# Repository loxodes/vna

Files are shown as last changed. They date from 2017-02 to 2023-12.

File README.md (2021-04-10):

# Open Hardware Vector Network Analyzer
I'm developing a proof of concept two port microwave vector network analyzer. The project is under developent.
[Ongoing documentation and logs are located on a hackaday.io project page.](https://hackaday.io/project/26213-vector-network-analyzer)

## Usage
This project is still under development, y'all probably don't want to try reproducing it yet.
Two port measurements to 14 GHz work, a redesign for operation out to 36 GHz is in progress.

## Hardware Design
See `breakouts` and `hardware` for various modules developed for the network analyzer.
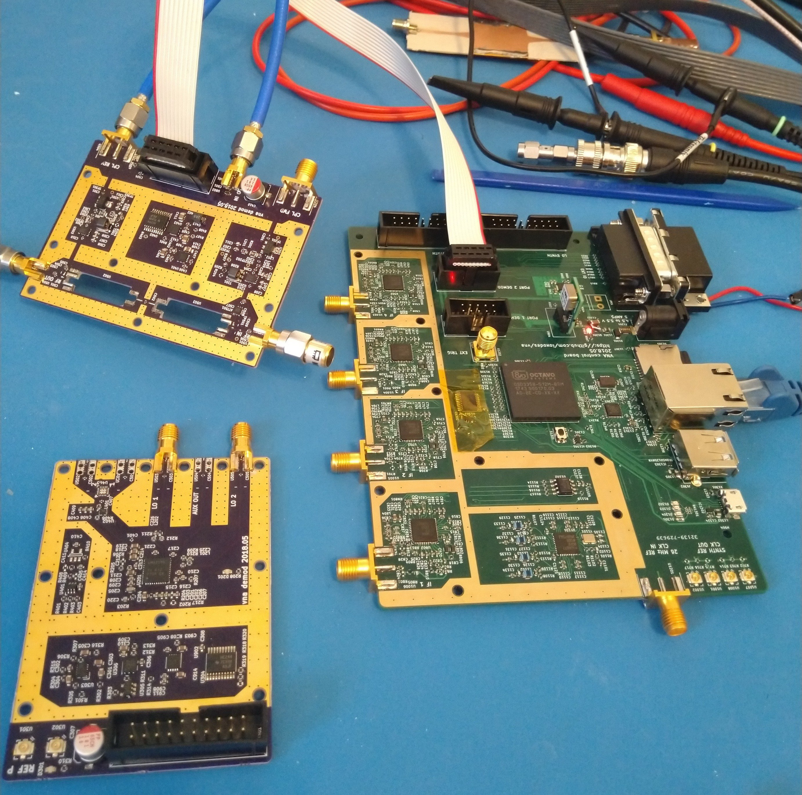
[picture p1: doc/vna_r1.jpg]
picture of VNA R1

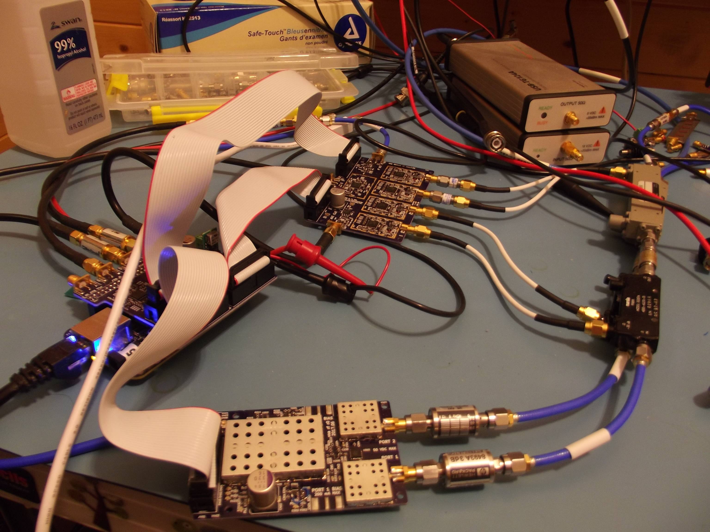
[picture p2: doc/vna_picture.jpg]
picture of VNA

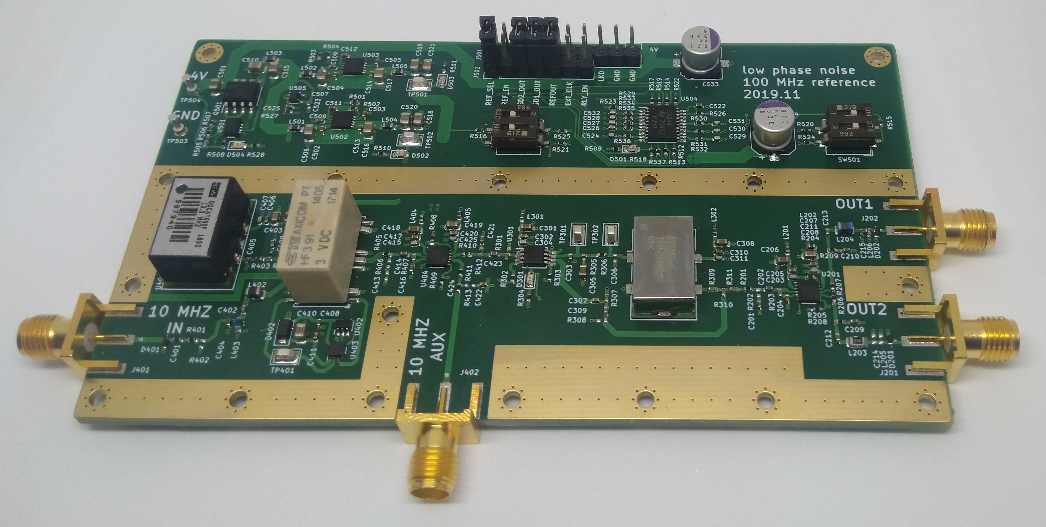
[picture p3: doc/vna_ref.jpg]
picture of VNA reference

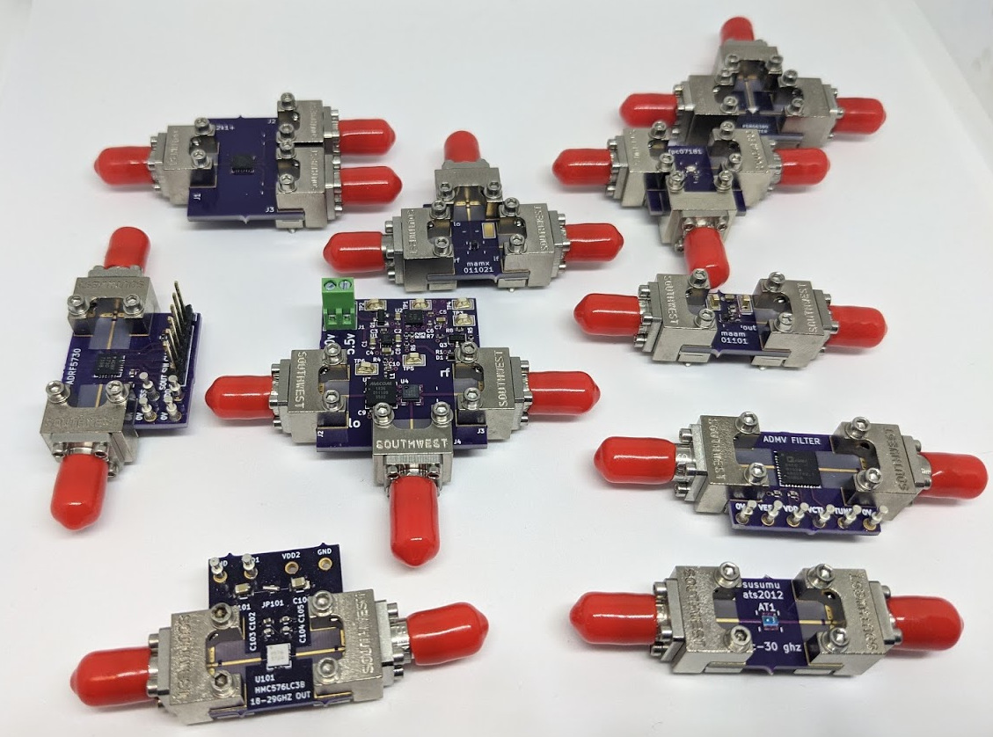
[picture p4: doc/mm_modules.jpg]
picture of mm modules


## Software Design
See the `software` directory for scraps of software written for testing VNA modules. 

## License
Unless otherwise noted, all work is under a MIT license.

## Contact
Feel free to contact me at arcticmicrowave@gmail.com or loxodes on irc.freenode.net

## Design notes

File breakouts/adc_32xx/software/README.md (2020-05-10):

LiteX SoC test platform for ADC32XX ADC and HyperRAM on ECP5\_EVN

On ECP5 EVN,
	Populate R34 and R35 then run https://github.com/trabucayre/fixFT2232\_ecp5evn for serial to work
	Swap R100 and R105 for 3.3V IO

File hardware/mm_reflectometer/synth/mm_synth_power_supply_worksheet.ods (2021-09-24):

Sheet: Current Draw, Toplevel
+5.5V | Current (mA) | Regulator Type |  | TODO:
5VA | 642.523 | Linear |  | -Add test points for CFG0..2 pins on FPGA
-5V35 | 173.02 | Linear |  | -See ECP5 checklist, recommendations for pullup/down on PROGRAMN
LM3880MF-1AF |  | RF regulator sequencing
SYZYGY | 500
Total: | 1315.543 | mA
 | 7235.4865 | mW
+4V | Current (mA) | Regulator Type
+3.3P | 697 | Linear
+3.3VA | 209.876 | Linear
+15V | 0 | Switching
LM3880MF-1AF |  | Control regulator sequencing
+1V1 | 211.75 | Switching
+3V3 | 501.703125 | Switching
Total | 1620.329125 | mA
 | 6481.3165 | mW
+9V
 | Current (mA) | Efficiency | 9V Current (mA)
+4V | 1315.543 | 0.9 | 649.650864197531
+5.5V | 1620.329125 | 0.9 | 1100.22347993827
Total | 1749.8743441358 | mA
Power | 15748.8690972222 | mW
So, total current 2A
Total power 18W

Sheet: Current Draw, Digital
+3V3 |  | TLV62569DRL, switching off +4V
 | current (mA) | notes
TLV0025 | 67 | +2.5V
TLV0018 | 60.5 | +1.8V
PMOD1 | 100
PMOD2 | 100
ECP5 VCCIO7 | 0.5 | Static power, TBD dynamic
ECP5 VCCIO1 | 0.5 | Static power, TBD dynamic
ECP5 VCCIO8 | 0.5 | Static power, TBD dynamic
ECP5 VCCIO2 | 0.5 | Static power, TBD dynamic
93LC56C | 2
W25Q32JVSS | 25
FTDI2232HQ VCCIO, VPHY, VPLL | 130
Total: | 486.5
+1V1 |  | TLV62569DRL, switching off +4V
 | current (mA) | notes
ECP5 Vcc, Static | 116 | Static power, -45F sized max
ECP5 Vcc, Dynamic | 500 | TBD
Total: | 616
+2V5 |  | TLV70025_SOT353, linear off +3.3V
 | current (mA) | notes
ECP5 VCCAUX | 17 | Static power, -45F sized max
 | 50 | TBD
Total: | 67
+1V8 |  | TLV70025_SOT353, linear off +1.8V
 | current (mA) | notes
IS66WVH16M8ALL | 60 | max active read/write current
VCCIO6 | 0.5 | TBD dynamic
Total: | 60.5
VCC_SZY
 | 750

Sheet: Current Draw, RF
+3.3P |  | ADP7158ACPZ-3.3-R7, linear off +4V
 | current (mA) | notes
ABLNO-100 | 35 | switched off by REF_EN
LMX2820 | 590 | varies with mode of operation, 590 mA max typical
LTC6957xMS-2 | 72
Total: | 697
+3.3VA |  | ADP7158ACPZ-3.3-R7, linear off +4V
 | current (mA) | notes
MAAM-11026 | 76 | lowband
MAAM-011101 | 45 | midband
MAAM-011101 | 45 | higband
ADRF5730 | 0.5
TLV9151IDCKR | 1 | pll buffer
LMT86DCK | 1
AD7298 | 6
ADRF5042 | 0.37
LTC5596 | 35
LMT86DCK | 0.006
Total: | 209.876
5VA |  | ADM7172ACPZ-5.0-R7, linear off +5V
 | current (mA) | notes
ADMV8416 | 1 | midband
ADMV8432 | 1 | highband
XX1000-QT | 265 | highband
MAAM-011109 | 170
MAAM-011109 | 170
TS5A23166 | 1
LTC2636IDE | 1 | dac
TLV9151IDCKR | 0 | stg1 and stg2 output gain adjust dac buffer
1-1462051-2 | 33 | bistable
TMUX6136 | 0.023
DRV8837C | 0.5
Total: | 642.523
-5VA |  | TPS72301DB
 | current (mA) | notes
ADMV8416 | 1 | midband
ADMV8432 | 1 | highband
XX1000-QT | 50 | highband
MAAM-011109 | 50 | output stg1 | TBD
MAAM-011109 | 50 | output stg2 | TBD
TLV9151IDCKR | 5 | output stg1
TLV9151IDCKR | 5 | output stg2
TLV9151IDCKR | 10 | stg1 and stg2 output gain adjust dac buffer
TMUX6136 | 0.02
Total: | 171.02
-3V3 |  | TPS72301DB
 | current (mA) | notes
ADRF5042 | 1
ADRF5730 | 1
Total: | 2
+15V | LT3494, switching off +4V
 | current (mA) | notes
TLV9151IDCKR | TBD | midband filter Vt
TLV9151IDCKR | TBD | highband filter Vt
Total: | 0
-5.35V |  | LM27761, max 250 mA, switching off +5.5V
-3.3V | 2
-5V | 171.02
Total: | 173.02

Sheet: Sequencing
Triggered off PGOOD_SWITCHING
RF Sequencing |  | (sequenced internally) |  | (sequenced internally)
 | ADRF | MAAM-011109 | ADMV | XX1000-QT
3.3VP | 3.3VA | -5V | 5V | -5V
 | -3.3V | 5V | -5V | 5V
 |  |  | 15V
Digital Sequencing, triggered off 15V
1.2V
3.3V, 2.5V, 1.8V
FPGA Reset |  | Sequence 5V before 3.3V
TODO:
Change U1303 VDRIVE from 3.3VA to 3.3V?
Verify digital outputs from RF components to FPGA input sequencing

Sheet: Dropout Calculator
TLV62569DRL Dropout
Vout | 3.3
Iout | 0.5
Rdson | 0.15
Ri | 0.2
Vin_min | 3.475

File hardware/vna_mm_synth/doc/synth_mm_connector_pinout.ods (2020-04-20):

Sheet: J1302
2019.12.25
J1302 Pinout | (SYZYGYish) | All digital IO lines are 3.3V CMOS high impedance unless otherwise noted.
Pin Number | Name | Direction (FPGA) | Description | Notes
1 | SDA | Open collector bidirectional | I2C Data
3 | SCL | Open collector bidirectional | I2C Clock
5 | PLL_SDI | Output | LMX2595 SDI | Data clocked on rising edge of SCK, MSB first
7 | PLL_SCK | Output | LMX2595 SCK
9 | PLL_CE | Output | LMX2595 Chip Enable | Active high
11 | PLL_CSB | Output | LMX2595 Chip Select | Active low
13 | PLL_SDO | Input | LMX2595 SDO | Readback on rising edge of SCK
15 | MAAM_VC_EN | Output | Output driver VVA EN | Active high, enables both MAAM-011109 VVAs
17 | FILT_~SYNC | Output | Filter VT DAC Chip Select | Active low frame sync (CSB)
19 | TBD | TBD | TBD | TBD
21 | FILT_BANDSEL | Output | Midband filter band select | Logic high selects low band (7-12 GHz)
23 | AMP_~SYNC | Output | Driver amp DAC Chip Select | Active low frame sync (CSB)
25 | AMP_~CLR | Output | Async DAC clear input | Low sets VVA and filter VT DACs to default values
27 | TBD | TBD | TBD | TBD
29 | AMP_SCK | Output | DAC SPI Clock
31 | AMP_SDI | Output | DAC SPI Data | Data clocked on falling edge of SCK, MSB first
33 | VPP | Power In | 9V power input | Max draw TBD
35 | VPP | Power In | 9V power input | Max draw TBD
37 | VPP | Power In | 9V power input | Max draw TBD
39 | 3.3VA | Power out | 3.3V power output | Max draw TBD
2 | +5V | Power in | Voltage for resistor ID | Unused
4 | R_GA | Voltage out | Board ID | Unused
6 | ATT_SDI | Output | Attenuator SERIN | Data clocked on rising edge of SCK, MSB first
8 | ATT_SCK | Output | Attenuator SCK
10 | ATT_LE | Output | Attenuator Latch | Pulse latch enable high following byte
12 | ATT_SDO | Input | Attenuator SEROUT | Remove and relegate to test point?
14 | SEQ_WP | Output | Write protect sequencing chip | Write protect disabled when WP is pulled to ground
16 | LOWBAND_EN | Output | Enable lowband amplifier | High enables amplifier.
18 | MIDBAND_EN | Output | Enable midband amplifier | High enables amplifier.
20 | HIGHBAND_EN | Output | Enable highband multiplier | High enables multiplier.
22 | SEQ_POW_ON | Output | LTC2937 ON | High enables amplifier.
24 | SW1_V1 | Output | Mid/high select switch V1 | V12 - 00: NC, 01: Midband, 10: Highband, 11: J701 rf test point
26 | SW1_V2 | Output | Mid/high select switch V2
28 | SW2_V1 | Output | Low/mid select switch V1 | V12 – 00: Midband, 01: Mid filt bypass, 10: lowband, 11: J702 rf test point
30 | SW2_V2 | Output | Low/mid select switch V2
32 | SW3_HIGH_SEL | Output | ADRF5020 CTRL input | High selects mid/lowband, low selects highband
34 | CONN_REF_P | RF Output | LVDS 100 MHz reference
36 | CONN_REF_N | RF Output | LVDS 100 MHz reference
38 | VPP | Power In | 9V power input | Max draw TBD
40 | 3V3 | Power in | No connect | No connect

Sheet: I2C Addresses
vna_mm_synth I2C addresses
 | (7 bit)
Chip | Address | Description | Notes
24LC512 | 0x80 | EEPROM | ADDR is LLL
LTC2937 | 0x44 | Power sequencing | ASEL is ZZZ
LM73 | 0x73 | Temperature sensor | ADDR is L
ADS1115IDGS | 0x72 | ADC (vdet, vtune) | ADDR is L

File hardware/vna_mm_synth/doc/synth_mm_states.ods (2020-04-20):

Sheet: Scratchpad
Program in a sequence, at each frequency:
Section | Field | Bits | Notes
PLL | VCO divider
PLL | A mux/PD | 3
PLL | B mux/PD | 3
PLL | N | 19
PLL | FRAC_NUM | 32
PLL | FRAC_DENOM | 32
PLL | A power | 6 | Output power setting for RfoutA
PLL | B power | 6 | Output power setting for RfoutB
PLL | MASH_ORDER | 3 | Sets MASH order
PLL | MASH_RESET_N | 1 | Set to 0 for integer mode, 1 for fractional
PLL | OUT_ISET | 2 | Output amplifier bias? 0 is maximum power.
PLL | DBLR_IBIAS | 1 | Set to 1572 for f < 15 GHz, and 3115 for f > 15 GHz
PLL | VCO2X_EN | 1 | 0 disables internal doubler, 1 enables doubler
PLL | SEG1_EN | 1 | Enable driver buffer for CHDIV > 2
PLL | CHDIV | 5 | VCO divider value
VVA | MAAM_VC_EN | 1
VVA | U1003 Vc | 10
VVA | U1004 Vc | 10
Filter | Filter band | 1
Filter | Filter vtune | 10
Digital attenuator | Atten value | 7
Switch | SW1 | 2
Switch | SW2 | 2
Switch | SW3 | 1
So, load up default mask for all registers
 |  | 159 | 19.875 | 32 bytes/state?
 |  |  |  | 16384
So, aiming for 1000 points/second.
1 ms/point
100 microseconds PLL lock
switch settling?
amplifier settling?
attenuator settling?
74AHC244 max speed?

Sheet: Initialization
vna_mm_synth program states
Power on
Enable power rails
Wait for sequencing
Initialize VVA
Initialize attenuator
Initialize PLL

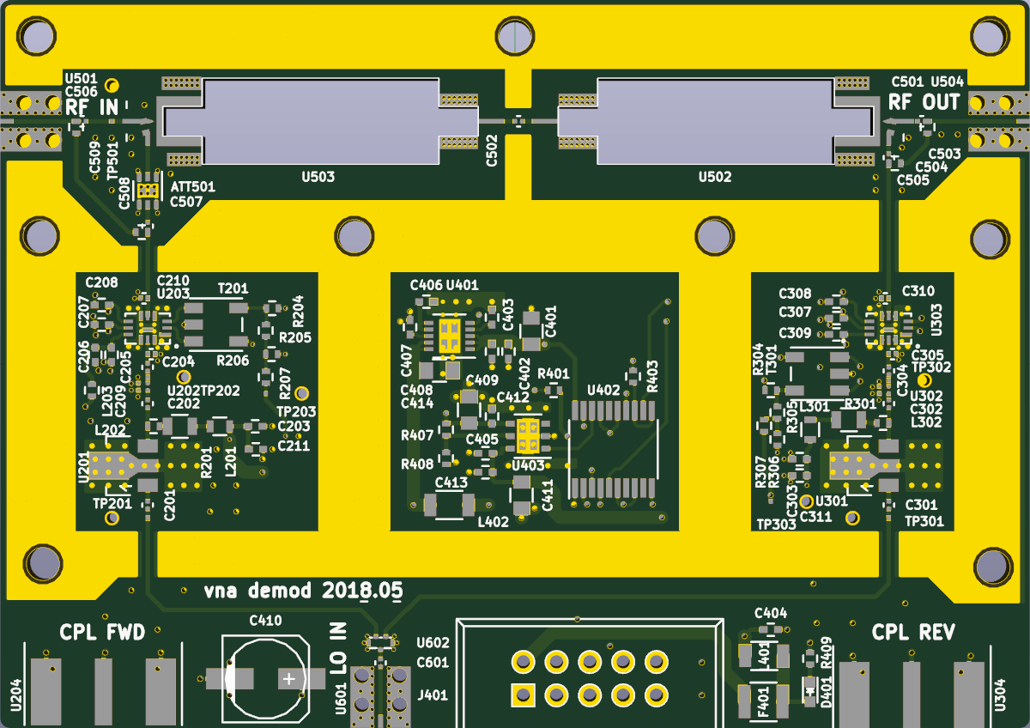
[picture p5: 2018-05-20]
hardware/vna_rev1/vna_r1_demod/vna_r1_demod.png

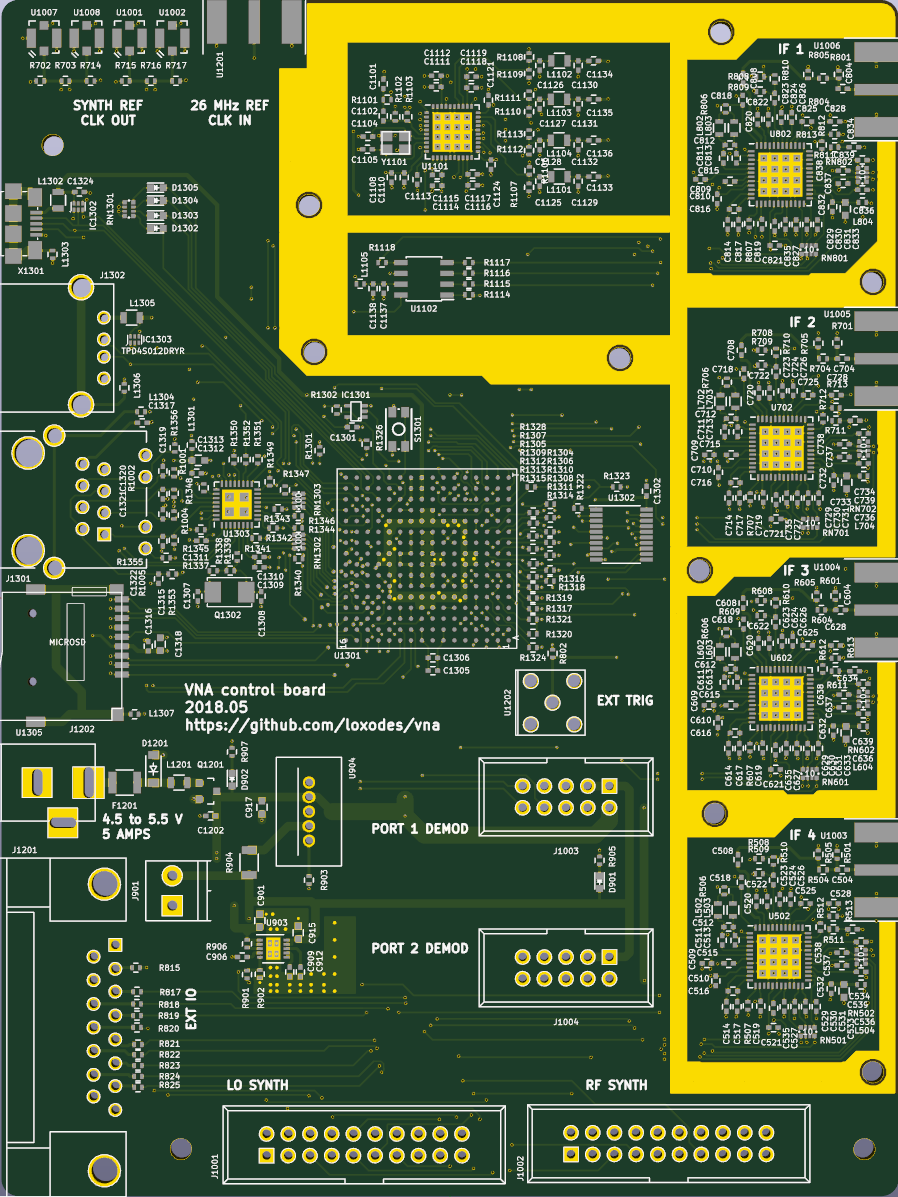
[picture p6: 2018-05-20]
hardware/vna_rev1/vna_r1_controller/vna_r1.png

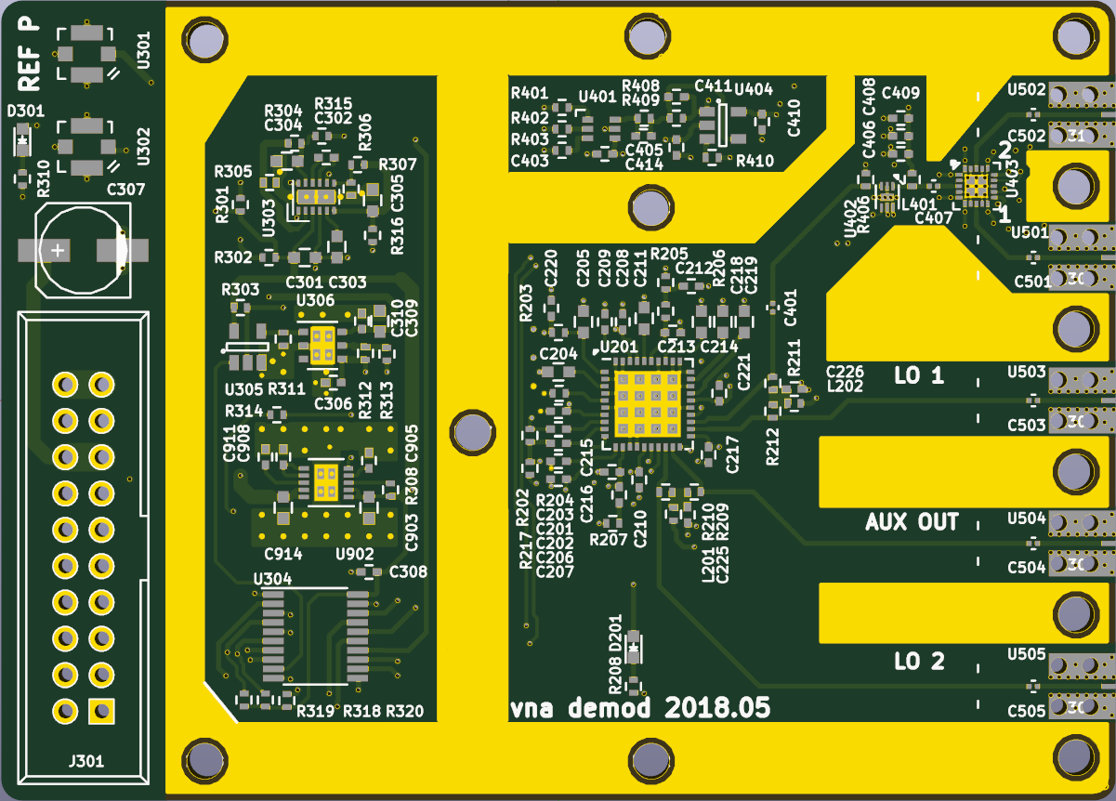
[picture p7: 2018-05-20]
hardware/vna_rev1/vna_r1_synth/vna_r1_synth.png

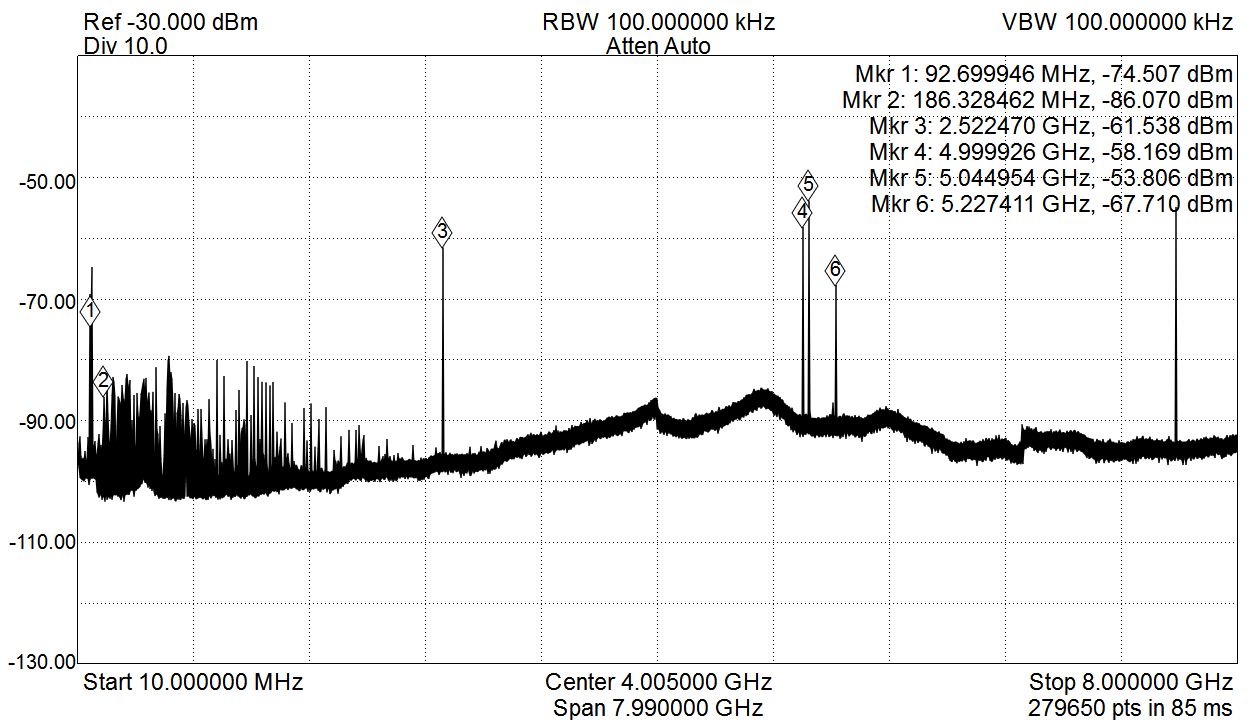
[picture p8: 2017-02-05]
doc/eevblog_forum_pictures/mixer_rf.png

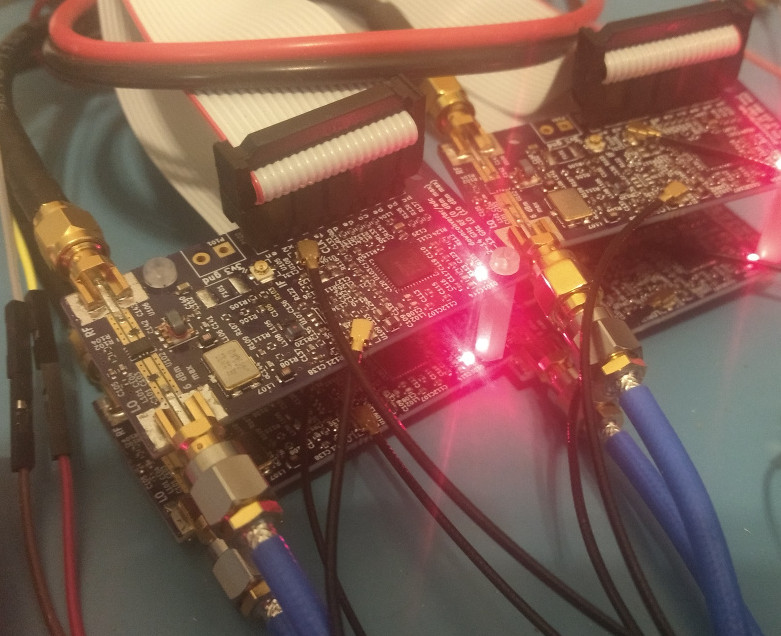
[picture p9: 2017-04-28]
doc/demod.jpg

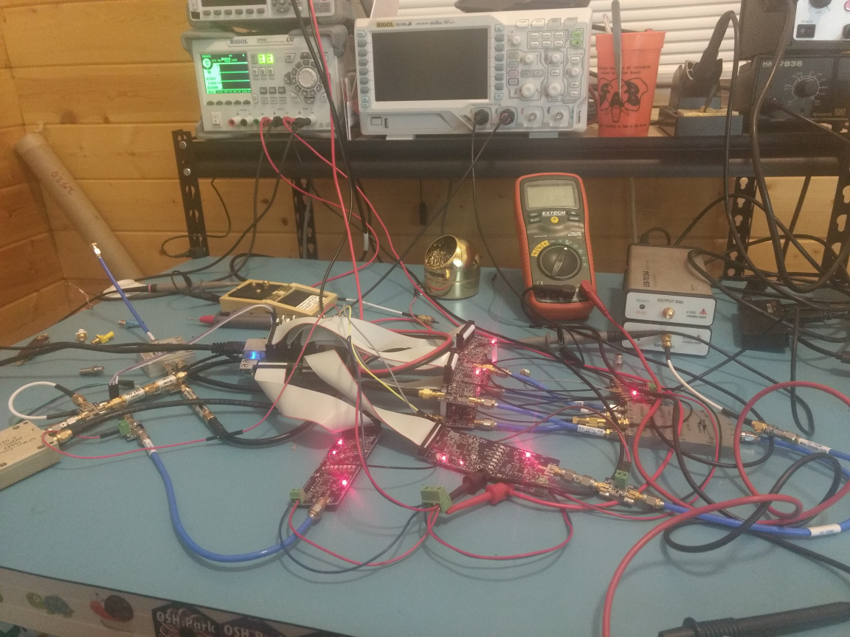
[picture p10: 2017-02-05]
doc/vna_pictures/entire_vna.jpg

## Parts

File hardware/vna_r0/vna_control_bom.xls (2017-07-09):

Item | Qty | Reference(s) | Value | Footprint | Digi-Key Part Number | Board
1 | 23 | C201, C203, C206, C207, C208, C209, C212, C214, C216, C219, C220, C221, C222, C223, C224, C225, C226, C227, C418, C421, C423, C425, C427 | 100 nF | Capacitors_SMD:C_0402 | 490-14603-1-ND | vna_control
2 | 3 | C202, C204, C205 | 22 pF | Capacitors_SMD:C_0402 | 490-8589-1-ND | vna_control
3 | 5 | C210, C211, C215, C217, C218 | 10 nF | Capacitors_SMD:C_0402 | 490-4516-1-ND | vna_control
4 | 1 | C213 | 220 nF | Capacitors_SMD:C_0402 | 490-5418-1-ND | vna_control
5 | 9 | C401, C402, C403, C413, C414, C415, C416, C420, C422 | 10 uF | Capacitors_SMD:C_0603 | 490-10474-1-ND | vna_control
6 | 10 | C404, C405, C406, C407, C408, C409, C410, C411, C412, C424 | 1 uF | Capacitors_SMD:C_0402 | 490-13339-1-ND | vna_control
7 | 1 | C426 | 100 pF | Capacitors_SMD:C_0402 | 490-5922-1-ND | vna_control
8 | 1 | C428 | 100 uF | Capacitors_SMD:c_elec_10x10 | P16463CT-ND | vna_control
9 | 2 | D301, D302 | LED | LEDs:LED_0603 | 475-2486-1-ND | vna_control
10 | 1 | F301 | PTC/MF-NSMF200-2 | Resistors_SMD:R_1206 | MF-NSMF200-2CT-ND | vna_control
11 | 3 | J301, J302, J303 | CONN_02X10 | Connect:IDC_Header_Straight_20pins | 1175-1612-ND | vna_control
11 | 3 | J301, J302, J303 | CONN_02X10 | Connect:IDC_Header_Straight_20pins | 1175-1422-ND | vna_control
11 | 1 | J301, J302, J303 | CONN_02X10 | Connect:IDC_Header_Straight_20pins | MD20R-5-ND | vna_control
12 | 2 | J304, J306 | CONN_02X23 | Pin_Headers:Pin_Header_Straight_2x23 | S2011EC-23-ND | vna_control
13 | 2 | J305, J401 | CONN_01X02 | Terminal_Blocks:TerminalBlock_Pheonix_PT-3.5mm_2pol | 277-1721-ND | vna_control
14 | 1 | J307 | BARREL_JACK | Connect:BARREL_JACK | CP-002A-ND | vna_control
14 | 1 | J307 | BARREL_JACK | Connect:BARREL_JACK | 62-1244-ND | vna_control
15 | 2 | L201, L401 | L_Small | Resistors_SMD:R_0805 | P0.0ACT-ND | vna_control
16 | 1 | Q301 | DMG2305UX | TO_SOT_Packages_SMD:SOT-23 | DMG2305UX-13 | vna_control
17 | 1 | R201 | 51 | Resistors_SMD:R_0402 | 311-2189-1-ND | vna_control
18 | 15 | R202, R203, R204, R205, R206, R207, R208, R209, R210, R211, R216, R217, R218, R405, R406 | 10k | Resistors_SMD:R_0402 | 311-10KJRCT-ND | vna_control
19 | 6 | R212, R213, R214, R215, R301, R302 | DNP | Resistors_SMD:R_0402 | DNP | vna_control
20 | 3 | R303, R401, R402 | R_Small | Resistors_SMD:R_0402 | 1276-3480-1-ND | vna_control
21 | 2 | R304, R305 | 1k | Resistors_SMD:R_0402 | 311-1.0KJRCT-ND | vna_control
22 | 1 | R403 | 390 | Resistors_SMD:R_0402 | 311-390JRCT-ND | vna_control
23 | 1 | R404 | R_Small | Resistors_SMD:R_1206 | MF-NSMF200-2CT-ND | vna_control
24 | 1 | U201 | AD9577 | Housings_DFN_QFN:QFN-40-1EP_6x6mm_Pitch0.5mm | AD9577BCPZ-R7 | vna_control
25 | 1 | U202 | CONN_SMA_2GND | vna_footprints:734120110_ufl_umc | WM5587CT-ND | vna_control
26 | 5 | U301, U302, U303, U304, U305 | CONN_SMA | vna_footprints:732511150_sma_thin | WM5534-ND | vna_control
27 | 3 | U401, U402, U403 | ADP7158 | Housings_DFN_QFN:DFN-10-1EP_3x3mm_Pitch0.5mm | ADP7158ACPZ-3.3-R7CT-ND | vna_control
28 | 1 | U404 | OKR-T/3-W12-C | vna_footprints:OKRT3_C72 | 811-2115-5-ND | vna_control
29 | 1 | U405 | TPS2041B | TO_SOT_Packages_SMD:SOT-23-5 | 296-21263-1-ND | vna_control
30 | 1 | U406 | LTC1983 | TO_SOT_Packages_SMD:SOT-23-6 | LTC1983ES6-5#TRMPBFCT-ND | vna_control
31 | 1 | Y201 | 26 MHz 7M-26.000MEEQ-T | vna_footprints:crystal_FA238-TSX3225 | 887-1327-1-ND | vna_control

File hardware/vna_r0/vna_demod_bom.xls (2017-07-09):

Item | Qty | Reference(s) | Value | Footprint | Digi-Key Part Number | Board
1 | 58 | C201, C215, C303, C307, C308, C316, C317, C318, C319, C320, C323, C325, C326, C327, C329, C503, C507, C508, C516, C517, C518, C519, C520, C523, C525, C526, C527, C529, C603, C607, C608, C616, C617, C618, C619, C620, C623, C625, C626, C627, C629, C703, C707, C708, C716, C717, C718, C719, C720, C723, C725, C726, C727, C729, C801, C803, C806, C807 | 100 nF | Capacitors_SMD:C_0402 | 490-14603-1-ND | vna_demod
2 | 7 | C202, C204, C205, C206, C207, C209, C218 | 1 uF | Capacitors_SMD:C_0402 | 490-13339-1-ND | vna_demod
3 | 9 | C203, C208, C212, C216, C217, C328, C528, C628, C728 | 10 uF | Capacitors_SMD:C_0603 | 490-10474-1-ND | vna_demod
4 | 1 | C210 | DNP | Capacitors_SMD:C_0402 | DNP | vna_demod
5 | 1 | C211 | 1800 pF | Capacitors_SMD:C_0402 | 490-12535-1-ND | vna_demod
6 | 1 | C213 | 390 pF | Capacitors_SMD:C_0402 | 490-5871-1-ND | vna_demod
7 | 1 | C214 | 68 nF | Capacitors_SMD:C_0402 | 490-12709-1-ND | vna_demod
8 | 25 | C219, C220, C304, C306, C314, C321, C322, C504, C506, C514, C521, C522, C604, C606, C614, C621, C622, C704, C706, C714, C721, C722, C802, C804, C805 | 10 nF | Capacitors_SMD:C_0402 | 490-4516-1-ND | vna_demod
9 | 12 | C301, C302, C305, C501, C502, C505, C601, C602, C605, C701, C702, C705 | 10 pF | Capacitors_SMD:C_0402 | 712-1253-1-ND | vna_demod
10 | 16 | C309, C311, C312, C315, C509, C511, C512, C515, C609, C611, C612, C615, C709, C711, C712, C715 | 100 pF | Capacitors_SMD:C_0402 | 490-5922-1-ND | vna_demod
11 | 4 | C310, C510, C610, C710 | 120 pF | Capacitors_SMD:C_0402 | 490-1292-1-ND | vna_demod
12 | 4 | C313, C513, C613, C713 | 2.2 nF | Capacitors_SMD:C_0402 | 490-1305-1-ND | vna_demod
13 | 4 | C324, C524, C624, C724 | 1 nF | Capacitors_SMD:C_0402 | 490-1303-1-ND | vna_demod
14 | 1 | C402 | 22 uF | Capacitors_SMD:c_elec_10x10 | P16463CT-ND | vna_demod
15 | 3 | D201, D401, D402 | RED | LEDs:LED_0603 | 475-2486-1-ND | vna_demod
16 | 4 | H401, H402, H403, H404 | MOUNTING_HOLE | Mounting_Holes:MountingHole_2-7mm | DNP | vna_demod
17 | 5 | J301, J501, J601, J701, J201 | BMI-S-209 | Shielding_Cabinets:Laird_Technologies_BMI-S-209-F_29.36x18.50mm | 903-1185-ND | vna_demod
18 | 5 | J301, J501, J601, J701, J201 | BMI-S-209 | Shielding_Cabinets:Laird_Technologies_BMI-S-209-F_29.36x18.50mm | 903-1212-1-ND | vna_demod
19 | 2 | J401, J402 | CONN_02X10 | Connect:IDC_Header_Straight_20pins | 1175-1612-ND | vna_demod
20 | 2 | J401, J402 | CONN_02X10 | Connect:IDC_Header_Straight_20pins | 1175-1422-ND | vna_demod
21 | 2 | J403, J404 | CONN_01X01 | Pin_Headers:Pin_Header_Straight_1x01 | DNP | vna_demod
22 | 2 | L201, L202 | 22 nH | Resistors_SMD:R_0402 | 490-6787-1-ND | vna_demod
23 | 8 | L301, L304, L501, L504, L601, L604, L701, L704 | BLM15GG471 | Resistors_SMD:R_0402 | 490-5198-1-ND | vna_demod
24 | 8 | L302, L303, L502, L503, L602, L603, L702, L703 | 6.8 uH BRL1608T6R8M | Resistors_SMD:R_0603 | 587-2902-1-ND | vna_demod
25 | 1 | L801 | 6.8 uH | Resistors_SMD:R_0603 | 587-2902-1-ND | vna_demod
26 | 50 | R201, R202, R205, R206, R207, R209, R210, R302, R303, R308, R309, R310, R311, R312, R313, R314, R315, R401, R402, R502, R503, R508, R509, R510, R511, R512, R513, R514, R515, R602, R603, R608, R609, R610, R611, R612, R613, R614, R615, R702, R703, R708, R709, R710, R711, R712, R713, R714, R715, R810 | 1k | Resistors_SMD:R_0402 | 311-1.0KJRCT-ND | vna_demod
27 | 5 | R203, R316, R516, R616, R716 | JMP | Resistors_SMD:R_0402 | 1276-3480-1-ND | vna_demod
28 | 1 | R204 | 18 | Resistors_SMD:R_0402 | 311-18JRCT-ND | vna_demod
29 | 1 | R208 | 68 | Resistors_SMD:R_0402 | 311-68JRCT-ND | vna_demod
30 | 9 | R211, R212, R213, R214, R306, R506, R606, R706, R813 | 51 | Resistors_SMD:R_0402 | 311-2189-1-ND | vna_demod
31 | 12 | R301, R317, R403, R501, R517, R601, R617, R701, R717, R807, R808, R809 | DNP | Resistors_SMD:R_0402 | DNP | vna_demod
32 | 4 | R304, R504, R604, R704 | 470 nH | Resistors_SMD:R_0402 | 445-15692-1-ND | vna_demod
33 | 4 | R305, R505, R605, R705 | 22 pF | Resistors_SMD:R_0402 | 490-8589-1-ND | vna_demod
34 | 4 | R307, R507, R607, R707 | 100k | Resistors_SMD:R_0402 | 311-2127-1-ND | vna_demod
35 | 2 | R801, R806 | 39 pF | Resistors_SMD:R_0402 | 490-9663-1-ND | vna_demod
36 | 3 | R802, R811, R812 | 10k | Resistors_SMD:R_0402 | 311-10KJRCT-ND | vna_demod
37 | 2 | R803, R805 | 270 nH | Resistors_SMD:R_0402 | 445-3076-1-ND | vna_demod
38 | 1 | R804 | 150 pF | Resistors_SMD:R_0402 | 490-8185-1-ND | vna_demod
39 | 5 | R814, R815, R816, R817, R818 | 450 | Resistors_SMD:R_0402 | YAG3165CT-ND | vna_demod
40 | 4 | R819, R820, R821, R822 | 30 | Resistors_SMD:R_0402 | 311-30JRCT-ND | vna_demod
41 | 4 | T301, T501, T601, T701 | Transformer_SP_1S | vna_footprints:5LEAD_BALUN_4p83mm_3p3mm | 1465-1317-1-ND | vna_demod
42 | 1 | U201 | LMX2594 | Housings_DFN_QFN:QFN-40-1EP_6x6mm_Pitch0.5mm | 296-46560-1-ND | vna_demod
43 | 4 | U301, U501, U601, U701 | LTC5549 | vna_footprints:QFN_12_3mm2mm | LTC5548IUDB#TRMPBFCT-ND | vna_demod
44 | 4 | U302, U502, U602, U702 | ad9864 | Housings_DFN_QFN:QFN-48-1EP_7x7mm_Pitch0.5mm | AD9864BCPZRLCT-ND | vna_demod
45 | 3 | U401, U402, U403 | CONN_SMA | vna_footprints:732511150_sma_thin | WM5534-ND | vna_demod
46 | 4 | U404, U405, U406, U407 | CONN_SMA_2GND | vna_footprints:SMA_901-10512_30MIL_OSHFR408_CPW_LAUNCH | ARF2503-ND | vna_demod
47 | 1 | U408 | mounting_box | vna_footprints:snail | DNP | vna_demod
48 | 1 | U801 | TXCO | vna_footprints:crystal_FA238-TSX3225 | 535-12047-1-ND | vna_demod
49 | 1 | U802 | TRF37B73 | Housings_DFN_QFN:DFN-8-1EP_2x2mm_Pitch0.5mm | 296-38825-1-ND | vna_demod
50 | 1 | U803 | NB3N551 | Housings_SOIC:SOIC-8_3.9x4.9mm_Pitch1.27mm | NB3N551DR2GOSCT-ND | vna_demod

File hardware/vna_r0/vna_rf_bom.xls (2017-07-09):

Item | Qty | Reference(s) | Value | Footprint | Digi-Key Part Number | Board
1 | 11 | C201, C215, C225, C226, C227, C228, C233, C237, C301, C302, C303 | 100 nF | Capacitors_SMD:C_0402 | 490-14603-1-ND | vna_rf_r0
2 | 7 | C202, C204, C205, C206, C207, C209, C218 | 1 uF | Capacitors_SMD:C_0402 | 490-13339-1-ND | vna_rf_r0
3 | 7 | C203, C208, C210, C216, C217, C401, C403 | 10 uF | Capacitors_SMD:C_0603 | 490-10474-1-ND | vna_rf_r0
4 | 1 | C211 | 390 pF | Capacitors_SMD:C_0402 | 490-5871-1-ND | vna_rf_r0
5 | 1 | C212 | 68 nF | Capacitors_SMD:C_0402 | 490-12709-1-ND | vna_rf_r0
6 | 3 | C213, C229, C231 | DNP | Capacitors_SMD:C_0402 | DNP | vna_rf_r0
7 | 1 | C214 | 1800 pF | Capacitors_SMD:C_0402 | 490-12535-1-ND | vna_rf_r0
8 | 2 | C219, C220 | 10 nF | Capacitors_SMD:C_0402 | 490-4516-1-ND | vna_rf_r0
9 | 13 | C221, C222, C223, C224, C230, C235, C236, C304, C305, C306, C307, C309, C311 | 10 pF | Capacitors_SMD:C_0402 | 712-1253-1-ND | vna_rf_r0
10 | 2 | C232, C234 | 220 nF | Capacitors_SMD:C_0402 | 490-5418-1-ND | vna_rf_r0
11 | 2 | C308, C310 | 1 uF | Capacitors_SMD:C_0805 | 490-14440-1-ND | vna_rf_r0
12 | 1 | C402 | 100 uF | Capacitors_SMD:c_elec_10x10 | P16463CT-ND | vna_rf_r0
13 | 3 | D201, D202, D203 | LED_Small | LEDs:LED_0603 | 475-2486-1-ND | vna_rf_r0
14 | 1 | D301 | 5.1V | Diodes_SMD:SOD-323 | BZT52C5V1S-FDICT-ND | vna_rf_r0
15 | 1 | D302 | LED | LEDs:LED_0603 | 475-2486-1-ND | vna_rf_r0
16 | 3 | D401, D402, D403 | RED | LEDs:LED_0603 | 475-2486-1-ND | vna_rf_r0
17 | 1 | FL201 | 5515LP15A730 | vna_footprints:5515LP15A730 | 712-1135-1-ND | vna_rf_r0
18 | 1 | FL202 | 1810LP07A200 | vna_footprints:1810LP07A200 | 712-1124-1-ND | vna_rf_r0
19 | 1 | FL203 | 3550LP14A300 | vna_footprints:3550LP14A300 | 712-1134-1-ND | vna_rf_r0
20 | 4 | H401, H402, H403, H404 | MOUNTING_HOLE | Mounting_Holes:MountingHole_2-7mm | DNP | vna_rf_r0
21 | 2 | J301, J302 | RF_Shield_Two_Pieces | Shielding_Cabinets:Laird_Technologies_BMI-S-202-F_16.50x16.50mm | 903-1051-1-ND | vna_rf_r0
22 | 2 | J301, J302 | RF_Shield_Two_Pieces | Shielding_Cabinets:Laird_Technologies_BMI-S-202-F_16.50x16.50mm | 903-1014-ND | vna_rf_r0
23 | 1 | J401 | CONN_02X10 | Connect:IDC_Header_Straight_20pins | 1175-1422-ND | vna_rf_r0
24 | 1 | J401 | CONN_02X10 | Connect:IDC_Header_Straight_20pins | 1175-1612-ND | vna_rf_r0
25 | 1 | J402 | RF_Shield_Two_Pieces | Shielding_Cabinets:Laird_Technologies_BMI-S-205-F_38.10x25.40mm | 903-1017-ND | vna_rf_r0
26 | 1 | J402 | RF_Shield_Two_Pieces | Shielding_Cabinets:Laird_Technologies_BMI-S-205-F_38.10x25.40mm | 903-1054-1-ND | vna_rf_r0
27 | 1 | L201, L202 | 22 nH | Resistors_SMD:R_0402 | 490-6787-1-ND | vna_rf_r0
28 | 1 | L203 | BLM15GG471 | Resistors_SMD:R_0402 | 490-5198-1-ND | vna_rf_r0
29 | 2 | L301, L302 | 506WLSN6R00KT236T | vna_footprints:ATC506WLS | 490-5198-1-ND | vna_rf_r0
30 | 22 | R201, R202, R205, R206, R207, R209, R214, R215, R216, R217, R218, R225, R226, R228, R229, R301, R302, R305, R306, R401, R402, R403 | 1k | Resistors_SMD:R_0402 | 311-1.0KJRCT-ND | vna_rf_r0
31 | 1 | R203 | JMP | Resistors_SMD:R_0402 | 1276-3480-1-ND | vna_rf_r0
32 | 1 | R204 | 18 | Resistors_SMD:R_0402 | 311-18JRCT-ND | vna_rf_r0
33 | 1 | R208 | 68 | Resistors_SMD:R_0402 | 311-68JRCT-ND | vna_rf_r0
34 | 6 | R210, R211, R212, R213, R307, R308 | 51 | Resistors_SMD:R_0402 | 311-2189-1-ND | vna_rf_r0
35 | 1 | R219 | 3k | Resistors_SMD:R_0402 | YAG1428CT-ND | vna_rf_r0
36 | 1 | R220 | 2.4k | Resistors_SMD:R_0402 | YAG4232CT-ND | vna_rf_r0
37 | 2 | R221, R230 | 68k | Resistors_SMD:R_0402 | 311-2309-1-ND | vna_rf_r0
38 | 2 | R222, R227 | 100k | Resistors_SMD:R_0402 | 311-2127-1-ND | vna_rf_r0
39 | 1 | R223 | 2k | Resistors_SMD:R_0402 | YAG2303CT-ND | vna_rf_r0
40 | 1 | R224 | 18k | Resistors_SMD:R_0402 | YAG4184CT-ND | vna_rf_r0
41 | 1 | R231 | 9.1k | Resistors_SMD:R_0402 | YAG1496CT-ND | vna_rf_r0
42 | 1 | R232 | 4.7k | Resistors_SMD:R_0402 | YAG1446CT-ND | vna_rf_r0
43 | 2 | R303, R304 | 100 | Resistors_SMD:R_0402 | 311-100LRCT-ND | vna_rf_r0
44 | 1 | R404 | DNP | Resistors_SMD:R_0402 | DNP | vna_rf_r0
45 | 1 | U201 | LMX2594 | Housings_DFN_QFN:QFN-40-1EP_6x6mm_Pitch0.5mm | 296-46560-1-ND | vna_rf_r0
46 | 1 | U202 | LTC2630 | TO_SOT_Packages_SMD:SC-70-6 | LTC2630ISC6-HZ10#TRMPBFCT-ND | vna_rf_r0
47 | 1 | U203 | ADRF5040 | Housings_DFN_QFN:QFN-24-1EP_4x4mm_Pitch0.5mm | ADRF5040BCPZ-ND | vna_rf_r0
48 | 1 | U204 | LTC2054CS5 | TO_SOT_Packages_SMD:SOT-23-5 | LTC2054CS5#TRMPBFCT-ND | vna_rf_r0
49 | 1 | U205 | MAAM-011100 | vna_footprints:TDFN6 | 1465-1282-1-ND | vna_rf_r0
50 | 1 | U301 | NC7WZU04 | TO_SOT_Packages_SMD:SC-70-6 | NC7WZU04P6CT-ND | vna_rf_r0
51 | 2 | U302, U304 | PE42521 | Housings_DFN_QFN:QFN-16-1EP_3x3mm_Pitch0.5mm | 1046-1088-1-ND | vna_rf_r0
52 | 1 | U303 | MASW-008322-TR1000 | Housings_DFN_QFN:QFN-24-1EP_4x4mm_Pitch0.5mm | 1465-1362-1-ND | vna_rf_r0
53 | 2 | U401, U402 | CONN_SMA_2GND | vna_footprints:SMA_901-10512_30MIL_OSHFR408_CPW_LAUNCH | ARF2503-ND | vna_rf_r0
54 | 3 | U403, U404, U405 | CONN_SMA | vna_footprints:732511150_sma_thin | WM5534-ND | vna_rf_r0
55 | 1 | U406 | CONN_SMA_2GND | vna_footprints:734120110_ufl_umc | WM5587CT-ND | vna_rf_r0

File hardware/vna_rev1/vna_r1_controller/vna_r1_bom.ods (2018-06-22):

/home/kleinjt/repos/vna/hardware/vna_r1/vna_r1.sch
Mon May 7 20:47:03 2018
Eeschema 4.0.7
/usr/local/share/doc/kicad/scripts/bom-in-python/bom_csv_grouped_by_value.py
439
Qty | Value | Footprint | Datasheet
 | 10 nF | Capacitors_SMD:C_0402
 | 10 nF | Capacitors_SMD:C_0402
 | 100 nF | Capacitors_SMD:C_0402
 | 100 nF | Capacitors_SMD:C_0402
 | 100 pF | Capacitors_SMD:C_0402
 | 120 pF | Capacitors_SMD:C_0402
 | 100 pF | Capacitors_SMD:C_0402
 | 100 pF | Capacitors_SMD:C_0402
 | 2.2 nF | Capacitors_SMD:C_0402
 | 10 nF | Capacitors_SMD:C_0402
 | 100 pF | Capacitors_SMD:C_0402
 | 100 nF | Capacitors_SMD:C_0402
 | 100 nF | Capacitors_SMD:C_0402
 | 100 nF | Capacitors_SMD:C_0402
 | 100 nF | Capacitors_SMD:C_0402
 | 100 nF | Capacitors_SMD:C_0402
 | 10 nF | Capacitors_SMD:C_0402
 | 10 nF | Capacitors_SMD:C_0402
 | 100 nF | Capacitors_SMD:C_0402
 | 1 nF | Capacitors_SMD:C_0402
 | 100 nF | Capacitors_SMD:C_0402
 | 100 nF | Capacitors_SMD:C_0402
 | 10 pF | Capacitors_SMD:C_0402
 | 10 pF | Capacitors_SMD:C_0402
 | 10 pF | Capacitors_SMD:C_0402
 | 100 nF | Capacitors_SMD:C_0402
 | 10 uF | Capacitors_SMD:C_0603
 | 10 pF | Capacitors_SMD:C_0402
 | 100 nF | Capacitors_SMD:C_0402
 | 10 pF | Capacitors_SMD:C_0402
 | 10 pF | Capacitors_SMD:C_0402
 | 10 pF | Capacitors_SMD:C_0402
 | 10 pF | Capacitors_SMD:C_0402
 | 10 nF | Capacitors_SMD:C_0402
 | 10 nF | Capacitors_SMD:C_0402
 | 100 nF | Capacitors_SMD:C_0402
 | 100 nF | Capacitors_SMD:C_0402
 | 100 pF | Capacitors_SMD:C_0402
 | 120 pF | Capacitors_SMD:C_0402
 | 100 pF | Capacitors_SMD:C_0402
 | 100 pF | Capacitors_SMD:C_0402
 | 2.2 nF | Capacitors_SMD:C_0402
 | 10 nF | Capacitors_SMD:C_0402
 | 100 pF | Capacitors_SMD:C_0402
 | 100 nF | Capacitors_SMD:C_0402
 | 100 nF | Capacitors_SMD:C_0402
 | 100 nF | Capacitors_SMD:C_0402
 | 100 nF | Capacitors_SMD:C_0402
 | 100 nF | Capacitors_SMD:C_0402
 | 10 nF | Capacitors_SMD:C_0402
 | 10 nF | Capacitors_SMD:C_0402
 | 100 nF | Capacitors_SMD:C_0402
 | 1 nF | Capacitors_SMD:C_0402
 | 100 nF | Capacitors_SMD:C_0402
 | 100 nF | Capacitors_SMD:C_0402
 | 10 pF | Capacitors_SMD:C_0402
 | 10 pF | Capacitors_SMD:C_0402
 | 10 pF | Capacitors_SMD:C_0402
 | 100 nF | Capacitors_SMD:C_0402
 | 10 uF | Capacitors_SMD:C_0603
 | 10 pF | Capacitors_SMD:C_0402
 | 100 nF | Capacitors_SMD:C_0402
 | 10 pF | Capacitors_SMD:C_0402
 | 10 pF | Capacitors_SMD:C_0402
 | 10 pF | Capacitors_SMD:C_0402
 | 10 pF | Capacitors_SMD:C_0402
 | 10 nF | Capacitors_SMD:C_0402
 | 10 nF | Capacitors_SMD:C_0402
 | 100 nF | Capacitors_SMD:C_0402
 | 100 nF | Capacitors_SMD:C_0402
 | 100 pF | Capacitors_SMD:C_0402
 | 120 pF | Capacitors_SMD:C_0402
 | 100 pF | Capacitors_SMD:C_0402
 | 100 pF | Capacitors_SMD:C_0402
 | 2.2 nF | Capacitors_SMD:C_0402
 | 10 nF | Capacitors_SMD:C_0402
 | 100 pF | Capacitors_SMD:C_0402
 | 100 nF | Capacitors_SMD:C_0402
 | 100 nF | Capacitors_SMD:C_0402
 | 100 nF | Capacitors_SMD:C_0402
 | 100 nF | Capacitors_SMD:C_0402
 | 100 nF | Capacitors_SMD:C_0402
 | 10 nF | Capacitors_SMD:C_0402
 | 10 nF | Capacitors_SMD:C_0402
 | 100 nF | Capacitors_SMD:C_0402
 | 1 nF | Capacitors_SMD:C_0402
 | 100 nF | Capacitors_SMD:C_0402
 | 100 nF | Capacitors_SMD:C_0402
 | 10 pF | Capacitors_SMD:C_0402
 | 10 pF | Capacitors_SMD:C_0402
 | 10 pF | Capacitors_SMD:C_0402
 | 100 nF | Capacitors_SMD:C_0402
 | 10 uF | Capacitors_SMD:C_0603
 | 10 pF | Capacitors_SMD:C_0402
 | 100 nF | Capacitors_SMD:C_0402
 | 10 pF | Capacitors_SMD:C_0402
 | 10 pF | Capacitors_SMD:C_0402
 | 10 pF | Capacitors_SMD:C_0402
 | 10 pF | Capacitors_SMD:C_0402
 | 10 nF | Capacitors_SMD:C_0402
 | 10 nF | Capacitors_SMD:C_0402
 | 100 nF | Capacitors_SMD:C_0402
 | 100 nF | Capacitors_SMD:C_0402
 | 100 pF | Capacitors_SMD:C_0402
 | 120 pF | Capacitors_SMD:C_0402
 | 100 pF | Capacitors_SMD:C_0402
 | 100 pF | Capacitors_SMD:C_0402
 | 2.2 nF | Capacitors_SMD:C_0402
 | 10 nF | Capacitors_SMD:C_0402
 | 100 pF | Capacitors_SMD:C_0402
 | 100 nF | Capacitors_SMD:C_0402
 | 100 nF | Capacitors_SMD:C_0402
 | 100 nF | Capacitors_SMD:C_0402
 | 100 nF | Capacitors_SMD:C_0402
 | 100 nF | Capacitors_SMD:C_0402
 | 10 nF | Capacitors_SMD:C_0402
 | 10 nF | Capacitors_SMD:C_0402
 | 100 nF | Capacitors_SMD:C_0402
 | 1 nF | Capacitors_SMD:C_0402
 | 100 nF | Capacitors_SMD:C_0402
 | 100 nF | Capacitors_SMD:C_0402
 | 10 pF | Capacitors_SMD:C_0402
 | 10 pF | Capacitors_SMD:C_0402
 | 10 pF | Capacitors_SMD:C_0402
 | 100 nF | Capacitors_SMD:C_0402
 | 10 uF | Capacitors_SMD:C_0603
 | 10 pF | Capacitors_SMD:C_0402
 | 100 nF | Capacitors_SMD:C_0402
 | 10 pF | Capacitors_SMD:C_0402
 | 10 pF | Capacitors_SMD:C_0402
 | 10 pF | Capacitors_SMD:C_0402
 | 10 pF | Capacitors_SMD:C_0402
 | 10 uF | Capacitors_SMD:C_0603
 | 1 uF | Capacitors_SMD:C_0402
 | 1 uF | Capacitors_SMD:C_0402
 | 1 uF | Capacitors_SMD:C_0402
 | 10 uF | Capacitors_SMD:C_0603
 | 10 uF | Capacitors_SMD:C_0603
 | 100 nF | Capacitors_SMD:C_0402
 | 22 pF | Capacitors_SMD:C_0402
 | 100 nF | Capacitors_SMD:C_0402
 | 22 pF | Capacitors_SMD:C_0402
 | 22 pF | Capacitors_SMD:C_0402
 | 100 nF | Capacitors_SMD:C_0402
 | 100 nF | Capacitors_SMD:C_0402
 | 100 nF | Capacitors_SMD:C_0402
 | 100 nF | Capacitors_SMD:C_0402
 | 10 nF | Capacitors_SMD:C_0402
 | 10 nF | Capacitors_SMD:C_0402
 | 100 nF | Capacitors_SMD:C_0402
 | 220 nF | Capacitors_SMD:C_0402
 | 100 nF | Capacitors_SMD:C_0402
 | 10 nF | Capacitors_SMD:C_0402
 | 100 nF | Capacitors_SMD:C_0402
 | 10 nF | Capacitors_SMD:C_0402
 | 10 nF | Capacitors_SMD:C_0402
 | 100 nF | Capacitors_SMD:C_0402
 | 100 nF | Capacitors_SMD:C_0402
 | 100 nF | Capacitors_SMD:C_0402
 | 100 nF | Capacitors_SMD:C_0402
 | 100 nF | Capacitors_SMD:C_0402
 | 100 nF | Capacitors_SMD:C_0402
 | 18 pF | Capacitors_SMD:C_0402
 | 18 pF | Capacitors_SMD:C_0402
 | 18 pF | Capacitors_SMD:C_0402
 | 18 pF | Capacitors_SMD:C_0402
 | 120 pF | Capacitors_SMD:C_0402
 | 120 pF | Capacitors_SMD:C_0402
 | 120 pF | Capacitors_SMD:C_0402
 | 120 pF | Capacitors_SMD:C_0402
 | 100 nF | Capacitors_SMD:C_0402
 | 100 nF | Capacitors_SMD:C_0402
 | 100 nF | Capacitors_SMD:C_0402
 | 100 nF | Capacitors_SMD:C_0402
 | 100 nF | Capacitors_SMD:C_0402
 | 1 uF | Capacitors_SMD:C_0402
 | 100 nF | Capacitors_SMD:C_0402
 | 100 nF | Capacitors_SMD:C_0402
 | 100 nF | Capacitors_SMD:C_0402
 | 18 pF | Capacitors_SMD:C_0402
 | 18 pF | Capacitors_SMD:C_0402
 | 100 nF | Capacitors_SMD:C_0402
 | 1 nF | Capacitors_SMD:C_0402
 | 30 pF | Capacitors_SMD:C_0402
 | 30 pF | Capacitors_SMD:C_0402
 | 1 uF | Capacitors_SMD:C_0402
 | 470 pF | Capacitors_SMD:C_0402
 | 100 nF | Capacitors_SMD:C_0402
 | 100 nF | Capacitors_SMD:C_0402
 | 10 uF | Capacitors_SMD:C_0603
 | 100 nF | Capacitors_SMD:C_0402
 | 22 nF | Capacitors_SMD:C_0402
 | 100 nF | Capacitors_SMD:C_0402
 | 22 nF | Capacitors_SMD:C_0402
 | 10 uF | Capacitors_SMD:C_0603
 | 15 pF | Capacitors_SMD:C_0402
 | 15 pF | Capacitors_SMD:C_0402
 | 15 pF | Capacitors_SMD:C_0402
 | 15 pF | Capacitors_SMD:C_0402
 | 100 nF | Capacitors_SMD:C_0402
 | 100 nF | Capacitors_SMD:C_0402
 | LED_Small | LEDs:LED_0603
 | LED_Small | LEDs:LED_0603
 | 5.6V | Diodes_SMD:SOD-123
 | USR0 | LEDs:LED_0603
 | USR1 | LEDs:LED_0603
 | USR2 | LEDs:LED_0603
 | USR3 | LEDs:LED_0603
 | Polyfuse_Small | Resistors_SMD:R_1210
 | MOUNTING_HOLE | Mounting_Holes:MountingHole_2-5mm
 | MOUNTING_HOLE | Mounting_Holes:MountingHole_2-5mm
 | MOUNTING_HOLE | Mounting_Holes:MountingHole_2-5mm
 | MOUNTING_HOLE | Mounting_Holes:MountingHole_2-5mm
 | MOUNTING_HOLE | Mounting_Holes:MountingHole_2-5mm
 | MOUNTING_HOLE | Mounting_Holes:MountingHole_2-5mm
 | MOUNTING_HOLE | Mounting_Holes:MountingHole_2-5mm
 | MOUNTING_HOLE | Mounting_Holes:MountingHole_2-5mm
 | MOUNTING_HOLE | Mounting_Holes:MountingHole_2-5mm
 | MOUNTING_HOLE | Mounting_Holes:MountingHole_2-5mm
 | MOUNTING_HOLE | Mounting_Holes:MountingHole_2-5mm
 | SN74LVC1G07DCK | TO_SOT_Packages_SMD:SC-70-5
 | TPD4S012DRYR | pocketbeagle:SON-6(TI)-DRY
 | TPD4S012DRYR | pocketbeagle:SON-6(TI)-DRY
 | CONN_01X02 | Terminal_Blocks:TerminalBlock_Pheonix_PT-3.5mm_2pol
 | Conn_02x10_Odd_Even | Connect:IDC_Header_Straight_20pins
 | Conn_02x10_Odd_Even | Connect:IDC_Header_Straight_20pins
 | Conn_02x05_Odd_Even | Connect:IDC_Header_Straight_10pins
 | Conn_02x05_Odd_Even | Connect:IDC_Header_Straight_10pins
 | DB15_FEMALE_MountingHoles | vna_footprints:DB15MC
 | BARREL_JACK | vna_footprints:BARREL_JACK
 | 480254000 | Connect:RJ45_TRANSFO
 | USB_A | Connect:USB_A
 | 6.8 uH BRL1608T6R8M | Resistors_SMD:R_0603
 | 6.8 uH BRL1608T6R8M | Resistors_SMD:R_0603
 | BLM15GG471 | Resistors_SMD:R_0402
 | 6.8 uH BRL1608T6R8M | Resistors_SMD:R_0603
 | 6.8 uH BRL1608T6R8M | Resistors_SMD:R_0603
 | BLM15GG471 | Resistors_SMD:R_0402
 | 6.8 uH BRL1608T6R8M | Resistors_SMD:R_0603
 | 6.8 uH BRL1608T6R8M | Resistors_SMD:R_0603
 | BLM15GG471 | Resistors_SMD:R_0402
 | 6.8 uH BRL1608T6R8M | Resistors_SMD:R_0603
 | 6.8 uH BRL1608T6R8M | Resistors_SMD:R_0603
 | BLM15GG471 | Resistors_SMD:R_0402
 | 130 nH | Resistors_SMD:R_0805
 | 130 nH | Resistors_SMD:R_0805
 | 130 nH | Resistors_SMD:R_0805
 | 130 nH | Resistors_SMD:R_0805
 | L_Small | Resistors_SMD:R_0402
 | L_Small | Resistors_SMD:R_0805
 | L_Small | Resistors_SMD:R_0402
 | L_Small | Resistors_SMD:R_0805
 | L_Small | Resistors_SMD:R_0402
 | L_Small | Resistors_SMD:R_0402
 | L_Small | Resistors_SMD:R_0805
 | L_Small | Resistors_SMD:R_0402
 | L_Small | Resistors_SMD:R_0402
 | Q_PMOS_DGS | TO_SOT_Packages_SMD:SOT-23
 | 24 MHz | pocketbeagle:CRYSTAL_5X3.2MM
 | 25 MHz | pocketbeagle:CRYSTAL_5X3.2MM
 | DNP | Resistors_SMD:R_0402
 | 470 nH | Resistors_SMD:R_0402
 | 22 pF | Resistors_SMD:R_0402
 | 51 | Resistors_SMD:R_0402
 | 100k | Resistors_SMD:R_0402
 | R_Small | Resistors_SMD:R_0402
 | R_Small | Resistors_SMD:R_0402
 | R_Small | Resistors_SMD:R_0402
 | 1k | Resistors_SMD:R_0402
 | JMP | Resistors_SMD:R_0402
 | DNP | Resistors_SMD:R_0402
 | DNP | Resistors_SMD:R_0402
 | 470 nH | Resistors_SMD:R_0402
 | 22 pF | Resistors_SMD:R_0402
 | 51 | Resistors_SMD:R_0402
 | 100k | Resistors_SMD:R_0402
 | R_Small | Resistors_SMD:R_0402
 | R_Small | Resistors_SMD:R_0402
 | R_Small | Resistors_SMD:R_0402
 | 1k | Resistors_SMD:R_0402
 | JMP | Resistors_SMD:R_0402
 | DNP | Resistors_SMD:R_0402
 | DNP | Resistors_SMD:R_0402
 | DNP | Resistors_SMD:R_0402
 | 10k | Resistors_SMD:R_0402
 | 470 nH | Resistors_SMD:R_0402
 | 22 pF | Resistors_SMD:R_0402
 | 51 | Resistors_SMD:R_0402
 | 100k | Resistors_SMD:R_0402
 | R_Small | Resistors_SMD:R_0402
 | R_Small | Resistors_SMD:R_0402
 | R_Small | Resistors_SMD:R_0402
 | 1k | Resistors_SMD:R_0402
 | JMP | Resistors_SMD:R_0402
 | DNP | Resistors_SMD:R_0402
 | DNP | Resistors_SMD:R_0402
 | DNP | Resistors_SMD:R_0402
 | DNP | Resistors_SMD:R_0402
 | DNP | Resistors_SMD:R_0402
 | DNP | Resistors_SMD:R_0402
 | 50 | Resistors_SMD:R_0402
 | 22 | Resistors_SMD:R_0402
 | 470 nH | Resistors_SMD:R_0402
 | 22 pF | Resistors_SMD:R_0402
 | 51 | Resistors_SMD:R_0402
 | 100k | Resistors_SMD:R_0402
 | R_Small | Resistors_SMD:R_0402
 | R_Small | Resistors_SMD:R_0402
 | R_Small | Resistors_SMD:R_0402
 | 1k | Resistors_SMD:R_0402
 | JMP | Resistors_SMD:R_0402
 | DNP | Resistors_SMD:R_0402
 | 22 | Resistors_SMD:R_0402
 | 22 | Resistors_SMD:R_0402
 | 22 | Resistors_SMD:R_0402
 | 22 | Resistors_SMD:R_0402
 | 22 | Resistors_SMD:R_0402
 | 22 | Resistors_SMD:R_0402
 | 22 | Resistors_SMD:R_0402
 | 22 | Resistors_SMD:R_0402
 | 22 | Resistors_SMD:R_0402
 | 22 | Resistors_SMD:R_0402
 | 22 | Resistors_SMD:R_0402
 | 22 | Resistors_SMD:R_0402
 | DNP | Resistors_SMD:R_0402
 | 10k | Resistors_SMD:R_0402
 | 390 | Resistors_SMD:R_0402
 | JMP | Resistors_SMD:R_1206
 | 10k | Resistors_SMD:R_0402
 | JMP | Resistors_SMD:R_0402
 | 10k | Resistors_SMD:R_0402
 | 51 | Resistors_SMD:R_0402
 | 51 | Resistors_SMD:R_0402
 | 51 | Resistors_SMD:R_0402
 | 51 | Resistors_SMD:R_0402
 | 51 | Resistors_SMD:R_0402
 | 10k | Resistors_SMD:R_0402
 | 10k | Resistors_SMD:R_0402
 | 10k | Resistors_SMD:R_0402
 | 10k | Resistors_SMD:R_0402
 | 10k | Resistors_SMD:R_0402
 | 10k | Resistors_SMD:R_0402
 | 10k | Resistors_SMD:R_0402
 | 10k | Resistors_SMD:R_0402
 | 10k | Resistors_SMD:R_0402
 | 10k | Resistors_SMD:R_0402
 | 10k | Resistors_SMD:R_0402
 | 10k | Resistors_SMD:R_0402
 | JMP | Resistors_SMD:R_0402
 | 30 | Resistors_SMD:R_0402
 | 30 | Resistors_SMD:R_0402
 | 30 | Resistors_SMD:R_0402
 | 30 | Resistors_SMD:R_0402
 | 10k | Resistors_SMD:R_0402
 | JMP | Resistors_SMD:R_0402
 | 100k | Resistors_SMD:R_0402
 | 100k | Resistors_SMD:R_0402
 | 100k | Resistors_SMD:R_0402
 | 100k | Resistors_SMD:R_0402
 | 100k | Resistors_SMD:R_0402
 | 100k | Resistors_SMD:R_0402
 | 100k | Resistors_SMD:R_0402
 | 100k | Resistors_SMD:R_0402
 | 100k | Resistors_SMD:R_0402
 | 100k | Resistors_SMD:R_0402
 | 100k | Resistors_SMD:R_0402
 | 100k | Resistors_SMD:R_0402
 | 100k | Resistors_SMD:R_0402
 | 100k | Resistors_SMD:R_0402
 | 100k | Resistors_SMD:R_0402
 | 100k | Resistors_SMD:R_0402
 | DNP | Resistors_SMD:R_0402
 | DNP | Resistors_SMD:R_0402
 | JMP | Resistors_SMD:R_0402
 | JMP | Resistors_SMD:R_0402
 | 10k | Resistors_SMD:R_0402
 | 1k | Resistors_SMD:R_0402
 | JMP | Resistors_SMD:R_0402
 | JMP | Resistors_SMD:R_0402
 | DNP | Resistors_SMD:R_0402
 | 10 | Resistors_SMD:R_0402
 | 1M | Resistors_SMD:R_0402
 | JMP | Resistors_SMD:R_0402
 | 10k | Resistors_SMD:R_0402
 | 10k | Resistors_SMD:R_0402
 | 10k | Resistors_SMD:R_0402
 | 10k | Resistors_SMD:R_0402
 | 1.5k | Resistors_SMD:R_0402
 | 12.1k | Resistors_SMD:R_0402
 | 1.5k | Resistors_SMD:R_0402
 | 1.5k | Resistors_SMD:R_0402
 | 100 | Resistors_SMD:R_0402
 | 1.5k | Resistors_SMD:R_0402
 | 100 | Resistors_SMD:R_0402
 | 10k | Resistors_SMD:R_0402
 | JMP | Resistors_SMD:R_0402
 | JMP | Resistors_SMD:R_0402
 | 10k | Resistors_SMD:R_0402
 | 1k | Resistors_SMD:R_0402
 | 1k | Resistors_SMD:R_0402
 | 10 | pocketbeagle:RN0804
 | 10 | pocketbeagle:RN0804
 | 10 | pocketbeagle:RN0804
 | 10 | pocketbeagle:RN0804
 | 10 | pocketbeagle:RN0804
 | 10 | pocketbeagle:RN0804
 | 10 | pocketbeagle:RN0804
 | 10 | pocketbeagle:RN0804
 | RESISTOR.NETWORK-_4_ | pocketbeagle:RN0804
 | 100 | pocketbeagle:RN0804
 | 100 | pocketbeagle:RN0804
 | 10k | pocketbeagle:RN0804
 | 10k | pocketbeagle:RN0804
 | MINI_PUSHBUTTON | pocketbeagle:MINI_PUSHBUTTON
 | ad9864 | Housings_DFN_QFN:QFN-48-1EP_7x7mm_Pitch0.5mm
 | ad9864 | Housings_DFN_QFN:QFN-48-1EP_7x7mm_Pitch0.5mm
 | ad9864 | Housings_DFN_QFN:QFN-48-1EP_7x7mm_Pitch0.5mm
 | ad9864 | Housings_DFN_QFN:QFN-48-1EP_7x7mm_Pitch0.5mm
 | ADP7158 | Housings_DFN_QFN:DFN-10-1EP_3x3mm_Pitch0.5mm
 | OKR-T/3-W12-C | vna_footprints:OKRT3_C72
 | CONN_SMA_2GND | vna_footprints:734120110_ufl_umc
 | CONN_SMA_2GND | vna_footprints:734120110_ufl_umc
 | CONN_SMA | vna_footprints:732511150_sma_thin
 | CONN_SMA | vna_footprints:732511150_sma_thin
 | CONN_SMA | vna_footprints:732511150_sma_thin
 | CONN_SMA | vna_footprints:732511150_sma_thin
 | CONN_SMA_2GND | vna_footprints:734120110_ufl_umc
 | CONN_SMA_2GND | vna_footprints:734120110_ufl_umc
 | AD9577 | Housings_DFN_QFN:QFN-40-1EP_6x6mm_Pitch0.5mm
 | NB3N551 | Housings_SOIC:SOIC-8_3.9x4.9mm_Pitch1.27mm
 | CONN_SMA | vna_footprints:732511150_sma_thin
 | CONN_SMA | vna_footprints:732512200_SMA
 | OSD3358-512M-BSM | pocketbeagle:OSD335X-BGA-256
 | 74HC244 | Housings_SSOP:TSSOP-20_4.4x6.5mm_Pitch0.65mm
 | LAN8710A | Housings_DFN_QFN:QFN-32-1EP_5x5mm_Pitch0.5mm
 | TPS2051 | Housings_SOIC:SOIC-8_3.9x4.9mm_Pitch1.27mm
 | MICROSD | pocketbeagle:MICROSD
 | 10118192-0001LF | pocketbeagle:10118192-0001LF(MICRO-USB-B-AMPHENOL-FCI)
 | 26 MHz 7M-26.000MEEQ-T | vna_footprints:crystal_FA238-TSX3225
Qty | Value | Footprint | DigiKey PN
25 | 10 nF | Capacitors_SMD:C_0402 | 399-7760-1-ND
78 | 100 nF | Capacitors_SMD:C_0402 | 587-1456-1-ND
16 | 100 pF | Capacitors_SMD:C_0402 | 1276-1633-1-ND
8 | 120 pF | Capacitors_SMD:C_0402 | 399-8945-1-ND
4 | 2.2 nF | Capacitors_SMD:C_0402 | 490-5419-1-ND
5 | 1 nF | Capacitors_SMD:C_0402 | 399-1031-1-ND
32 | 10 pF | Capacitors_SMD:C_0402 | 445-4896-1-ND
9 | 10 uF | Capacitors_SMD:C_0603 | 490-12318-1-ND
5 | 1 uF | Capacitors_SMD:C_0402 | 445-12012-1-ND
3 | 22 pF | Capacitors_SMD:C_0402 | LAB
1 | 220 nF | Capacitors_SMD:C_0402 | LAB
6 | 18 pF | Capacitors_SMD:C_0402 | LAB
2 | 30 pF | Capacitors_SMD:C_0402 | LAB
1 | 470 pF | Capacitors_SMD:C_0402 | LAB
2 | 22 nF | Capacitors_SMD:C_0402 | LAB
4 | 15 pF | Capacitors_SMD:C_0402 | LAB
6 | LED_Small | LEDs:LED_0603 | 160-1447-1-ND
1 | 5.6V | Diodes_SMD:SOD-123 | DFLZ6V2-TPMSCT-ND
1 | Polyfuse_Small | Resistors_SMD:R_1210 | MF-USML300-2CT-ND
1 | SN74LVC1G07DCK | TO_SOT_Packages_SMD:SC-70-5 | 296-8486-1-ND
2 | TPD4S012DRYR | pocketbeagle:SON-6(TI)-DRY | 296-24244-1-ND
1 | CONN_01X02 | Terminal_Blocks:TerminalBlock_Pheonix_PT-3.5mm_2pol | LAB
2 | Conn_02x10_Odd_Even | Connect:IDC_Header_Straight_20pins | 1175-1623-ND
2 | Conn_02x05_Odd_Even | Connect:IDC_Header_Straight_10pins | 1175-1621-ND
1 | DB15_FEMALE_MountingHoles | vna_footprints:DB15MC | AE10974-ND
1 | BARREL_JACK | vna_footprints:BARREL_JACK | CP-002A-ND
1 | 480254000 | Connect:RJ45_TRANSFO | WM5485-ND
1 | USB_A | Connect:USB_A | ED2989-ND
8 | 6.8 uH BRL1608T6R8M | Resistors_SMD:R_0603 | 587-2902-1-ND
4 | BLM15GG471 | Resistors_SMD:R_0402 | 490-5198-1-ND
4 | 130 nH | Resistors_SMD:R_0805 | 490-10555-1-ND
6 | L_Small | Resistors_SMD:R_0402 | 490-5440-1-ND
3 | L_Small | Resistors_SMD:R_0805 | 490-1039-1-ND
1 | Q_PMOS_DGS | TO_SOT_Packages_SMD:SOT-23
1 | 24 MHz | pocketbeagle:CRYSTAL_5X3.2MM | 887-1090-1-ND
1 | 25 MHz | pocketbeagle:CRYSTAL_5X3.2MM | 535-9108-1-ND
4 | 470 nH | Resistors_SMD:R_0402 | 490-14297-1-ND
4 | 22 pF | Resistors_SMD:R_0402 | 399-7775-1-ND
9 | 51 | Resistors_SMD:R_0402 | STOCK IN LAB
20 | 100k | Resistors_SMD:R_0402 | 311-100KJRCT-ND
12 | R_Small | Resistors_SMD:R_0402
7 | 1k | Resistors_SMD:R_0402 | A106129CT-ND
14 | JMP | Resistors_SMD:R_0402 | P0.0JCT-ND
24 | 10k | Resistors_SMD:R_0402 | STOCK IN LAB
1 | 50 | Resistors_SMD:R_0402 | STOCK IN LAB
13 | 22 | Resistors_SMD:R_0402 | STOCK IN LAB
1 | 390 | Resistors_SMD:R_0402 | STOCK IN LAB
1 | JMP | Resistors_SMD:R_1206 | STOCK IN LAB
4 | 30 | Resistors_SMD:R_0402 | STOCK IN LAB
1 | 10 | Resistors_SMD:R_0402 | STOCK IN LAB
1 | 1M | Resistors_SMD:R_0402 | STOCK IN LAB
4 | 1.5k | Resistors_SMD:R_0402 | STOCK IN LAB
1 | 12.1k | Resistors_SMD:R_0402 | STOCK IN LAB
2 | 100 | Resistors_SMD:R_0402 | STOCK IN LAB
8 | 10 | pocketbeagle:RN0804 | YC124J-10CT-ND
1 | RESISTOR.NETWORK-_4_ | pocketbeagle:RN0804 | YC124J-10KCT-ND
2 | 100 | pocketbeagle:RN0804 | YC124J-100CT-ND
2 | 10k | pocketbeagle:RN0804 | YC124J-10KCT-ND
1 | MINI_PUSHBUTTON | pocketbeagle:MINI_PUSHBUTTON | 401-1429-1-ND
4 | ad9864 | Housings_DFN_QFN:QFN-48-1EP_7x7mm_Pitch0.5mm | AD9864BCPZ-ND
1 | ADP7158 | Housings_DFN_QFN:DFN-10-1EP_3x3mm_Pitch0.5mm | ADP7158ACPZ-3.3-R7CT-ND
1 | OKR-T/3-W12-C | vna_footprints:OKRT3_C72 | 811-2115-5-ND
4 | CONN_SMA_2GND | vna_footprints:734120110_ufl_umc | STOCK IN LAB
5 | CONN_SMA | vna_footprints:732511150_sma_thin | WM5534-ND
1 | AD9577 | Housings_DFN_QFN:QFN-40-1EP_6x6mm_Pitch0.5mm | AD9577BCPZ-ND
1 | NB3N551 | Housings_SOIC:SOIC-8_3.9x4.9mm_Pitch1.27mm | NB3N551DR2GOSCT-ND
1 | CONN_SMA | vna_footprints:732512200_SMA | A97594-ND
1 | OSD3358-512M-BSM | pocketbeagle:OSD335X-BGA-256 | 1676-1002-ND
1 | 74HC244 | Housings_SSOP:TSSOP-20_4.4x6.5mm_Pitch0.65mm | 296-8276-1-ND
1 | LAN8710A | Housings_DFN_QFN:QFN-32-1EP_5x5mm_Pitch0.5mm | LAN8710A-EZC-CT-ND
1 | TPS2051 | Housings_SOIC:SOIC-8_3.9x4.9mm_Pitch1.27mm | 296-16987-1-ND
1 | MICROSD | pocketbeagle:MICROSD | ALIEXPRESS
1 | 10118192-0001LF | pocketbeagle:10118192-0001LF(MICRO-USB-B-AMPHENOL-FCI) | 609-4613-1-ND
1 | 26 MHz 7M-26.000MEEQ-T | vna_footprints:crystal_FA238-TSX3225 | 887-1327-1-ND
C7 | 3

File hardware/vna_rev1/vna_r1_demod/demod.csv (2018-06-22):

Source: | /home/kleinjt/repos/vna/hardware/vna_r1_demod/vna_r1_demod.sch
Date: | Sat May 19 16:49:21 2018
Tool: | Eeschema 4.0.7
Generator: | /usr/local/share/doc/kicad/scripts/bom-in-python/bom_csv_grouped_by_value.py
Component Count: | 113
Individual Components:
Item | Qty | Reference(s) | Value | LibPart | Footprint | Datasheet
 |  | ATT501 | HMC657LP2E | hmc65xlp2e:HMC65XLP2E | Housings_DFN_QFN:DFN-6-1EP_2x2mm_Pitch0.65mm
 |  | C201 | C_Small | device:C_Small | Capacitors_SMD:C_0201
 |  | C202 | C_Small | device:C_Small | Capacitors_SMD:C_0201
 |  | C203 | C_Small | device:C_Small | Capacitors_SMD:C_0402
 |  | C204 | C_Small | device:C_Small | Capacitors_SMD:C_0201
 |  | C205 | C_Small | device:C_Small | Capacitors_SMD:C_0201
 |  | C206 | C_Small | device:C_Small | Capacitors_SMD:C_0402
 |  | C207 | C_Small | device:C_Small | Capacitors_SMD:C_0402
 |  | C208 | C_Small | device:C_Small | Capacitors_SMD:C_0402
 |  | C209 | C_Small | device:C_Small | Capacitors_SMD:C_0402
 |  | C210 | DNP | device:C_Small | Capacitors_SMD:C_0201
 |  | C211 | C_Small | device:C_Small | Capacitors_SMD:C_0402
 |  | C301 | C_Small | device:C_Small | Capacitors_SMD:C_0201
 |  | C302 | C_Small | device:C_Small | Capacitors_SMD:C_0201
 |  | C303 | C_Small | device:C_Small | Capacitors_SMD:C_0402
 |  | C304 | C_Small | device:C_Small | Capacitors_SMD:C_0201
 |  | C305 | C_Small | device:C_Small | Capacitors_SMD:C_0201
 |  | C306 | C_Small | device:C_Small | Capacitors_SMD:C_0402
 |  | C307 | C_Small | device:C_Small | Capacitors_SMD:C_0402
 |  | C308 | C_Small | device:C_Small | Capacitors_SMD:C_0402
 |  | C309 | C_Small | device:C_Small | Capacitors_SMD:C_0402
 |  | C310 | DNP | device:C_Small | Capacitors_SMD:C_0201
 |  | C311 | C_Small | device:C_Small | Capacitors_SMD:C_0402
 |  | C401 | 10 uF | device:C_Small | Capacitors_SMD:C_0805
 |  | C402 | 1 uF | device:C_Small | Capacitors_SMD:C_0402
 |  | C403 | 1 uF | device:C_Small | Capacitors_SMD:C_0402
 |  | C404 | 1 uF | device:C_Small | Capacitors_SMD:C_0402
 |  | C405 | 100 nF | device:C_Small | Capacitors_SMD:C_0402
 |  | C406 | 1 uF | device:C_Small | Capacitors_SMD:C_0402
 |  | C407 | 1 uF | device:C_Small | Capacitors_SMD:C_0402
 |  | C408 | 10 uF | device:C_Small | Capacitors_SMD:C_0805
 |  | C409 | C_Small | device:C_Small | Capacitors_SMD:C_0402
 |  | C410 | 4.7 uF | device:CP_Small | Capacitors_SMD:c_elec_6.3x5.8
 |  | C411 | 4.7 uF | device:CP_Small | Capacitors_SMD:C_0805
 |  | C412 | 100 nF | device:C_Small | Capacitors_SMD:C_0402
 |  | C413 | 1 uF | device:C_Small | Capacitors_SMD:C_0402
 |  | C414 | 4.7 uF | device:CP_Small | Capacitors_SMD:C_0805
 |  | C501 | 10 pF | device:C_Small | Capacitors_SMD:C_0201
 |  | C502 | 10 pF | device:C_Small | Capacitors_SMD:C_0201
 |  | C503 | DNP | device:C_Small | Resistors_SMD:R_0402
 |  | C504 | DNP | device:C_Small | Resistors_SMD:R_0402
 |  | C505 | C_Small | device:C_Small | Capacitors_SMD:C_0201
 |  | C506 | 10 pF | device:C_Small | Capacitors_SMD:C_0201
 |  | C507 | C_Small | device:C_Small | Capacitors_SMD:C_0201
 |  | C508 | DNP | device:C_Small | Resistors_SMD:R_0402
 |  | C509 | DNP | device:C_Small | Resistors_SMD:R_0402
 |  | C601 | C_Small | device:C_Small | Capacitors_SMD:C_0201
 |  | D401 | LED | device:LED | LEDs:LED_0603
 |  | F401 | Polyfuse_Small | device:Polyfuse_Small | Resistors_SMD:R_1210
 |  | H401 | MOUNTING_HOLE | mounting_hole:MOUNTING_HOLE | Mounting_Holes:MountingHole_2-5mm
 |  | H402 | MOUNTING_HOLE | mounting_hole:MOUNTING_HOLE | Mounting_Holes:MountingHole_2-5mm
 |  | H403 | MOUNTING_HOLE | mounting_hole:MOUNTING_HOLE | Mounting_Holes:MountingHole_2-5mm
 |  | H404 | MOUNTING_HOLE | mounting_hole:MOUNTING_HOLE | Mounting_Holes:MountingHole_2-5mm
 |  | H405 | MOUNTING_HOLE | mounting_hole:MOUNTING_HOLE | Mounting_Holes:MountingHole_2-5mm
 |  | H406 | MOUNTING_HOLE | mounting_hole:MOUNTING_HOLE | Mounting_Holes:MountingHole_2-5mm
 |  | H407 | MOUNTING_HOLE | mounting_hole:MOUNTING_HOLE | Mounting_Holes:MountingHole_2-5mm
 |  | H408 | MOUNTING_HOLE | mounting_hole:MOUNTING_HOLE | Mounting_Holes:MountingHole_2-5mm
 |  | H409 | MOUNTING_HOLE | mounting_hole:MOUNTING_HOLE | Mounting_Holes:MountingHole_2-5mm
 |  | J401 | Conn_02x05_Odd_Even | conn:Conn_02x05_Odd_Even | Connect:IDC_Header_Straight_10pins
 |  | L201 | L_Small | device:L_Small | Resistors_SMD:R_0603
 |  | L202 | L_Small | device:L_Small | Resistors_SMD:R_0402
 |  | L203 | L_Small | device:L_Small | Resistors_SMD:R_0402
 |  | L204 | L_Small | device:L_Small | Resistors_SMD:R_0402
 |  | L205 | L_Small | device:L_Small | Resistors_SMD:R_0402
 |  | L301 | L_Small | device:L_Small | Resistors_SMD:R_0603
 |  | L302 | L_Small | device:L_Small | Resistors_SMD:R_0402
 |  | L303 | L_Small | device:L_Small | Resistors_SMD:R_0402
 |  | L304 | L_Small | device:L_Small | Resistors_SMD:R_0402
 |  | L305 | L_Small | device:L_Small | Resistors_SMD:R_0402
 |  | L401 | L_Small | device:L_Small | Resistors_SMD:R_1206
 |  | L402 | L_Small | device:L_Small | Resistors_SMD:R_1206
 |  | R201 | 13 | device:R_Small | Resistors_SMD:R_0805
 |  | R202 | R_Small | device:R_Small | Resistors_SMD:R_0402
 |  | R203 | R_Small | device:R_Small | Resistors_SMD:R_0402
 |  | R204 | R_Small | device:R_Small | Resistors_SMD:R_0402
 |  | R205 | R_Small | device:R_Small | Resistors_SMD:R_0402
 |  | R206 | R_Small | device:R_Small | Resistors_SMD:R_0402
 |  | R207 | R_Small | device:R_Small | Resistors_SMD:R_0402
 |  | R301 | 13 | device:R_Small | Resistors_SMD:R_0805
 |  | R302 | R_Small | device:R_Small | Resistors_SMD:R_0402
 |  | R303 | R_Small | device:R_Small | Resistors_SMD:R_0402
 |  | R304 | R_Small | device:R_Small | Resistors_SMD:R_0402
 |  | R305 | R_Small | device:R_Small | Resistors_SMD:R_0402
 |  | R306 | R_Small | device:R_Small | Resistors_SMD:R_0402
 |  | R307 | R_Small | device:R_Small | Resistors_SMD:R_0402
 |  | R401 | 100 | device:R_Small | Resistors_SMD:R_0402
 |  | R402 | 10k | device:R_Small | Resistors_SMD:R_0402
 |  | R403 | 10k | device:R_Small | Resistors_SMD:R_0402
 |  | R404 | 10k | device:R_Small | Resistors_SMD:R_0402
 |  | R405 | 10k | device:R_Small | Resistors_SMD:R_0402
 |  | R406 | 10k | device:R_Small | Resistors_SMD:R_0402
 |  | R407 | 47k | device:R_Small | Resistors_SMD:R_0402
 |  | R408 | 12k | device:R_Small | Resistors_SMD:R_0402
 |  | R409 | 10k | device:R_Small | Resistors_SMD:R_0402
 |  | T201 | Transformer_SP_1S | device:Transformer_SP_1S | vna_footprints:5LEAD_BALUN_4p83mm_3p3mm
 |  | T301 | Transformer_SP_1S | device:Transformer_SP_1S | vna_footprints:5LEAD_BALUN_4p83mm_3p3mm
 |  | U201 | SKY65013-70LF | sky65013-70lf:SKY65013-70LF | TO_SOT_Packages_SMD:SOT89-3_Housing
 |  | U202 | PAT0510S-C-XDB-T10 | pat0510s-c-xdb-t10:PAT0510S-C-XDB-T10 | vna_footprints:PAT0510S
 |  | U203 | LTC5548 | ltc5549:LTC5549 | vna_footprints:QFN_12_3mm2mm
 |  | U204 | CONN_SMA | conn_sma:CONN_SMA | vna_footprints:732511150_sma_thin
 |  | U301 | SKY65013-70LF | sky65013-70lf:SKY65013-70LF | TO_SOT_Packages_SMD:SOT89-3_Housing
 |  | U302 | PAT0510S-C-XDB-T10 | pat0510s-c-xdb-t10:PAT0510S-C-XDB-T10 | vna_footprints:PAT0510S
 |  | U303 | LTC5548 | ltc5549:LTC5549 | vna_footprints:QFN_12_3mm2mm
 |  | U304 | CONN_SMA | conn_sma:CONN_SMA | vna_footprints:732511150_sma_thin
 |  | U401 | ADP7158 | adp7158:ADP7158 | Housings_DFN_QFN:DFN-10-1EP_3x3mm_Pitch0.5mm
 |  | U402 | 74HC244 | 74xx:74HC244 | Housings_SSOP:TSSOP-20_4.4x6.5mm_Pitch0.65mm
 |  | U403 | LD39100 | ld39100:LD39100 | Housings_DFN_QFN:DFN-6-1EP_3x3mm_Pitch0.95mm
 |  | U501 | CONN_SMA_2GND | conn_sma_2gnd:CONN_SMA_2GND | vna_footprints:SMA_901-10512_6p7MIL_FR408_CPW_LAUNCH
 |  | U502 | resistive_bridge | resistive_bridge:resistive_bridge | vna_footprints:resistive_bridge_osh_fr408_ustrip_mirrored
 |  | U503 | resistive_bridge | resistive_bridge:resistive_bridge | vna_footprints:resistive_bridge_osh_fr408_ustrip
 |  | U504 | CONN_SMA_2GND | conn_sma_2gnd:CONN_SMA_2GND | vna_footprints:SMA_901-10512_6p7MIL_FR408_CPW_LAUNCH
 |  | U601 | CONN_SMA_2GND | conn_sma_2gnd:CONN_SMA_2GND | vna_footprints:SMA_901-10512_6p7MIL_FR408_CPW_LAUNCH
 |  | U602 | PWR_SPLITTER | pwr_splitter:PWR_SPLITTER | vna_footprints:PS1608
Collated Components:
Item | Qty | Reference(s) | Value | LibPart | Footprint | Datasheet
1 | 1 | ATT501 | HMC657LP2E | hmc65xlp2e:HMC65XLP2E | Housings_DFN_QFN:DFN-6-1EP_2x2mm_Pitch0.65mm
2 | 11 | C201, C202, C204, C205, C301, C302, C304, C305, C505, C507, C601 | C_Small | device:C_Small | Capacitors_SMD:C_0201
3 | 13 | C203, C206, C207, C208, C209, C211, C303, C306, C307, C308, C309, C311, C409 | C_Small | device:C_Small | Capacitors_SMD:C_0402
4 | 2 | C210, C310 | DNP | device:C_Small | Capacitors_SMD:C_0201
5 | 2 | C401, C408 | 10 uF | device:C_Small | Capacitors_SMD:C_0805
6 | 6 | C402, C403, C404, C406, C407, C413 | 1 uF | device:C_Small | Capacitors_SMD:C_0402
7 | 2 | C405, C412 | 100 nF | device:C_Small | Capacitors_SMD:C_0402
8 | 1 | C410 | 4.7 uF | device:CP_Small | Capacitors_SMD:c_elec_6.3x5.8
9 | 2 | C411, C414 | 4.7 uF | device:CP_Small | Capacitors_SMD:C_0805
10 | 3 | C501, C502, C506 | 10 pF | device:C_Small | Capacitors_SMD:C_0201
11 | 4 | C503, C504, C508, C509 | DNP | device:C_Small | Resistors_SMD:R_0402
12 | 1 | D401 | LED | device:LED | LEDs:LED_0603
13 | 1 | F401 | Polyfuse_Small | device:Polyfuse_Small | Resistors_SMD:R_1210
14 | 9 | H401, H402, H403, H404, H405, H406, H407, H408, H409 | MOUNTING_HOLE | mounting_hole:MOUNTING_HOLE | Mounting_Holes:MountingHole_2-5mm
15 | 1 | J401 | Conn_02x05_Odd_Even | conn:Conn_02x05_Odd_Even | Connect:IDC_Header_Straight_10pins
16 | 2 | L201, L301 | L_Small | device:L_Small | Resistors_SMD:R_0603
17 | 8 | L202, L203, L204, L205, L302, L303, L304, L305 | L_Small | device:L_Small | Resistors_SMD:R_0402
18 | 2 | L401, L402 | L_Small | device:L_Small | Resistors_SMD:R_1206
19 | 2 | R201, R301 | 13 | device:R_Small | Resistors_SMD:R_0805
20 | 12 | R202, R203, R204, R205, R206, R207, R302, R303, R304, R305, R306, R307 | R_Small | device:R_Small | Resistors_SMD:R_0402
21 | 1 | R401 | 100 | device:R_Small | Resistors_SMD:R_0402
22 | 6 | R402, R403, R404, R405, R406, R409 | 10k | device:R_Small | Resistors_SMD:R_0402
23 | 1 | R407 | 47k | device:R_Small | Resistors_SMD:R_0402
24 | 1 | R408 | 12k | device:R_Small | Resistors_SMD:R_0402
25 | 2 | T201, T301 | Transformer_SP_1S | device:Transformer_SP_1S | vna_footprints:5LEAD_BALUN_4p83mm_3p3mm
26 | 2 | U201, U301 | SKY65013-70LF | sky65013-70lf:SKY65013-70LF | TO_SOT_Packages_SMD:SOT89-3_Housing
27 | 2 | U202, U302 | PAT0510S-C-XDB-T10 | pat0510s-c-xdb-t10:PAT0510S-C-XDB-T10 | vna_footprints:PAT0510S
28 | 2 | U203, U303 | LTC5548 | ltc5549:LTC5549 | vna_footprints:QFN_12_3mm2mm
29 | 2 | U204, U304 | CONN_SMA | conn_sma:CONN_SMA | vna_footprints:732511150_sma_thin
30 | 1 | U401 | ADP7158 | adp7158:ADP7158 | Housings_DFN_QFN:DFN-10-1EP_3x3mm_Pitch0.5mm
31 | 1 | U402 | 74HC244 | 74xx:74HC244 | Housings_SSOP:TSSOP-20_4.4x6.5mm_Pitch0.65mm
32 | 1 | U403 | LD39100 | ld39100:LD39100 | Housings_DFN_QFN:DFN-6-1EP_3x3mm_Pitch0.95mm
33 | 3 | U501, U504, U601 | CONN_SMA_2GND | conn_sma_2gnd:CONN_SMA_2GND | vna_footprints:SMA_901-10512_6p7MIL_FR408_CPW_LAUNCH
34 | 1 | U502 | resistive_bridge | resistive_bridge:resistive_bridge | vna_footprints:resistive_bridge_osh_fr408_ustrip_mirrored
35 | 1 | U503 | resistive_bridge | resistive_bridge:resistive_bridge | vna_footprints:resistive_bridge_osh_fr408_ustrip
36 | 1 | U602 | PWR_SPLITTER | pwr_splitter:PWR_SPLITTER | vna_footprints:PS1608

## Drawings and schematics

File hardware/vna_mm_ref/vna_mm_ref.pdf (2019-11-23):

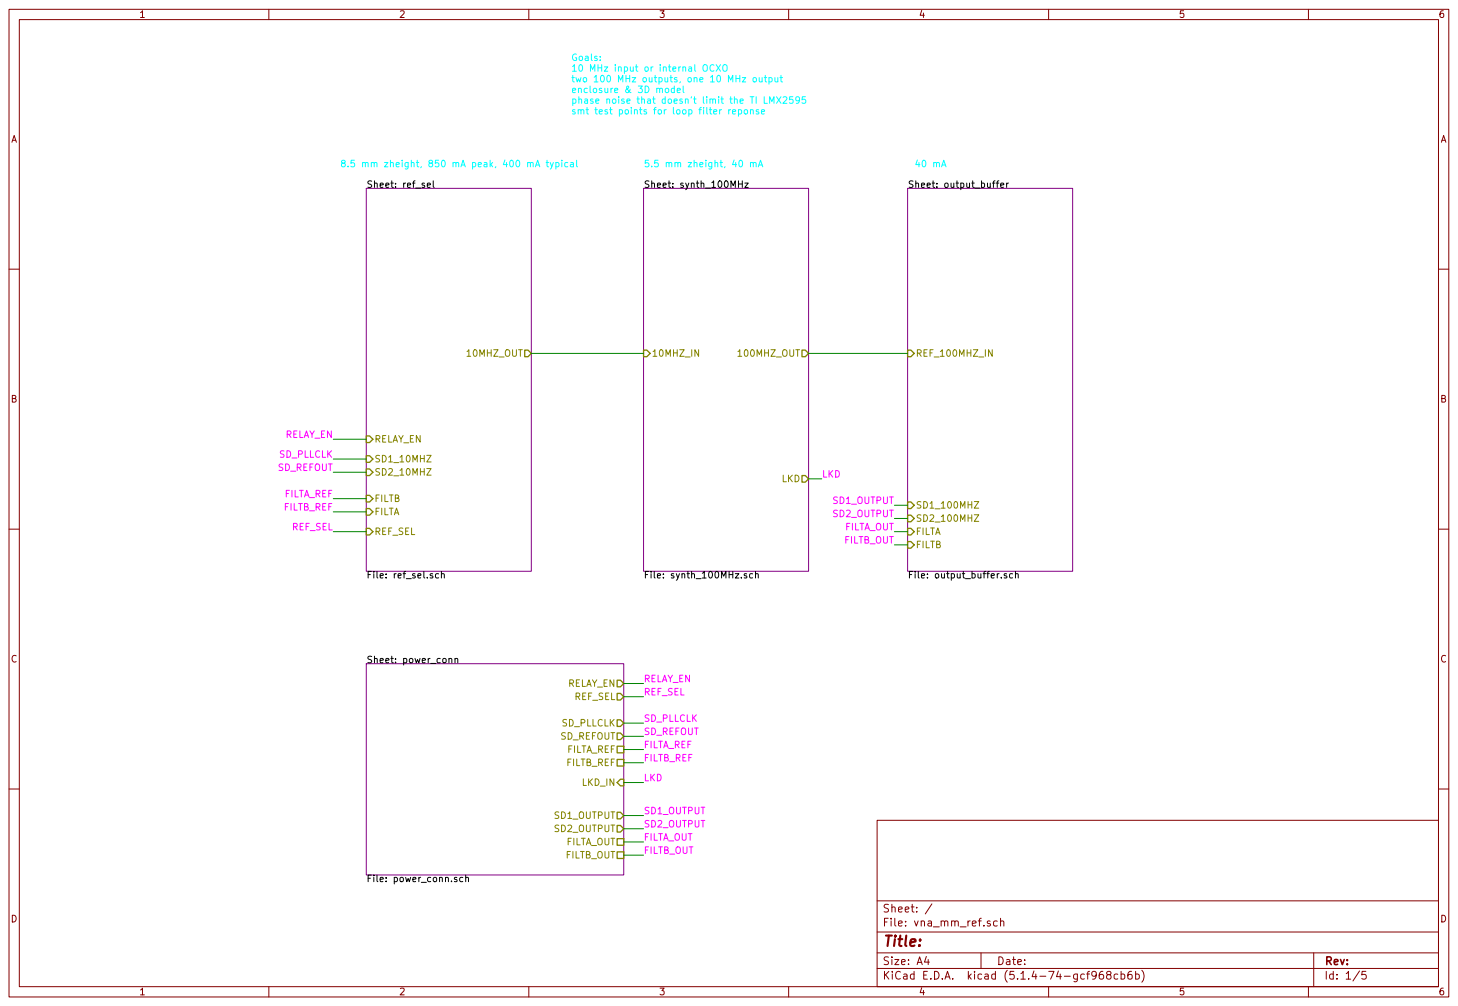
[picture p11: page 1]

two 100 MHz outputs, one 10 MHz output enclosure & 3D model phase noise that doesn't limit the TI LMX2595

smt test points for loop filter reponse

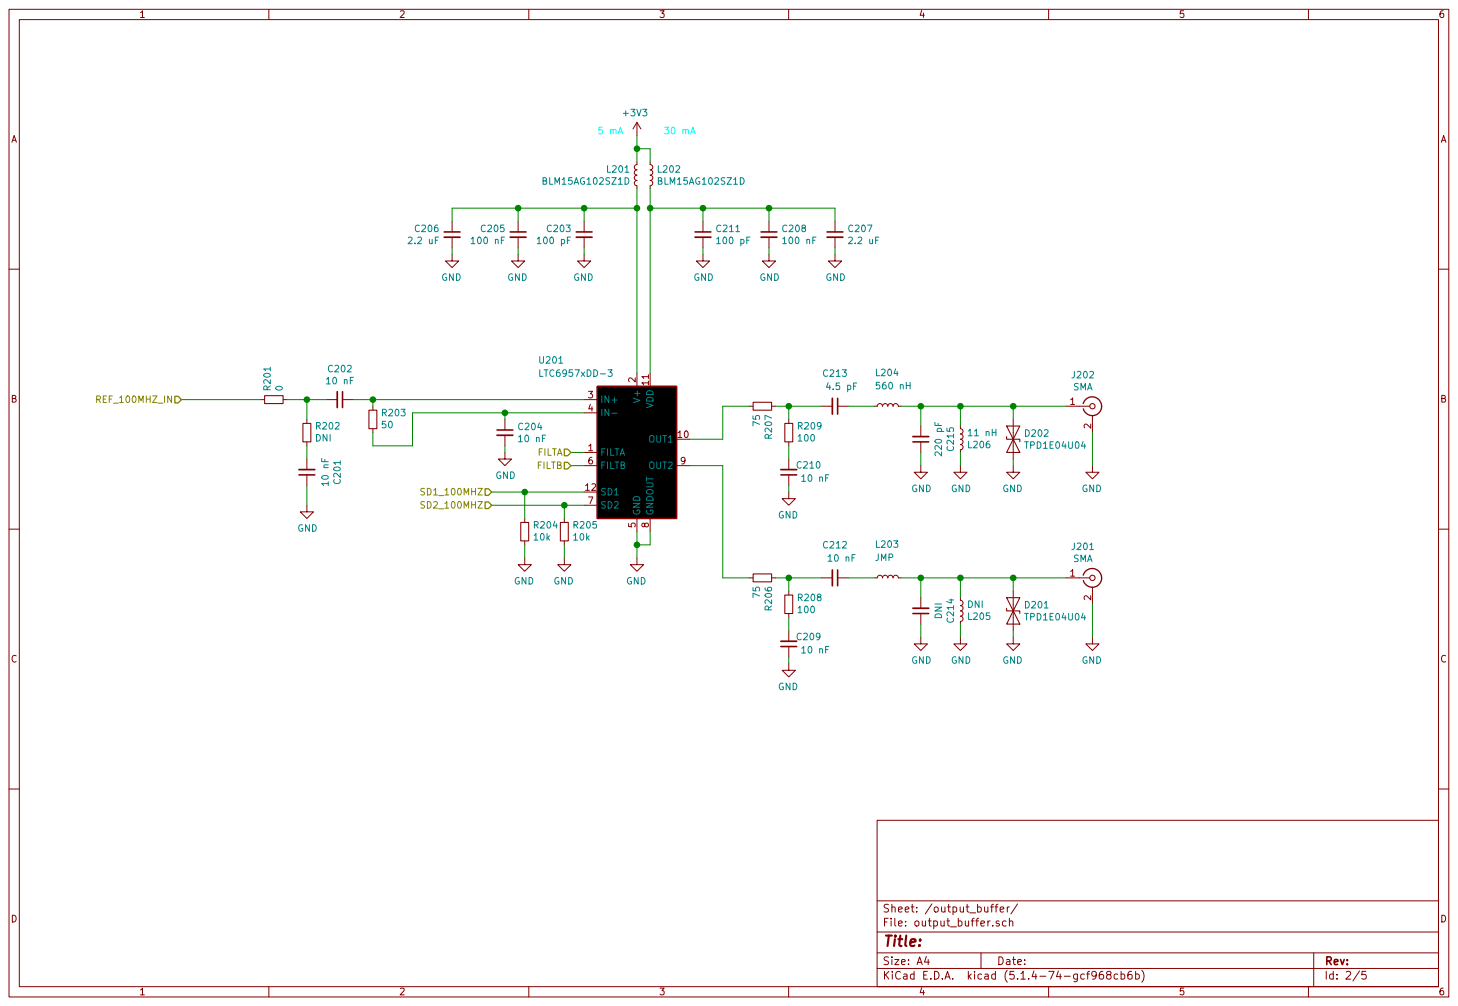
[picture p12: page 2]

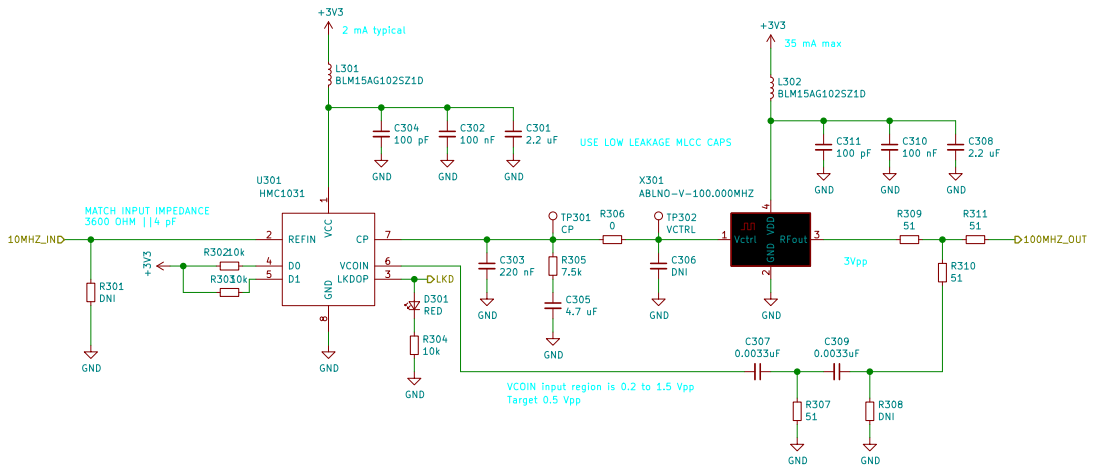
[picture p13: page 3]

2 mA typical MATCH INPUT IMPEDANCE

35 mA max VCOIN input region is 0.2 to 1.5 Vpp USE LOW LEAKAGE MLCC CAPS

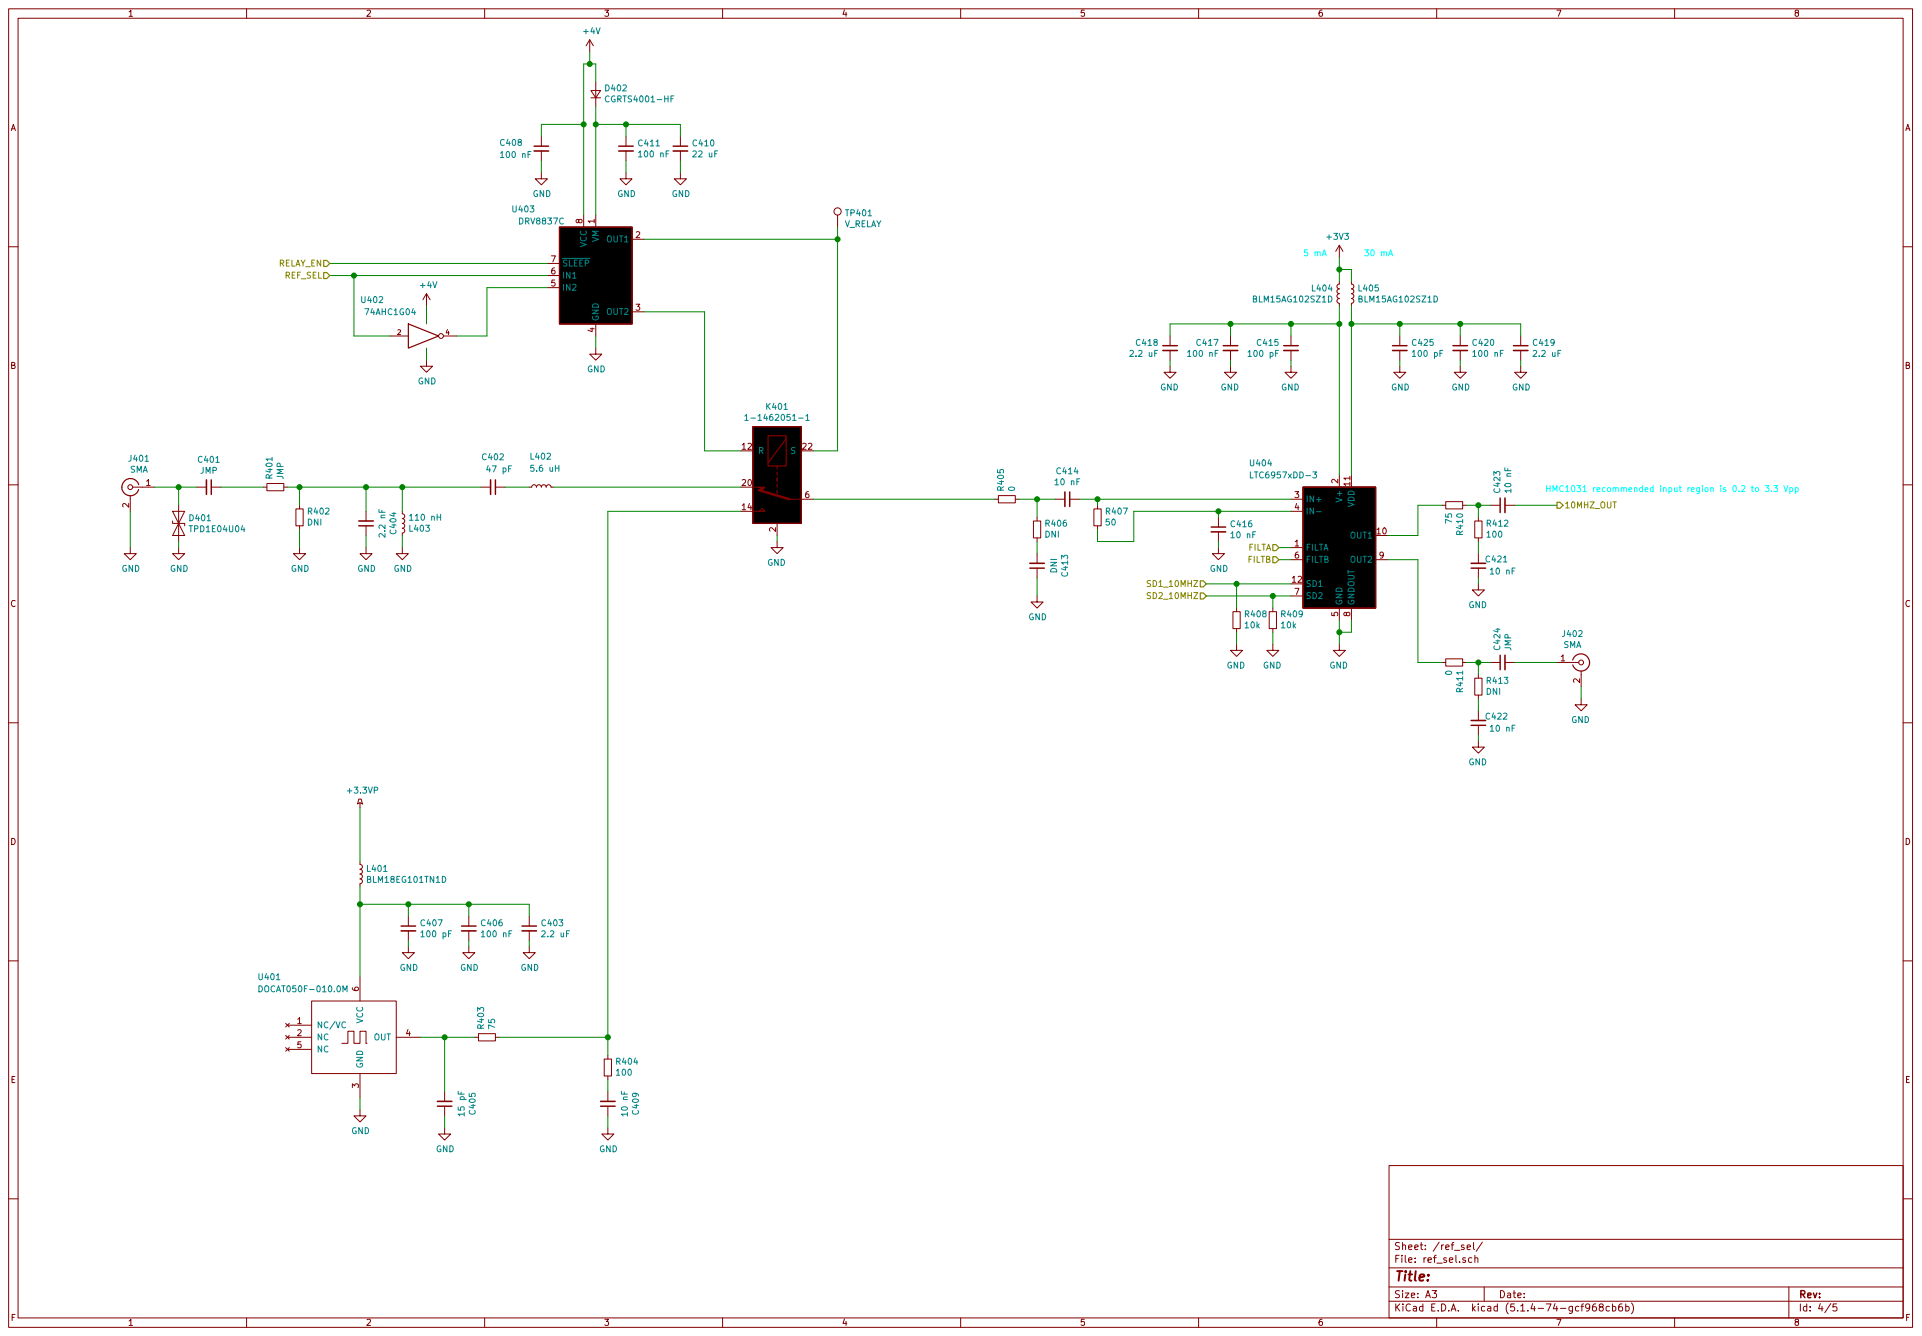
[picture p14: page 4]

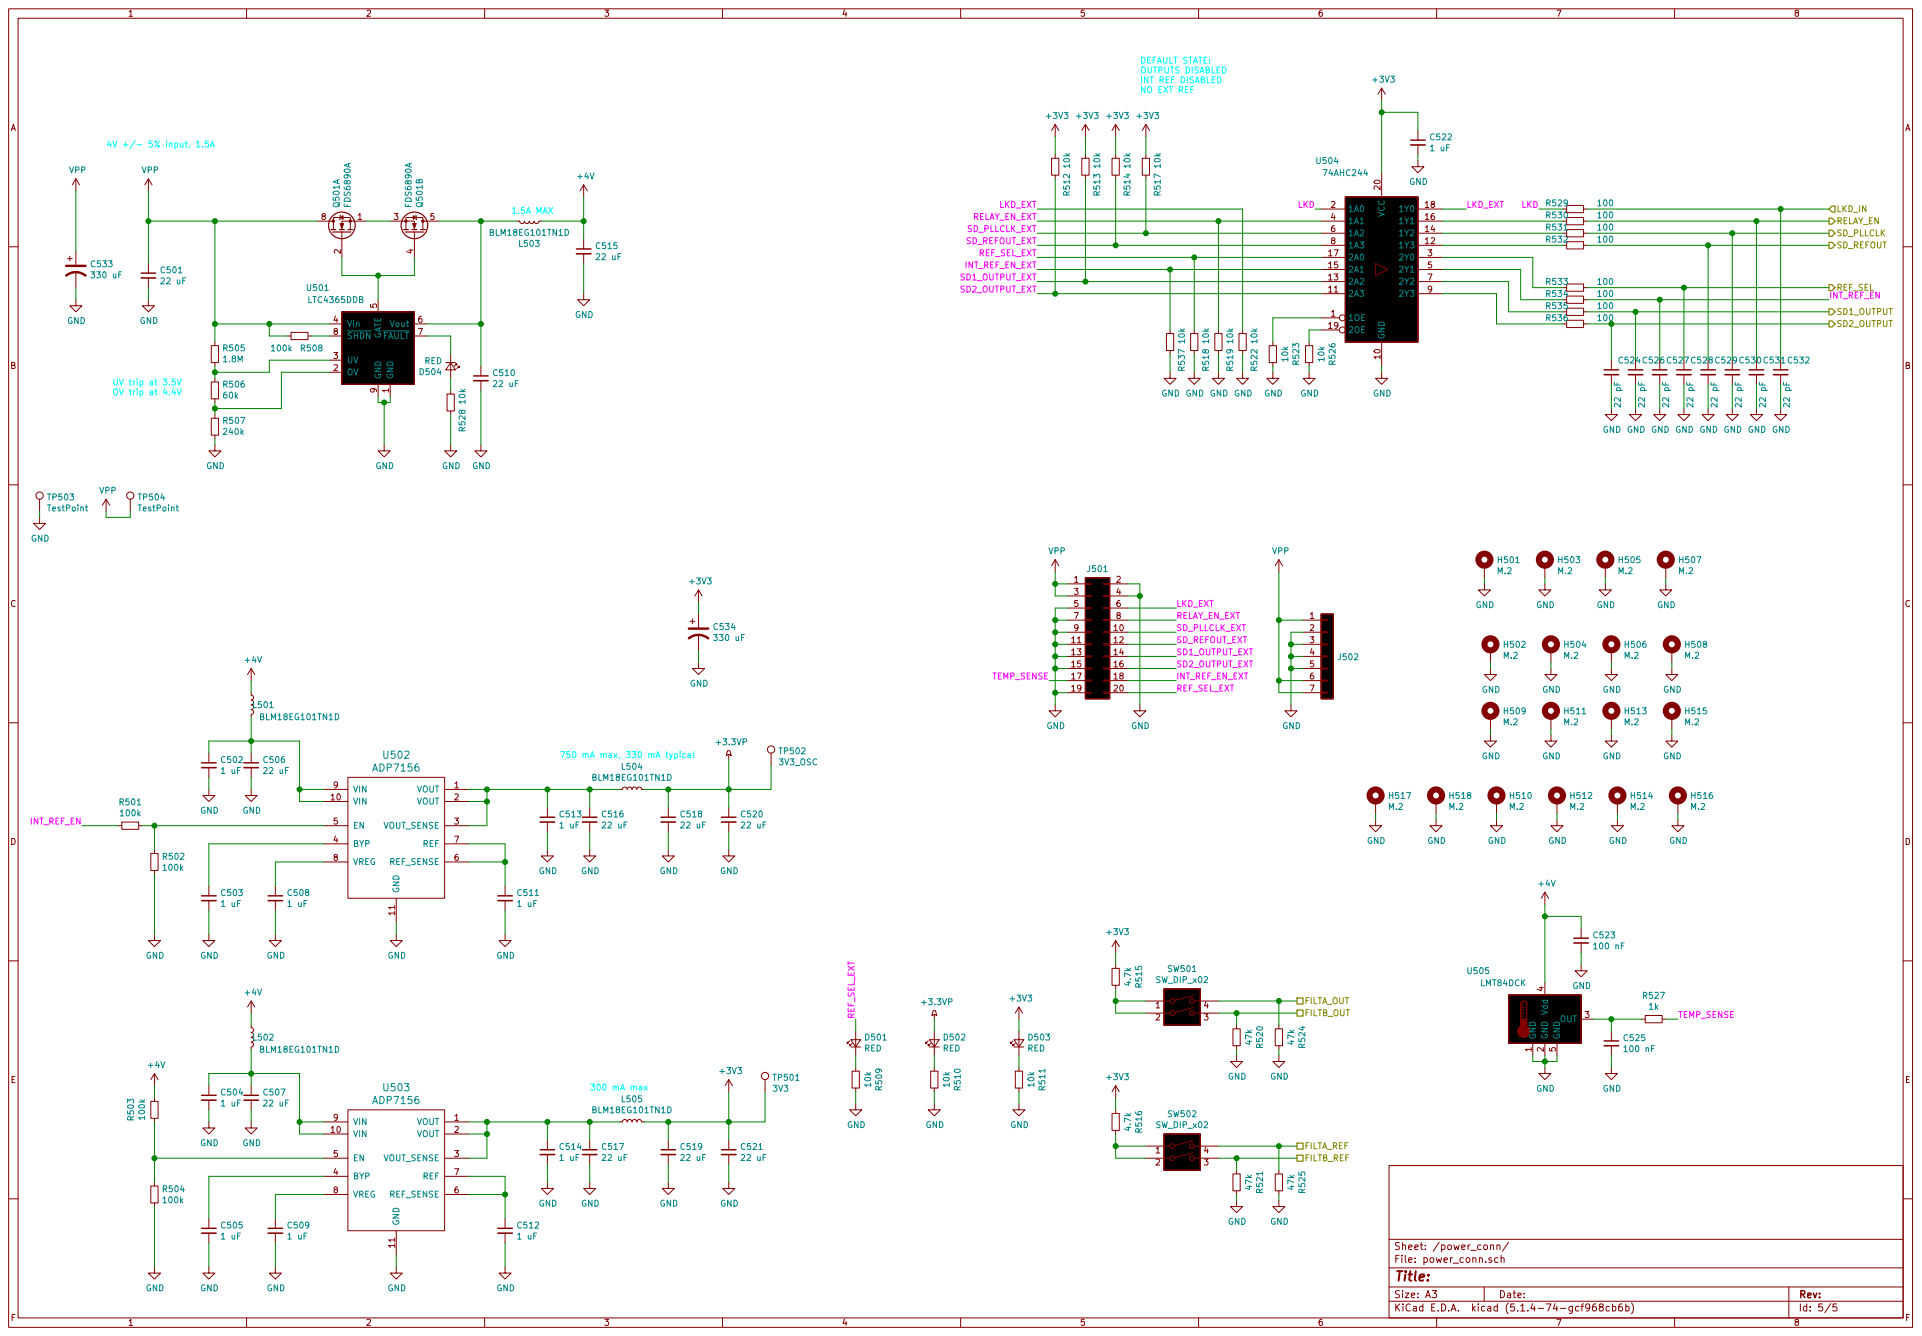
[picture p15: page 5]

DEFAULT STATE: OUTPUTS DISABLED

1.5A MAX UV trip at 3.5V

5 Vout 6 FAULT 7 SHDN 8 GND

1 OV 2 UV 3 Vin 4 GATE

C532 22 pF C531 22 pF C530 22 pF C529 22 pF C528 22 pF GND

750 mA max, 330 mA typical

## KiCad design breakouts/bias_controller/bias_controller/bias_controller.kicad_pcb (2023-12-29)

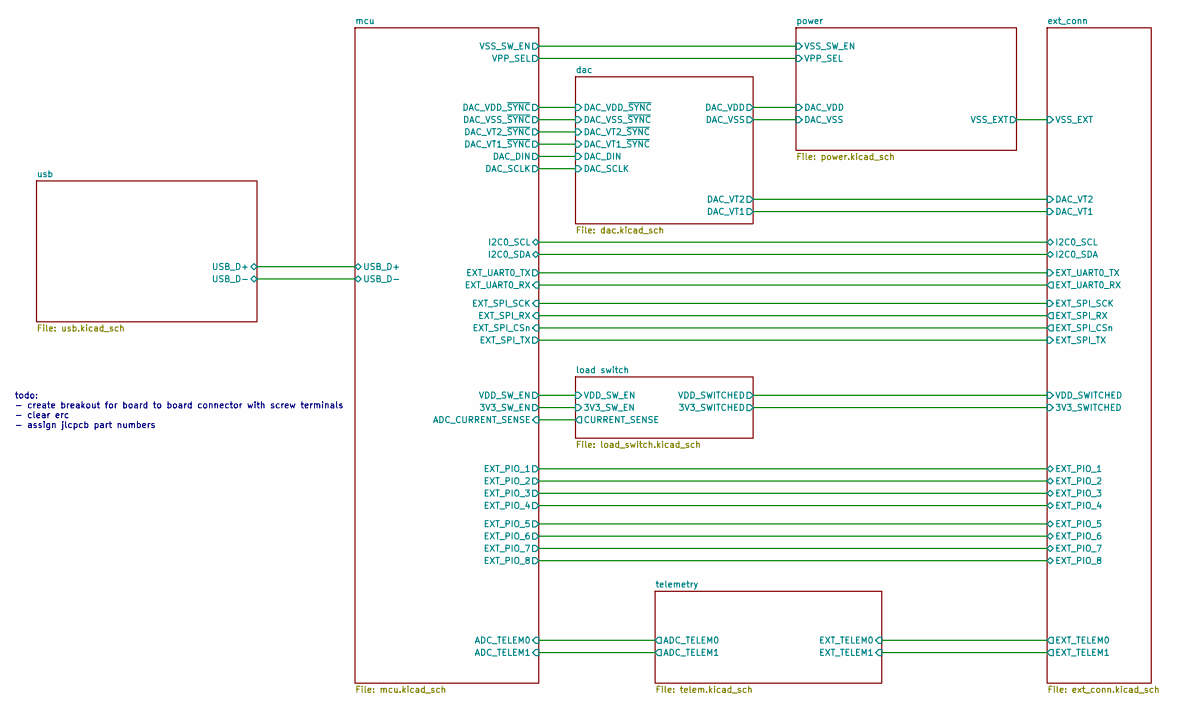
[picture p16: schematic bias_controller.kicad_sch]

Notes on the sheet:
todo: - create breakout for board to board connector with screw terminals - clear erc - assign jlcpcb part numbers

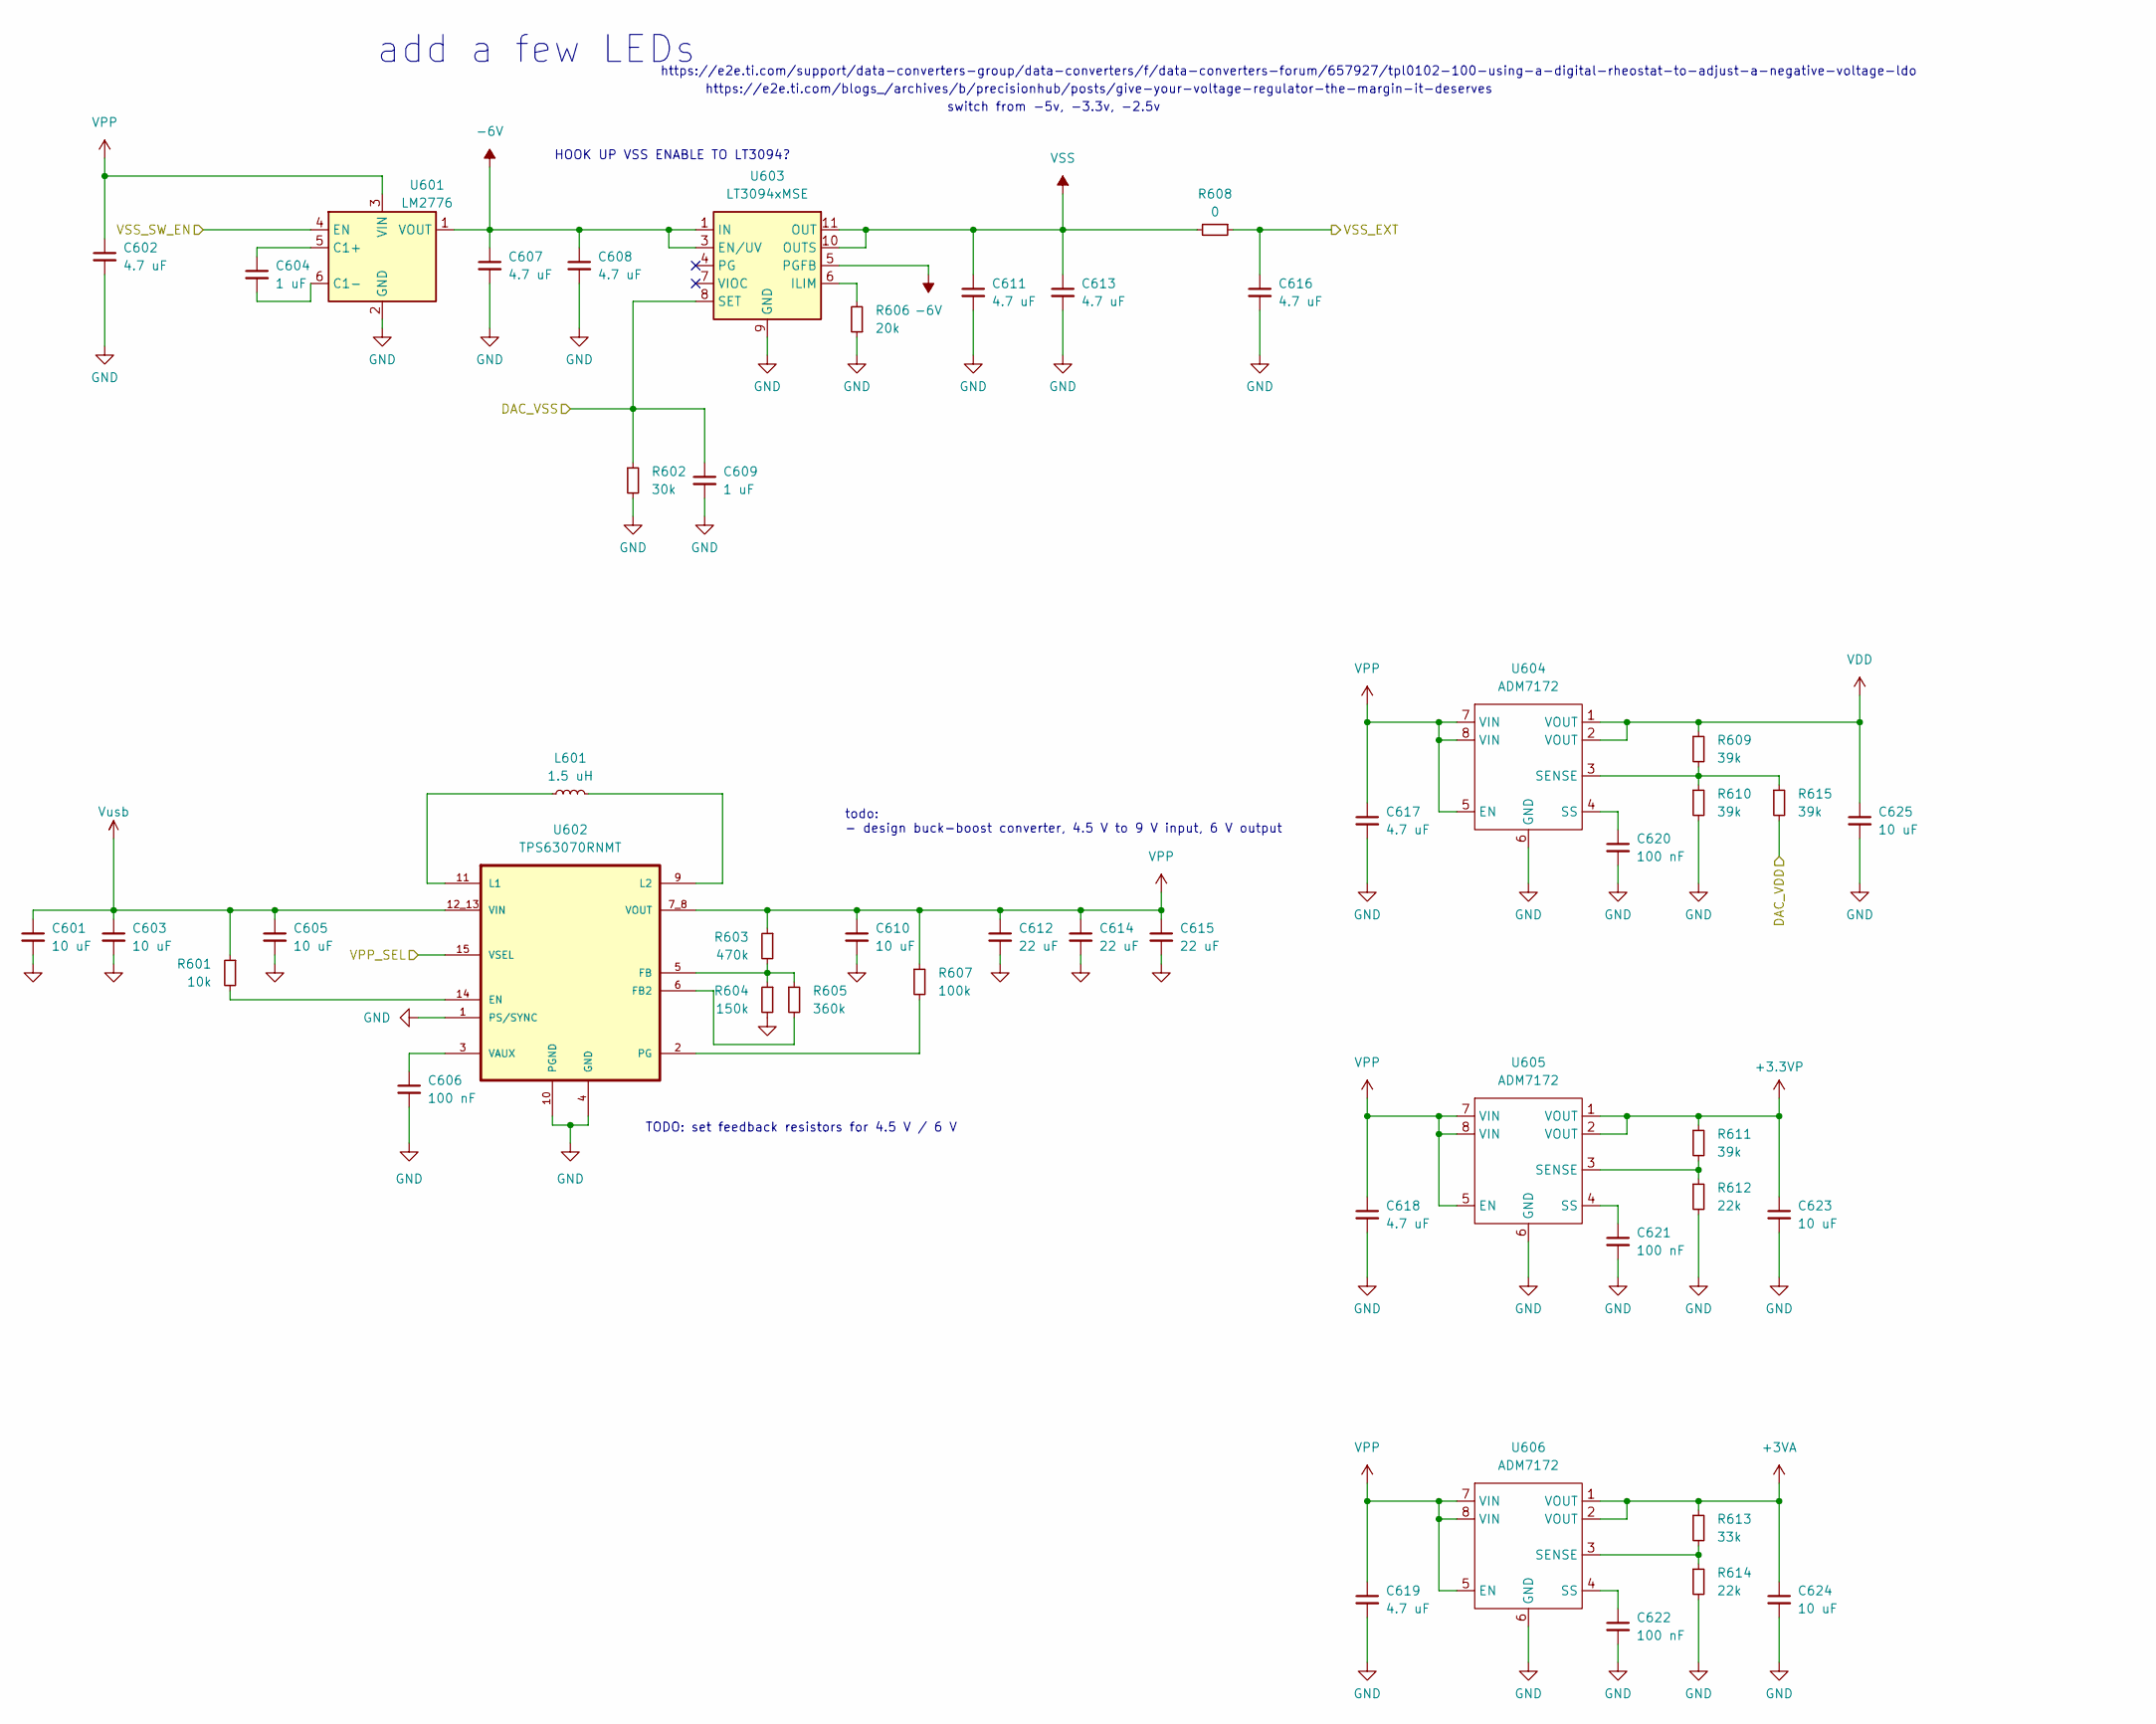
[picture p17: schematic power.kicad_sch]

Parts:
C601, C603, C605, C610, C623, C624, C625: 10 uF; C_0603_1608Metric
C602, C607, C608, C611, C613, C616, C617, C618, C619: 4.7 uF; C_0603_1608Metric
C604, C609: 1 uF; C_0402_1005Metric
C606, C620, C621, C622: 100 nF; C_0402_1005Metric
C612, C614, C615: 22 uF; C_0805_2012Metric
L601: 1.5 uH; L_Coilcraft_XxL4020
R601: 10k; R_0402_1005Metric
R602: 30k; R_0402_1005Metric
R603: 470k; R_0402_1005Metric
R604: 150k; R_0402_1005Metric
R605: 360k; R_0402_1005Metric
R606: 20k; R_0402_1005Metric
R607: 100k; R_0402_1005Metric
R608: 0; R_0402_1005Metric
R609, R610, R611, R615: 39k; R_0402_1005Metric
R612, R614: 22k; R_0402_1005Metric
R613: 33k; R_0402_1005Metric
U601: LM2776; SOT-23-6
U602: TPS63070RNMT; VREG_TPS63070RNMR
U603: LT3094xMSE; MSOP-12-1EP_3x4mm_P0.65mm_EP1.65x2.85mm
U604, U605, U606: ADM7172; LFCSP-8-1EP_3x3mm_P0.5mm_EP1.6x2.34mm

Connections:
+3.3VP: C623.1, R611.1, U605.1 (VOUT), U605.2 (VOUT); also elsewhere on the board
+3VA: C624.1, R613.1, U606.1 (VOUT), U606.2 (VOUT); also elsewhere on the board
-6V: C607.1, C608.1, U601.1 (VOUT), U603.1 (IN), U603.2 (IN), U603.3 (EN/UV), U603.5 (PGFB), U603.13 (IN); also elsewhere on the board
/dac/DAC_VDD: R615.2; also elsewhere on the board
/dac/DAC_VSS: C609.1, R602.1, U603.8 (SET); also elsewhere on the board
/ext_conn/VSS_EXT: C616.1, R608.1; also elsewhere on the board
/mcu/VPP_SEL: U602.15 (VSEL); also elsewhere on the board
/mcu/VSS_SW_EN: U601.4 (EN); also elsewhere on the board
GND: C601.2, C602.2, C603.2, C605.2, C606.2, C607.2, C608.2, C609.2, C610.2, C611.2, C612.2, C613.2, C614.2, C615.2, C616.2, C617.2, C618.2, C619.2, C620.2, C621.2, C622.2, C623.2, C624.2, C625.2, R602.2, R604.2, R606.1, R610.2, R612.2, R614.2, U601.2 (GND), U602.1 (PS/SYNC), U602.4 (GND), U602.10 (PGND), U603.9 (GND), U604.6 (GND), U604.9 (GND), U605.6 (GND), U605.9 (GND), U606.6 (GND), U606.9 (GND); also elsewhere on the board
unnamed: C604.1, U601.5 (C1+)
unnamed: C604.2, U601.6 (C1-)
unnamed: R601.2, U602.14 (EN)
unnamed: R605.2, U602.6 (FB2)
unnamed: R603.2, R604.1, R605.1, U602.5 (FB)
unnamed: L601.1, U602.11 (L1)
unnamed: L601.2, U602.9 (L2)
unnamed: R607.2, U602.2 (PG)
unnamed: C606.1, U602.3 (VAUX)
unnamed: R606.2, U603.6 (ILIM)
unnamed: R609.2, R610.1, R615.1, U604.3 (SENSE)
unnamed: C620.1, U604.4 (SS)
unnamed: R611.2, R612.1, U605.3 (SENSE)
unnamed: C621.1, U605.4 (SS)
unnamed: R613.2, R614.1, U606.3 (SENSE)
unnamed: C622.1, U606.4 (SS)
VDD: C625.1, R609.1, U604.1 (VOUT), U604.2 (VOUT); also elsewhere on the board
VPP: C602.1, C610.1, C612.1, C614.1, C615.1, C617.1, C618.1, C619.1, R603.1, R607.1, U601.3 (VIN), U602.7_8 (VOUT), U604.5 (EN), U604.7 (VIN), U604.8 (VIN), U605.5 (EN), U605.7 (VIN), U605.8 (VIN), U606.5 (EN), U606.7 (VIN), U606.8 (VIN); also elsewhere on the board
VSS: C611.1, C613.1, R608.2, U603.10 (OUTS), U603.11 (OUT), U603.12 (OUT)
Vusb: C601.1, C603.1, C605.1, R601.1, U602.12_13 (VIN); also elsewhere on the board

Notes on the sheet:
TODO: set feedback resistors for 4.5 V / 6 V
https://e2e.ti.com/support/data-converters-group/data-converters/f/data-converters-forum/657927/tpl0102-100-using-a-digital-rheostat-to-adjust-a-negative-voltage-ldo
switch from -5v, -3.3v, -2.5v
HOOK UP VSS ENABLE TO LT3094?
add a few LEDs
https://e2e.ti.com/blogs_/archives/b/precisionhub/posts/give-your-voltage-regulator-the-margin-it-deserves
todo: - design buck-boost converter, 4.5 V to 9 V input, 6 V output

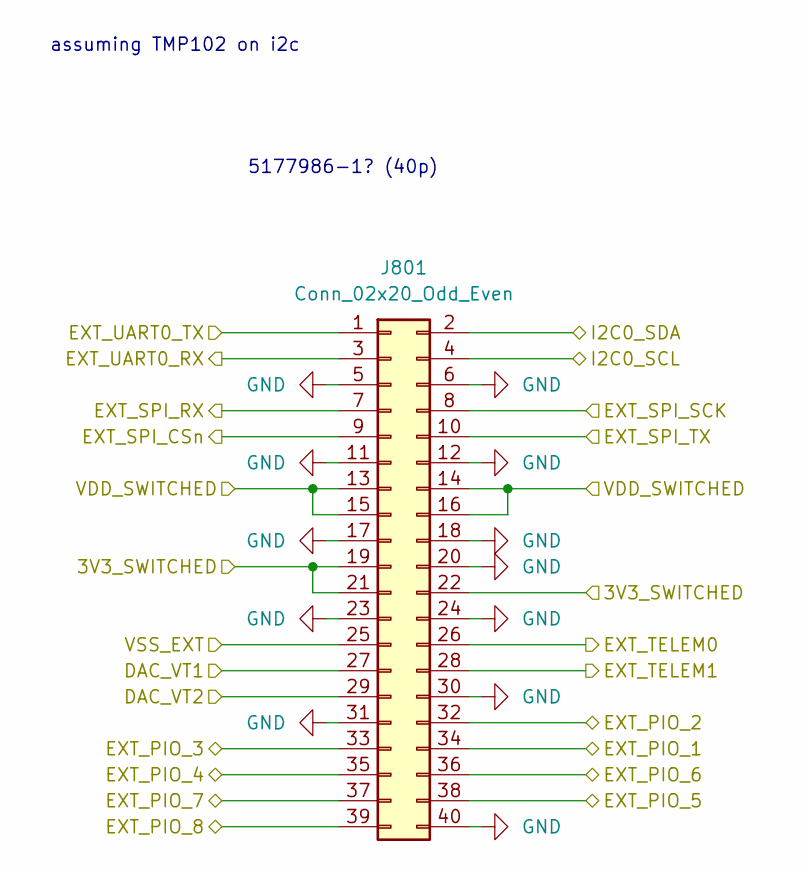
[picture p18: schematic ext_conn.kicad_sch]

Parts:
J801: Conn_02x20_Odd_Even; TE_5177986-1

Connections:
/dac/DAC_VT1: J801.27; also elsewhere on the board
/dac/DAC_VT2: J801.29; also elsewhere on the board
/ext_conn/3V3_SWITCHED: J801.19, J801.21, J801.22; also elsewhere on the board
/ext_conn/EXT_PIO_1: J801.34; also elsewhere on the board
/ext_conn/EXT_PIO_2: J801.32; also elsewhere on the board
/ext_conn/EXT_PIO_3: J801.33; also elsewhere on the board
/ext_conn/EXT_PIO_4: J801.35; also elsewhere on the board
/ext_conn/EXT_PIO_5: J801.38; also elsewhere on the board
/ext_conn/EXT_PIO_6: J801.36; also elsewhere on the board
/ext_conn/EXT_PIO_7: J801.37; also elsewhere on the board
/ext_conn/EXT_PIO_8: J801.39; also elsewhere on the board
/ext_conn/EXT_SPI_CSn: J801.9; also elsewhere on the board
/ext_conn/EXT_SPI_RX: J801.7; also elsewhere on the board
/ext_conn/EXT_SPI_SCK: J801.8; also elsewhere on the board
/ext_conn/EXT_SPI_TX: J801.10; also elsewhere on the board
/ext_conn/EXT_TELEM0: J801.26; also elsewhere on the board
/ext_conn/EXT_TELEM1: J801.28; also elsewhere on the board
/ext_conn/EXT_UART0_RX: J801.3; also elsewhere on the board
/ext_conn/EXT_UART0_TX: J801.1; also elsewhere on the board
/ext_conn/VDD_SWITCHED: J801.13, J801.14, J801.15, J801.16; also elsewhere on the board
/ext_conn/VSS_EXT: J801.25; also elsewhere on the board
/mcu/SCL: J801.4; also elsewhere on the board
/mcu/SDA: J801.2; also elsewhere on the board
GND: J801.5, J801.6, J801.11, J801.12, J801.17, J801.18, J801.20, J801.23, J801.24, J801.30, J801.31, J801.40; also elsewhere on the board

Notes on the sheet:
assuming TMP102 on i2c
5177986-1? (40p)

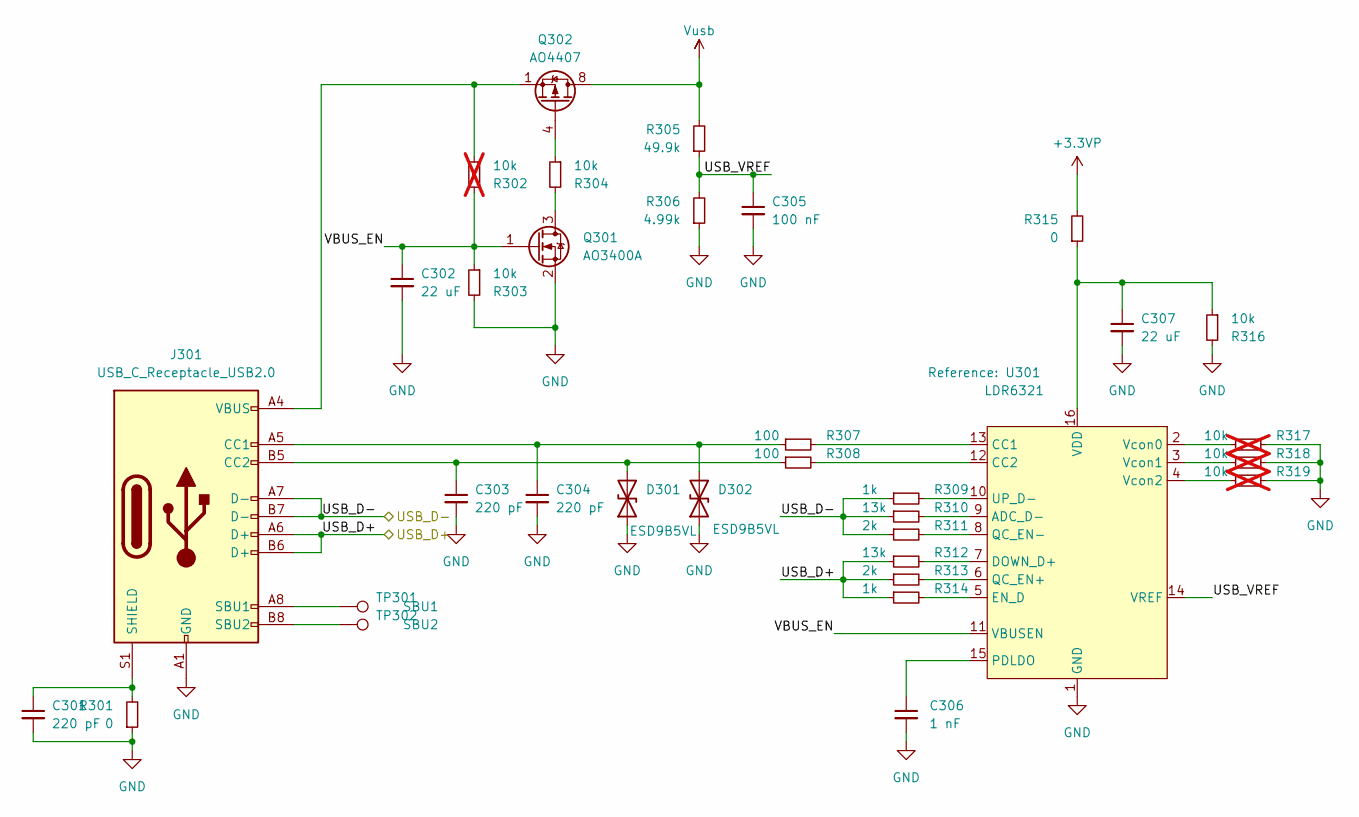
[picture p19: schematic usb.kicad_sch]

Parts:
C301, C303, C304: 220 pF; C_0402_1005Metric
C302: 22 uF; C_0805_2012Metric
C305: 100 nF; C_0402_1005Metric
C306: 1 nF; C_0402_1005Metric
C307: 22 uF; C_0603_1608Metric
D301, D302: ESD9B5VL; DFN1006-2
J301: USB_C_Receptacle_USB2.0; USB_C_Receptacle_G-Switch_GT-USB-7010ASV
Q301: AO3400A; SOT-23
Q302: AO4407; SOIC-8_3.9x4.9mm_P1.27mm
R301, R315: 0; R_0402_1005Metric
R302, R317, R318, R319: 10k; R_0402_1005Metric; not fitted
R303, R304, R316: 10k; R_0402_1005Metric
R305: 49.9k; R_0402_1005Metric
R306: 4.99k; R_0402_1005Metric
R307, R308: 100; R_0402_1005Metric
R309, R314: 1k; R_0402_1005Metric
R310, R312: 13k; R_0402_1005Metric
R311, R313: 2k; R_0402_1005Metric
TP301: SBU1; TestPoint_Pad_D1.0mm
TP302: SBU2; TestPoint_Pad_D1.0mm
U301: LDR6321; SSOP-16_4.4x5.2mm_P0.65mm

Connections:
+3.3VP: R315.2; also elsewhere on the board
/usb/USB_D+: J301.A6 (D+), J301.B6 (D+), R312.1, R313.1, R314.1; also elsewhere on the board
/usb/USB_D-: J301.A7 (D-), J301.B7 (D-), R309.1, R310.1, R311.1; also elsewhere on the board
/usb/USB_VREF: C305.1, R305.1, R306.2, U301.14 (VREF)
/usb/VBUS_EN: C302.1, Q301.1 (G), R302.2, R303.1, U301.11 (VBUSEN)
GND: C301.2, C302.2, C303.2, C304.2, C305.2, C306.2, C307.2, D301.1 (A1), D302.1 (A1), J301.A1 (GND), J301.A12 (GND), J301.B1 (GND), J301.B12 (GND), Q301.2 (S), R301.1, R303.2, R306.1, R316.2, R317.2, R318.2, R319.2, U301.1 (GND); also elsewhere on the board
unnamed: C303.1, D301.2 (A2), J301.B5 (CC2), R308.1
unnamed: C304.1, D302.2 (A2), J301.A5 (CC1), R307.1
unnamed: J301.A8 (SBU1), TP301.1
unnamed: J301.B8 (SBU2), TP302.1
unnamed: C301.1, J301.S1 (SHIELD), R301.2
unnamed: J301.A4 (VBUS), J301.A9 (VBUS), J301.B4 (VBUS), J301.B9 (VBUS), Q302.1 (S), Q302.2 (S), Q302.3 (S), R302.1
unnamed: Q301.3 (D), R304.2
unnamed: Q302.4 (G), R304.1
unnamed: R310.2, U301.9 (ADC_D-)
unnamed: R307.2, U301.13 (CC1)
unnamed: R308.2, U301.12 (CC2)
unnamed: R312.2, U301.7 (DOWN_D+)
unnamed: R314.2, U301.5 (EN_D)
unnamed: C306.1, U301.15 (PDLDO)
unnamed: R313.2, U301.6 (QC_EN+)
unnamed: R311.2, U301.8 (QC_EN-)
unnamed: R309.2, U301.10 (UP_D-)
unnamed: C307.1, R315.1, R316.1, U301.16 (VDD)
unnamed: R317.1, U301.2 (Vcon0)
unnamed: R318.1, U301.3 (Vcon1)
unnamed: R319.1, U301.4 (Vcon2)
Vusb: Q302.5 (D), Q302.6 (D), Q302.7 (D), Q302.8 (D), R305.2; also elsewhere on the board

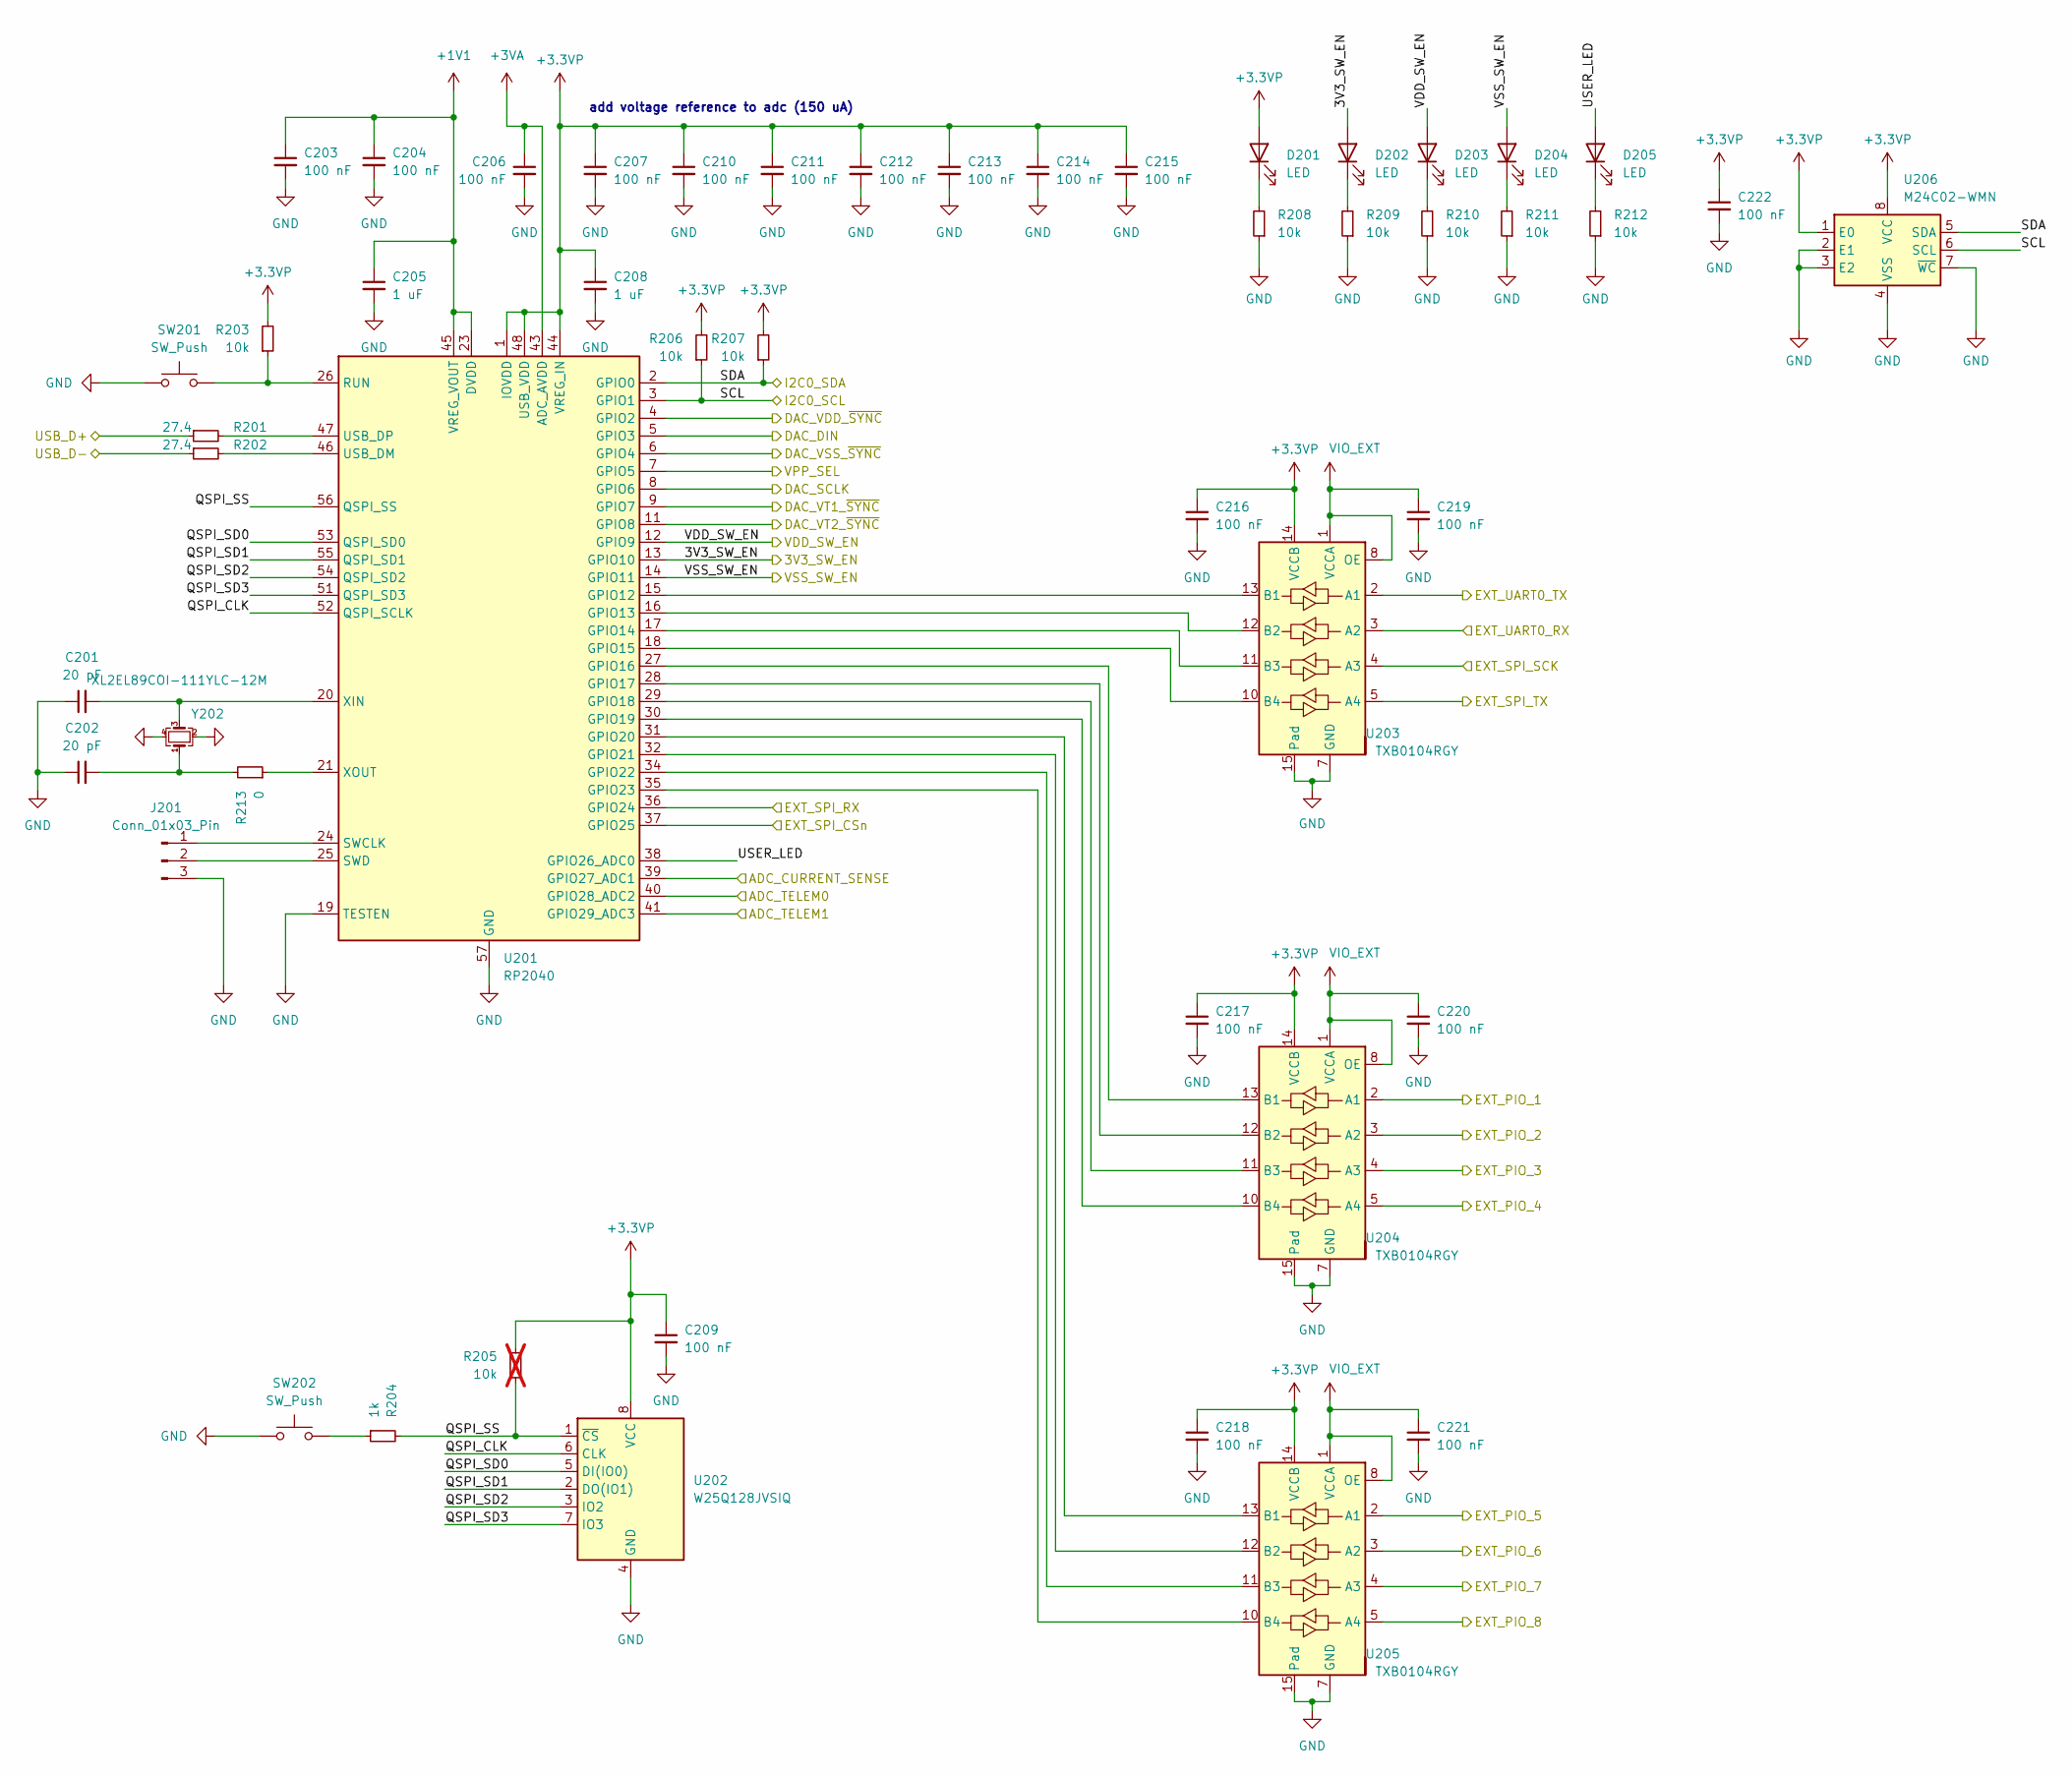
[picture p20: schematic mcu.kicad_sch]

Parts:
C201, C202: 20 pF; C_0402_1005Metric
C203, C204, C206, C207, C209, C210, C211, C212, C213, C214, C215, C216, C217, C218, C219, C220, C221, C222: 100 nF; C_0402_1005Metric
C205, C208: 1 uF; C_0402_1005Metric
D201, D202, D203, D204, D205: LED; LED_0603_1608Metric
J201: Conn_01x03_Pin; PinHeader_1x03_P2.54mm_Vertical
R201, R202: 27.4; R_0402_1005Metric
R203, R206, R207, R208, R209, R210, R211, R212: 10k; R_0402_1005Metric
R204: 1k; R_0402_1005Metric
R205: 10k; R_0402_1005Metric; not fitted
R213: 0; R_0402_1005Metric
SW201, SW202: SW_Push; SW_Push_1P1T_XKB_TS-1187A
U201: RP2040; QFN-56-1EP_7x7mm_P0.4mm_EP3.2x3.2mm
U202: W25Q128JVSIQ; SOIC-8_5.23x5.23mm_P1.27mm
U203, U204, U205: TXB0104RGY; Texas_S-PVQFN-N14
U206: M24C02-WMN; SOIC-8_3.9x4.9mm_P1.27mm
Y202: XL2EL89COI-111YLC-12M; Crystal_SMD_3225-4Pin_3.2x2.5mm

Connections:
+1V1: C203.1, C204.1, C205.1, U201.23 (DVDD), U201.45 (VREG_VOUT), U201.50 (DVDD)
+3.3VP: C207.1, C208.1, C209.1, C210.1, C211.1, C212.1, C213.1, C214.1, C215.1, C216.1, C217.1, C218.1, C222.1, D201.2 (A), R203.2, R205.2, R206.2, R207.2, U201.1 (IOVDD), U201.10 (IOVDD), U201.22 (IOVDD), U201.33 (IOVDD), U201.42 (IOVDD), U201.44 (VREG_IN), U201.48 (USB_VDD), U201.49 (IOVDD), U202.8 (VCC), U203.14 (VCCB), U204.14 (VCCB), U205.14 (VCCB), U206.1 (E0), U206.8 (VCC); also elsewhere on the board
+3VA: C206.1, U201.43 (ADC_AVDD); also elsewhere on the board
/dac/DAC_DIN: U201.5 (GPIO3); also elsewhere on the board
/dac/DAC_SCLK: U201.8 (GPIO6); also elsewhere on the board
/dac/DAC_VDD_~SYNC: U201.4 (GPIO2); also elsewhere on the board
/dac/DAC_VSS_~SYNC: U201.6 (GPIO4); also elsewhere on the board
/dac/DAC_VT1_~SYNC: U201.9 (GPIO7); also elsewhere on the board
/dac/DAC_VT2_~SYNC: U201.11 (GPIO8); also elsewhere on the board
/ext_conn/EXT_PIO_1: U204.2 (A1); also elsewhere on the board
/ext_conn/EXT_PIO_2: U204.3 (A2); also elsewhere on the board
/ext_conn/EXT_PIO_3: U204.4 (A3); also elsewhere on the board
/ext_conn/EXT_PIO_4: U204.5 (A4); also elsewhere on the board
/ext_conn/EXT_PIO_5: U205.2 (A1); also elsewhere on the board
/ext_conn/EXT_PIO_6: U205.3 (A2); also elsewhere on the board
/ext_conn/EXT_PIO_7: U205.4 (A3); also elsewhere on the board
/ext_conn/EXT_PIO_8: U205.5 (A4); also elsewhere on the board
/ext_conn/EXT_SPI_CSn: U201.37 (GPIO25); also elsewhere on the board
/ext_conn/EXT_SPI_RX: U201.36 (GPIO24); also elsewhere on the board
/ext_conn/EXT_SPI_SCK: U203.4 (A3); also elsewhere on the board
/ext_conn/EXT_SPI_TX: U203.5 (A4); also elsewhere on the board
/ext_conn/EXT_UART0_RX: U203.3 (A2); also elsewhere on the board
/ext_conn/EXT_UART0_TX: U203.2 (A1); also elsewhere on the board
/load switch/CURRENT_SENSE: U201.39 (GPIO27_ADC1); also elsewhere on the board
/mcu/3V3_SW_EN: D202.2 (A), U201.13 (GPIO10); also elsewhere on the board
/mcu/ADC_TELEM0: U201.40 (GPIO28_ADC2); also elsewhere on the board
/mcu/ADC_TELEM1: U201.41 (GPIO29_ADC3); also elsewhere on the board
/mcu/QSPI_CLK: U201.52 (QSPI_SCLK), U202.6 (CLK)
/mcu/QSPI_SD0: U201.53 (QSPI_SD0), U202.5 (DI(IO0))
/mcu/QSPI_SD1: U201.55 (QSPI_SD1), U202.2 (DO(IO1))
/mcu/QSPI_SD2: U201.54 (QSPI_SD2), U202.3 (IO2)
/mcu/QSPI_SD3: U201.51 (QSPI_SD3), U202.7 (IO3)
/mcu/QSPI_SS: R204.2, R205.1, U201.56 (QSPI_SS), U202.1 (~CS)
/mcu/SCL: R206.1, U201.3 (GPIO1), U206.6 (SCL); also elsewhere on the board
/mcu/SDA: R207.1, U201.2 (GPIO0), U206.5 (SDA); also elsewhere on the board
/mcu/USER_LED: D205.2 (A), U201.38 (GPIO26_ADC0)
/mcu/VDD_SW_EN: D203.2 (A), U201.12 (GPIO9); also elsewhere on the board
/mcu/VPP_SEL: U201.7 (GPIO5); also elsewhere on the board
/mcu/VSS_SW_EN: D204.2 (A), U201.14 (GPIO11); also elsewhere on the board
/usb/USB_D+: R201.1; also elsewhere on the board
/usb/USB_D-: R202.1; also elsewhere on the board
GND: C201.1, C202.1, C203.2, C204.2, C205.2, C206.2, C207.2, C208.2, C209.2, C210.2, C211.2, C212.2, C213.2, C214.2, C215.2, C216.2, C217.2, C218.2, C219.2, C220.2, C221.2, C222.2, J201.3, R208.1, R209.1, R210.1, R211.1, R212.1, SW201.1, SW202.1, U201.19 (TESTEN), U201.57 (GND), U202.4 (GND), U203.7 (GND), U203.15 (Pad), U204.7 (GND), U204.15 (Pad), U205.7 (GND), U205.15 (Pad), U206.2 (E1), U206.3 (E2), U206.4 (VSS), U206.7 (~WC), Y202.2, Y202.4; also elsewhere on the board
unnamed: C202.2, R213.2, Y202.1
unnamed: D201.1 (K), R208.2
unnamed: D202.1 (K), R209.2
unnamed: D203.1 (K), R210.2
unnamed: D204.1 (K), R211.2
unnamed: D205.1 (K), R212.2
unnamed: J201.1, U201.24 (SWCLK)
unnamed: J201.2, U201.25 (SWD)
unnamed: R204.1, SW202.2
unnamed: U201.15 (GPIO12), U203.13 (B1)
unnamed: U201.16 (GPIO13), U203.12 (B2)
unnamed: U201.17 (GPIO14), U203.11 (B3)
unnamed: U201.18 (GPIO15), U203.10 (B4)
unnamed: U201.27 (GPIO16), U204.13 (B1)
unnamed: U201.28 (GPIO17), U204.12 (B2)
unnamed: U201.29 (GPIO18), U204.11 (B3)
unnamed: U201.30 (GPIO19), U204.10 (B4)
unnamed: U201.31 (GPIO20), U205.13 (B1)
unnamed: U201.32 (GPIO21), U205.12 (B2)
unnamed: U201.34 (GPIO22), U205.11 (B3)
unnamed: U201.35 (GPIO23), U205.10 (B4)
unnamed: R203.1, SW201.2, U201.26 (RUN)
unnamed: R202.2, U201.46 (USB_DM)
unnamed: R201.2, U201.47 (USB_DP)
unnamed: C201.2, U201.20 (XIN), Y202.3
unnamed: R213.1, U201.21 (XOUT)
VIO_EXT: C219.1, C220.1, C221.1, U203.1 (VCCA), U203.8 (OE), U204.1 (VCCA), U204.8 (OE), U205.1 (VCCA), U205.8 (OE)

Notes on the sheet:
add voltage reference to adc (150 uA)

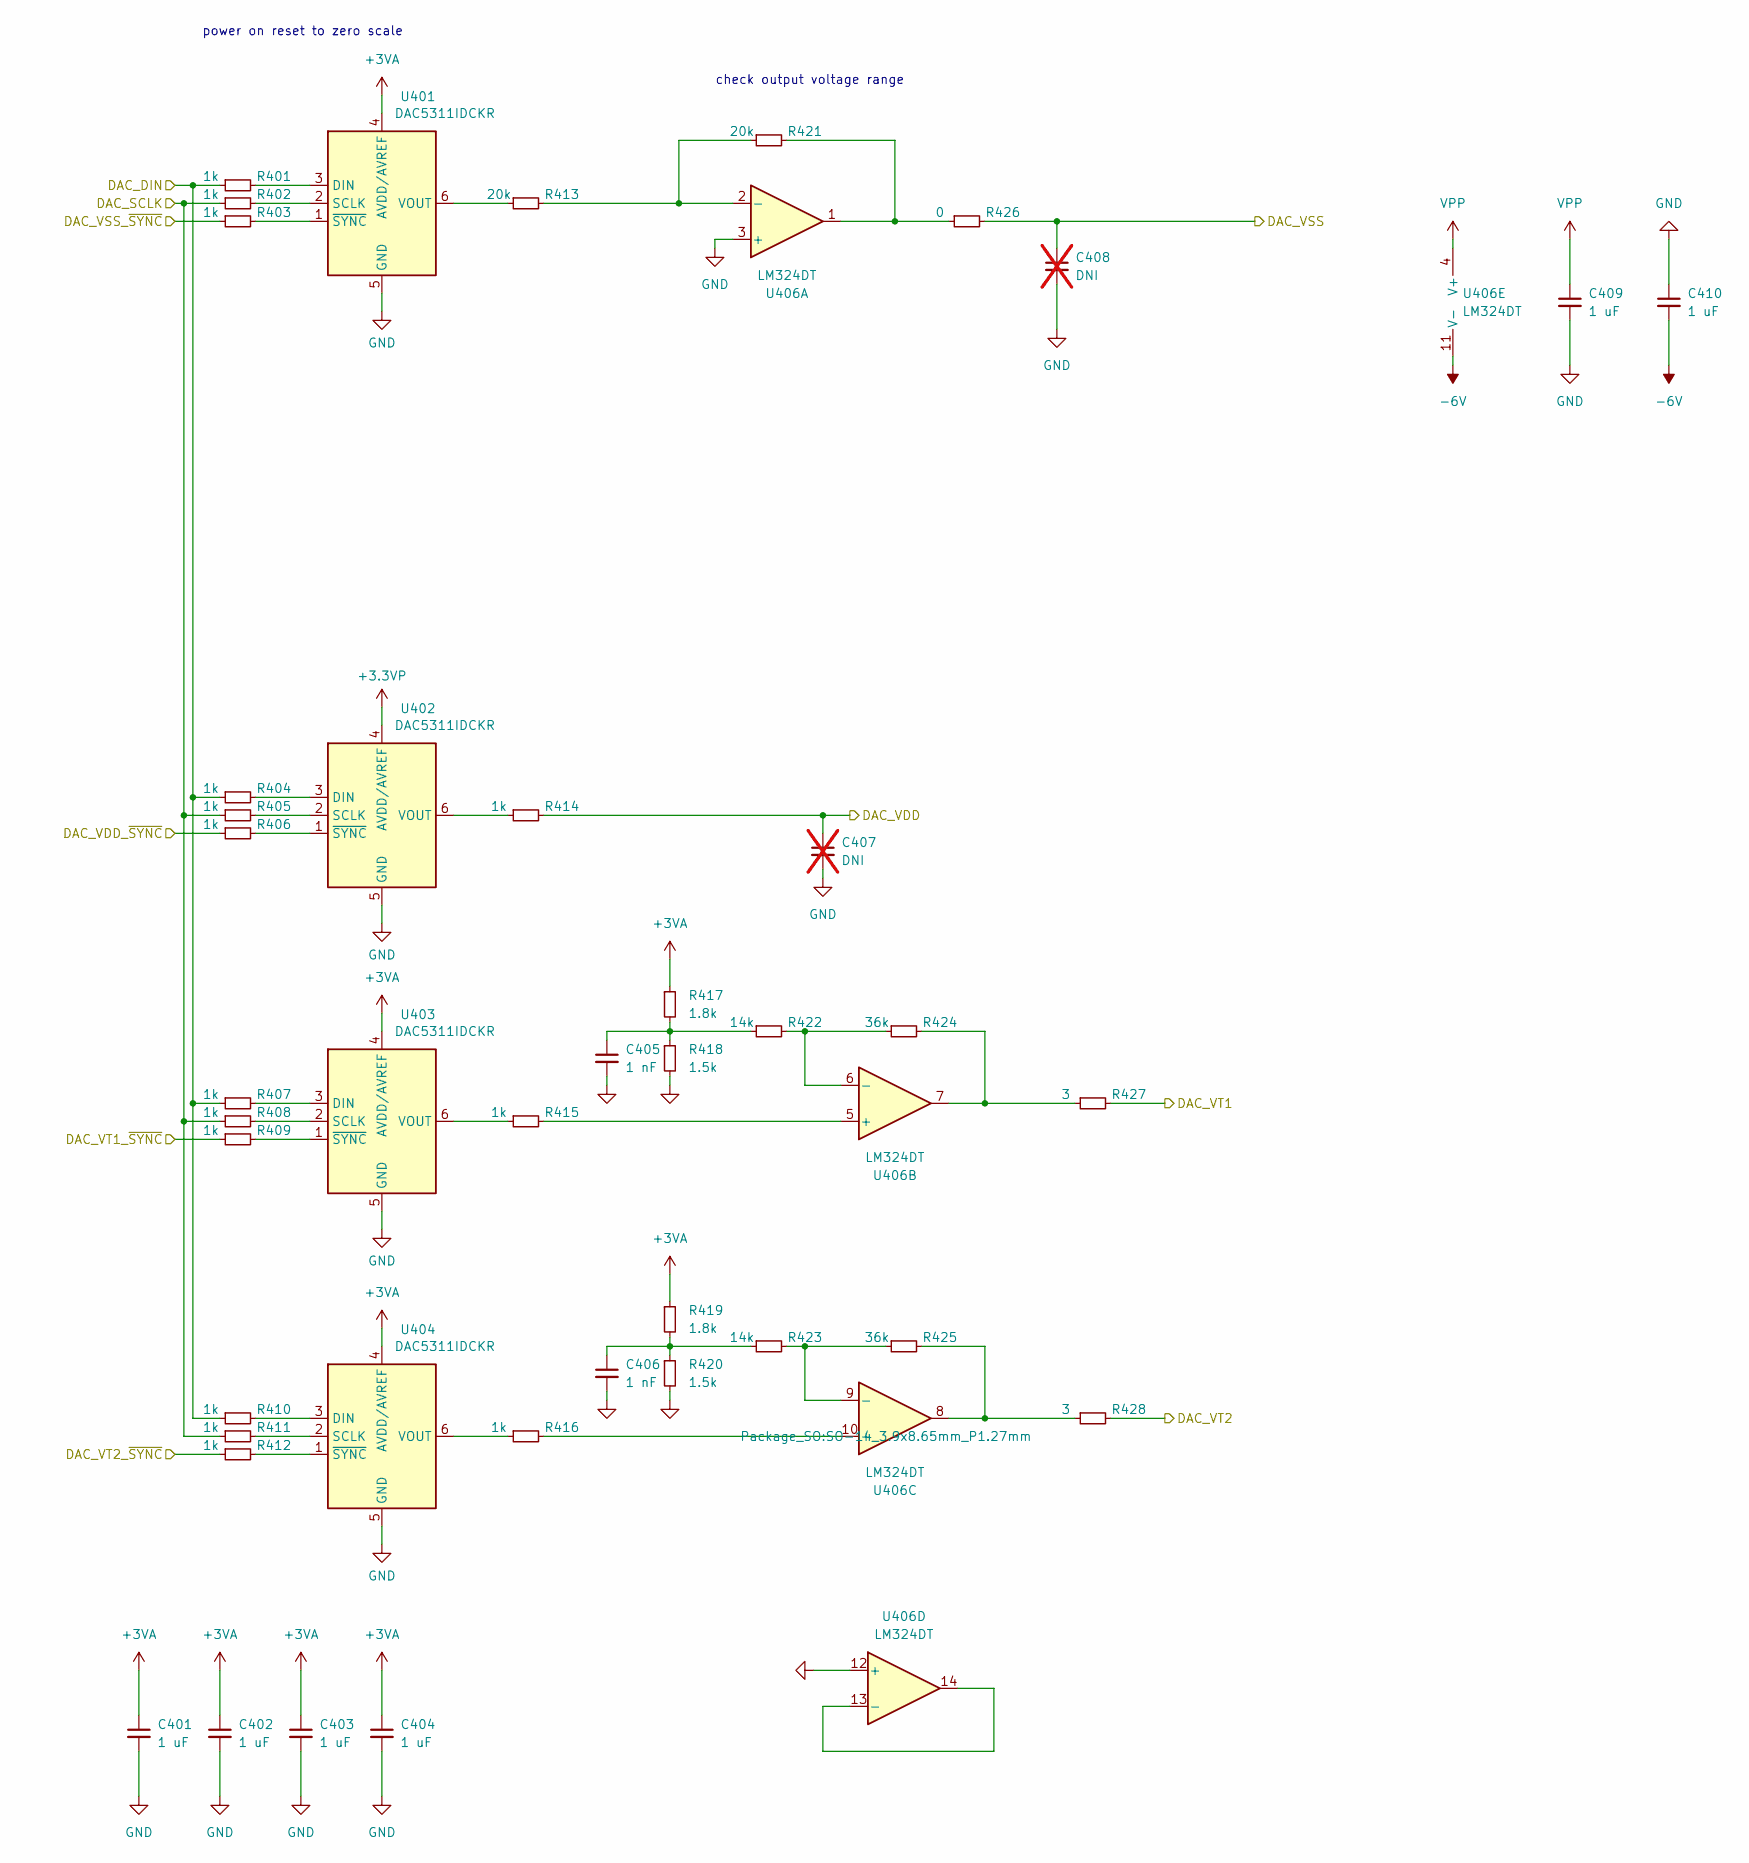
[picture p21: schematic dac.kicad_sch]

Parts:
C401, C402, C403, C404, C409, C410: 1 uF; C_0402_1005Metric
C405, C406: 1 nF; C_0402_1005Metric
C407, C408: DNI; C_0402_1005Metric; not fitted
R401, R402, R403, R404, R405, R406, R407, R408, R409, R410, R411, R412, R414, R415, R416: 1k; R_0402_1005Metric
R413, R421: 20k; R_0402_1005Metric
R417, R419: 1.8k; R_0402_1005Metric
R418, R420: 1.5k; R_0402_1005Metric
R422, R423: 14k; R_0402_1005Metric
R424, R425: 36k; R_0402_1005Metric
R426: 0; R_0402_1005Metric
R427, R428: 3; R_0402_1005Metric
U401, U402, U403, U404: DAC5311IDCKR; SOT-363_SC-70-6
U406: LM324DT; SO-14_3.9x8.65mm_P1.27mm

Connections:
+3.3VP: U402.4 (AVDD/AVREF); also elsewhere on the board
+3VA: C401.1, C402.1, C403.1, C404.1, R417.1, R419.1, U401.4 (AVDD/AVREF), U403.4 (AVDD/AVREF), U404.4 (AVDD/AVREF); also elsewhere on the board
-6V: C410.2, U406.11 (V-); also elsewhere on the board
/dac/DAC_DIN: R401.1, R404.1, R407.1, R410.1; also elsewhere on the board
/dac/DAC_SCLK: R402.1, R405.1, R408.1, R411.1; also elsewhere on the board
/dac/DAC_VDD: C407.1, R414.2; also elsewhere on the board
/dac/DAC_VDD_~SYNC: R406.1; also elsewhere on the board
/dac/DAC_VSS: C408.1, R426.2; also elsewhere on the board
/dac/DAC_VSS_~SYNC: R403.1; also elsewhere on the board
/dac/DAC_VT1: R427.2; also elsewhere on the board
/dac/DAC_VT1_~SYNC: R409.1; also elsewhere on the board
/dac/DAC_VT2: R428.2; also elsewhere on the board
/dac/DAC_VT2_~SYNC: R412.1; also elsewhere on the board
GND: C401.2, C402.2, C403.2, C404.2, C405.2, C406.2, C407.2, C408.2, C409.2, C410.1, R418.2, R420.2, U401.5 (GND), U402.5 (GND), U403.5 (GND), U404.5 (GND), U406.3 (+), U406.12 (+); also elsewhere on the board
unnamed: C405.1, R417.2, R418.1, R422.1
unnamed: C406.1, R419.2, R420.1, R423.1
unnamed: R421.2, R426.1, U406.1
unnamed: R424.2, R427.1, U406.7
unnamed: R425.2, R428.1, U406.8
unnamed: R401.2, U401.3 (DIN)
unnamed: R402.2, U401.2 (SCLK)
unnamed: R413.1, U401.6 (VOUT)
unnamed: R403.2, U401.1 (~SYNC)
unnamed: R404.2, U402.3 (DIN)
unnamed: R405.2, U402.2 (SCLK)
unnamed: R414.1, U402.6 (VOUT)
unnamed: R406.2, U402.1 (~SYNC)
unnamed: R407.2, U403.3 (DIN)
unnamed: R408.2, U403.2 (SCLK)
unnamed: R415.1, U403.6 (VOUT)
unnamed: R409.2, U403.1 (~SYNC)
unnamed: R410.2, U404.3 (DIN)
unnamed: R411.2, U404.2 (SCLK)
unnamed: R416.1, U404.6 (VOUT)
unnamed: R412.2, U404.1 (~SYNC)
unnamed: R413.2, R421.1, U406.2 (-)
unnamed: R415.2, U406.5 (+)
unnamed: R422.2, R424.1, U406.6 (-)
unnamed: R416.2, U406.10 (+)
unnamed: R423.2, R425.1, U406.9 (-)
unnamed: U406.13 (-), U406.14
VPP: C409.1, U406.4 (V+); also elsewhere on the board

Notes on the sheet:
check output voltage range
power on reset to zero scale

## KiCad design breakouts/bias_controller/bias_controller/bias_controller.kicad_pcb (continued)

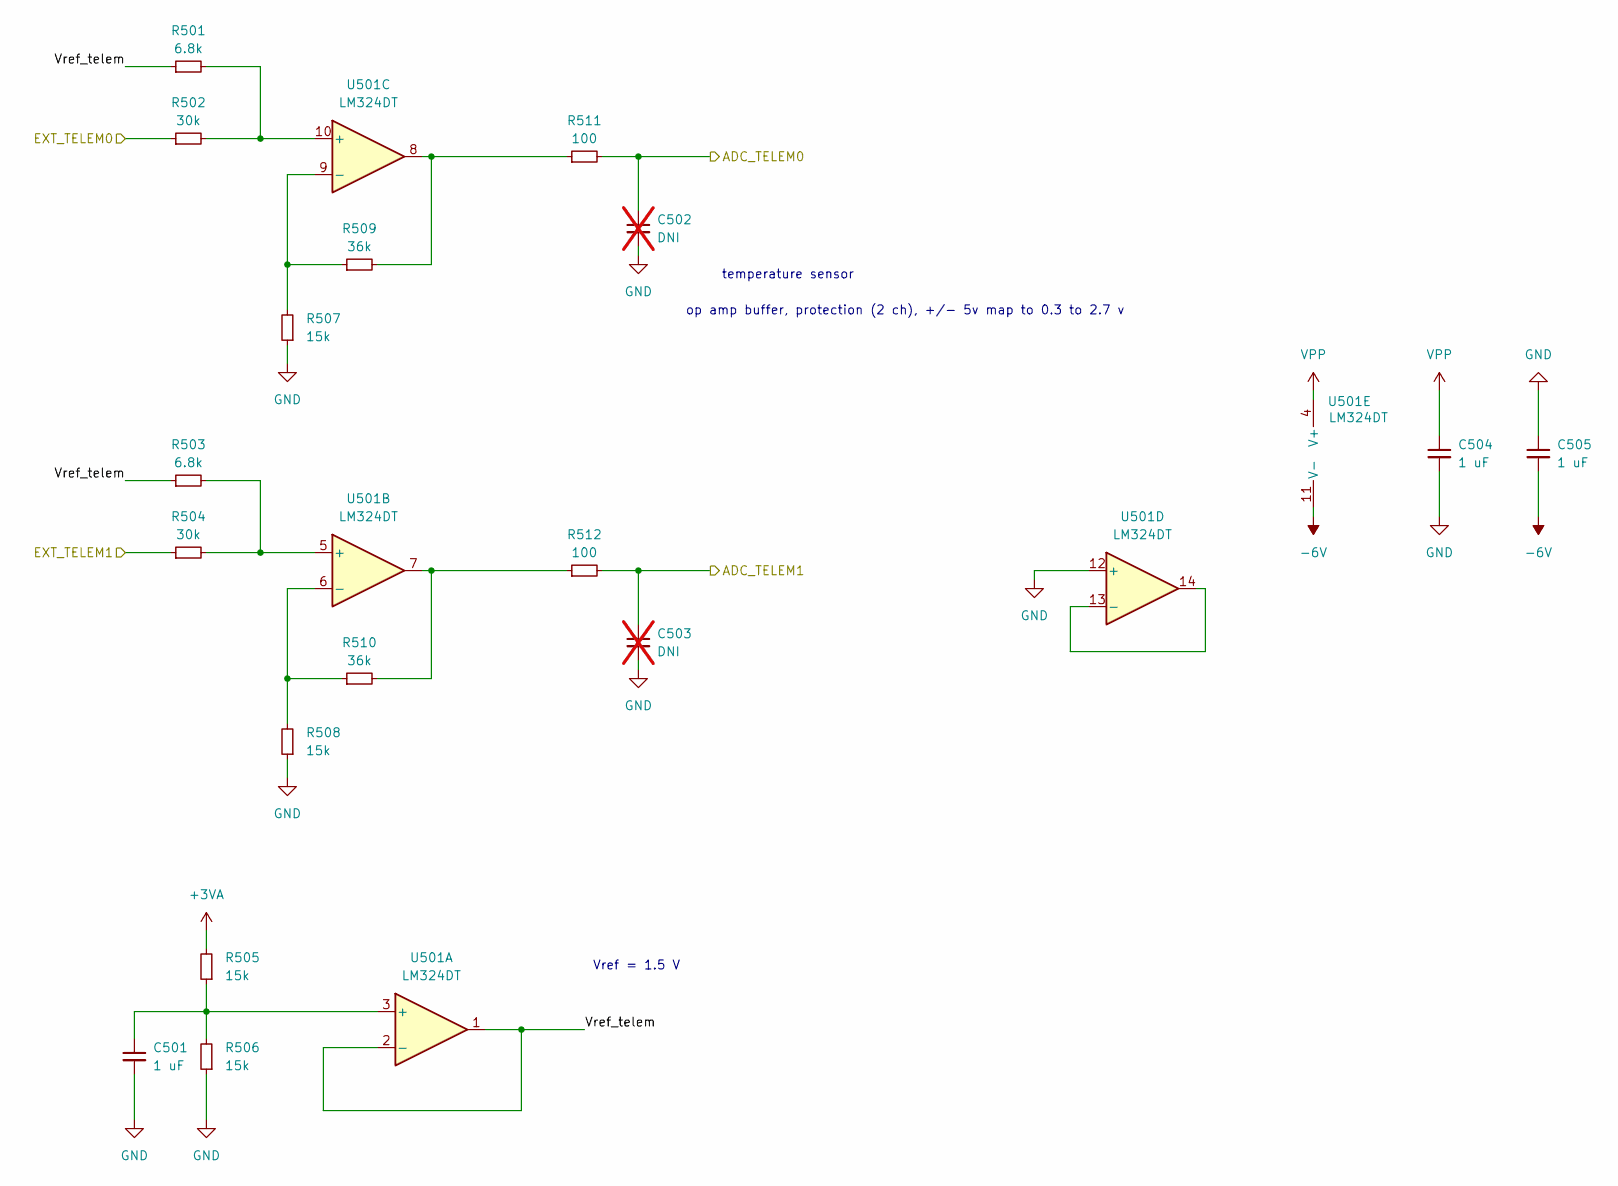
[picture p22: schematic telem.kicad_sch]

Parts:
C501, C504, C505: 1 uF; C_0402_1005Metric
C502, C503: DNI; C_0402_1005Metric; not fitted
R501, R503: 6.8k; R_0402_1005Metric
R502, R504: 30k; R_0402_1005Metric
R505, R506, R507, R508: 15k; R_0402_1005Metric
R509, R510: 36k; R_0402_1005Metric
R511, R512: 100; R_0402_1005Metric
U501: LM324DT; SO-14_3.9x8.65mm_P1.27mm

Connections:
+3VA: R505.2; also elsewhere on the board
-6V: C505.2, U501.11 (V-); also elsewhere on the board
/ext_conn/EXT_TELEM0: R502.1; also elsewhere on the board
/ext_conn/EXT_TELEM1: R504.1; also elsewhere on the board
/mcu/ADC_TELEM0: C502.1, R511.2; also elsewhere on the board
/mcu/ADC_TELEM1: C503.1, R512.2; also elsewhere on the board
/telemetry/Vref_telem: R501.1, R503.1, U501.1, U501.2 (-)
GND: C501.2, C502.2, C503.2, C504.2, C505.1, R506.1, R507.1, R508.1, U501.12 (+); also elsewhere on the board
unnamed: R509.2, R511.1, U501.8
unnamed: R510.2, R512.1, U501.7
unnamed: C501.1, R505.1, R506.2, U501.3 (+)
unnamed: R503.2, R504.2, U501.5 (+)
unnamed: R508.2, R510.1, U501.6 (-)
unnamed: R501.2, R502.2, U501.10 (+)
unnamed: R507.2, R509.1, U501.9 (-)
unnamed: U501.13 (-), U501.14
VPP: C504.1, U501.4 (V+); also elsewhere on the board

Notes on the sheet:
op amp buffer, protection (2 ch), +/- 5v map to 0.3 to 2.7 v
temperature sensor
Vref = 1.5 V

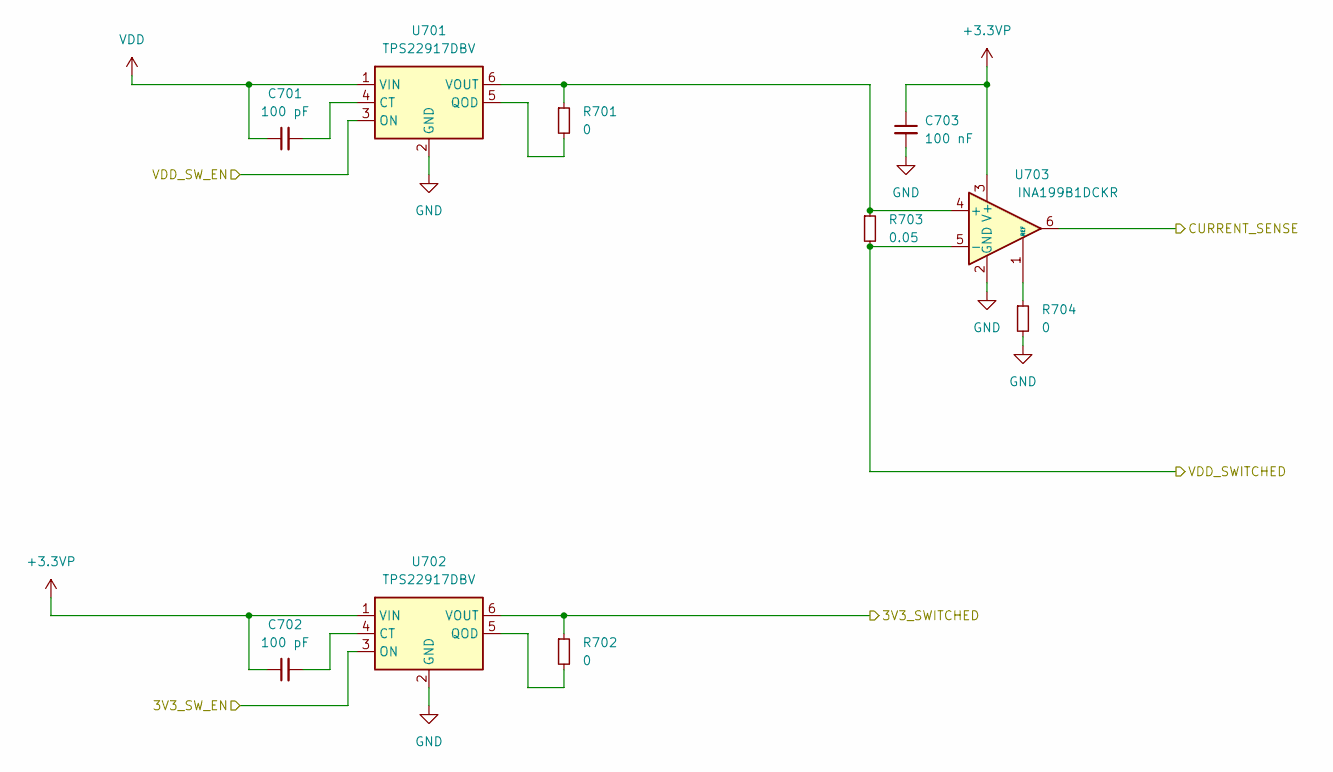
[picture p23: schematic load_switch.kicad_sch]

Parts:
C701, C702: 100 pF; C_0402_1005Metric
C703: 100 nF; C_0402_1005Metric
R701, R702: 0; R_0402_1005Metric
R703: 0.05; R_1206_3216Metric
R704: 0; R_1206_3216Metric
U701, U702: TPS22917DBV; SOT-23-6
U703: INA199B1DCKR; SOT-363_SC-70-6

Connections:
+3.3VP: C702.1, C703.1, U702.1 (VIN), U703.3 (V+); also elsewhere on the board
/ext_conn/3V3_SWITCHED: R702.1, U702.6 (VOUT); also elsewhere on the board
/ext_conn/VDD_SWITCHED: R703.2, U703.5 (-); also elsewhere on the board
/load switch/CURRENT_SENSE: U703.6; also elsewhere on the board
/mcu/3V3_SW_EN: U702.3 (ON); also elsewhere on the board
/mcu/VDD_SW_EN: U701.3 (ON); also elsewhere on the board
GND: C703.2, R704.2, U701.2 (GND), U702.2 (GND), U703.2 (GND); also elsewhere on the board
unnamed: C701.2, U701.4 (CT)
unnamed: R701.2, U701.5 (QOD)
unnamed: R701.1, R703.1, U701.6 (VOUT), U703.4 (+)
unnamed: C702.2, U702.4 (CT)
unnamed: R702.2, U702.5 (QOD)
unnamed: R704.1, U703.1 (REF)
VDD: C701.1, U701.1 (VIN); also elsewhere on the board

Board: 2 copper layers, 203 parts (0 on the bottom side), 164 nets, no tracks yet.

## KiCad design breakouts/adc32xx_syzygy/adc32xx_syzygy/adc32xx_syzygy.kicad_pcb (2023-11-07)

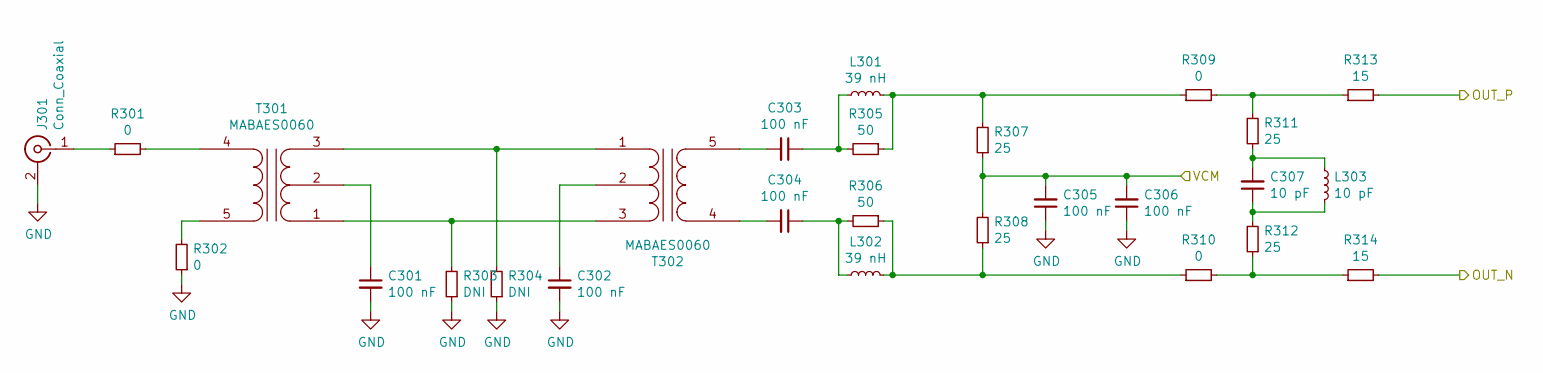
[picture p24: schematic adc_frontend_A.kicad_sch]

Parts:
C301, C302, C303, C304, C305, C306: 100 nF; C_0402_1005Metric
C307: 10 pF; C_0402_1005Metric
J301: Conn_Coaxial; SMA_Cinch_142-0711-821_EdgeMount
L301, L302: 39 nH; R_0402_1005Metric
L303: 10 pF; R_0402_1005Metric
R301, R302, R309, R310: 0; R_0402_1005Metric
R303, R304: DNI; R_0402_1005Metric
R305, R306: 50; R_0402_1005Metric
R307, R308, R311, R312: 25; R_0402_1005Metric
R313, R314: 15; R_0402_1005Metric
T301, T302: MABAES0060; 5LEAD_BALUN_4p83mm_3p3mm

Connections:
/VCM: C305.2, C306.2, R307.1, R308.2; also elsewhere on the board
/adc/IN_A_N: R314.2; also elsewhere on the board
/adc/IN_A_P: R313.2; also elsewhere on the board
GND: C301.2, C302.2, C305.1, C306.1, J301.2 (Ext), R302.1, R303.1, R304.1; also elsewhere on the board
unnamed: C303.1, L301.1, R305.2
unnamed: C304.1, L302.1, R306.2
unnamed: C307.1, L303.2, R312.2
unnamed: C307.2, L303.1, R311.1
unnamed: J301.1 (In), R301.1
unnamed: L301.2, R305.1, R307.2, R309.1
unnamed: L302.2, R306.1, R308.1, R310.1
unnamed: R309.2, R311.2, R313.1
unnamed: R310.2, R312.1, R314.1
unnamed: C301.1, T301.2 (PM)
unnamed: R303.2, T301.1 (PR1), T302.3 (PR2)
unnamed: R304.2, T301.3 (PR2), T302.1 (PR1)
unnamed: R301.2, T301.4 (S1)
unnamed: R302.2, T301.5 (S2)
unnamed: C302.1, T302.2 (PM)
unnamed: C304.2, T302.4 (S1)
unnamed: C303.2, T302.5 (S2)

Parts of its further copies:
C401, C402, C403, C404, C405, C406: 100 nF; C_0402_1005Metric
C407: 10 pF; C_0402_1005Metric
J401: Conn_Coaxial; SMA_Cinch_142-0711-821_EdgeMount
L401, L402: 39 nH; R_0402_1005Metric
L403: 10 pF; R_0402_1005Metric
R401, R402, R409, R410: 0; R_0402_1005Metric
R403, R404: DNI; R_0402_1005Metric
R405, R406: 50; R_0402_1005Metric
R407, R408, R411, R412: 25; R_0402_1005Metric
R413, R414: 15; R_0402_1005Metric
T401, T402: MABAES0060; 5LEAD_BALUN_4p83mm_3p3mm

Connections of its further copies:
/VCM: C405.2, C406.2, R407.1, R408.2; also elsewhere on the board
/adc/IN_B_N: R414.2; also elsewhere on the board
/adc/IN_B_P: R413.2; also elsewhere on the board
GND: C401.2, C402.2, C405.1, C406.1, J401.2 (Ext), R402.1, R403.1, R404.1; also elsewhere on the board
unnamed: C403.1, L401.1, R405.2
unnamed: C404.1, L402.1, R406.2
unnamed: C407.1, L403.2, R412.2
unnamed: C407.2, L403.1, R411.1
unnamed: J401.1 (In), R401.1
unnamed: L401.2, R405.1, R407.2, R409.1
unnamed: L402.2, R406.1, R408.1, R410.1
unnamed: R409.2, R411.2, R413.1
unnamed: R410.2, R412.1, R414.1
unnamed: C401.1, T401.2 (PM)
unnamed: R403.2, T401.1 (PR1), T402.3 (PR2)
unnamed: R404.2, T401.3 (PR2), T402.1 (PR1)
unnamed: R401.2, T401.4 (S1)
unnamed: R402.2, T401.5 (S2)
unnamed: C402.1, T402.2 (PM)
unnamed: C404.2, T402.4 (S1)
unnamed: C403.2, T402.5 (S2)

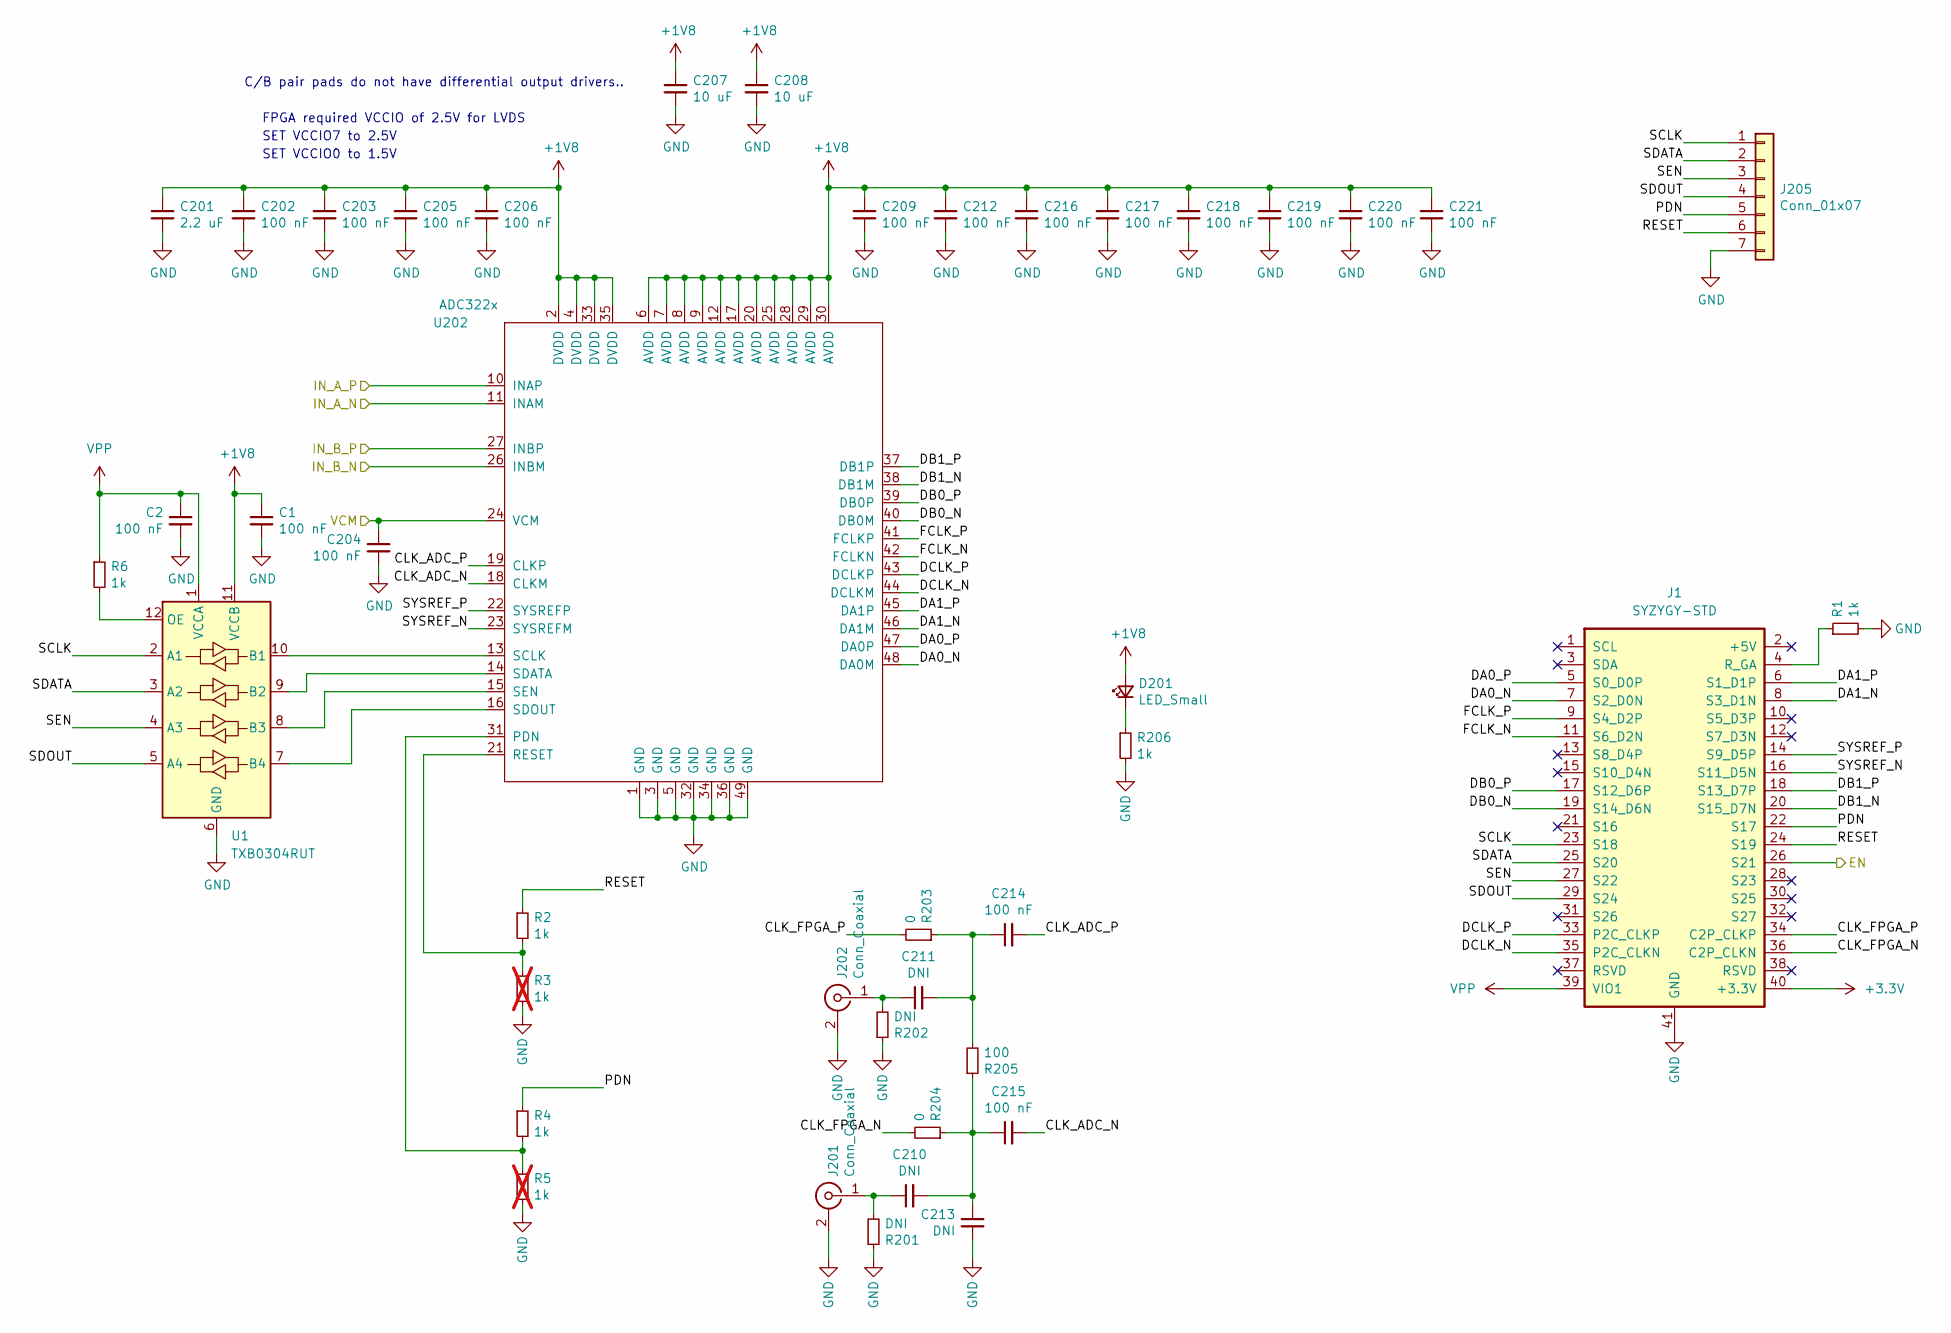
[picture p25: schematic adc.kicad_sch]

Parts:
C1, C2, C202, C203, C204, C205, C206, C209, C212, C214, C215, C216, C217, C218, C219, C220, C221: 100 nF; C_0402_1005Metric
C201: 2.2 uF; C_0603_1608Metric
C207, C208: 10 uF; C_0603_1608Metric
C210, C211, C213: DNI; C_0402_1005Metric
D201: LED_Small; LED_0603_1608Metric
J1: SYZYGY-STD; SYZYGY_standard_pod
J201, J202: Conn_Coaxial; U.FL_Hirose_U.FL-R-SMT-1_Vertical
J205: Conn_01x07; PinSocket_1x07_P2.54mm_Vertical
R1, R2, R4, R6, R206: 1k; R_0402_1005Metric
R3, R5: 1k; R_0402_1005Metric; not fitted
R201, R202: DNI; R_0402_1005Metric
R203, R204: 0; R_0402_1005Metric
R205: 100; R_0402_1005Metric
U1: TXB0304RUT; Texas_R-PUQFN-N12
U202: ADC322x; QFN-48-1EP_7x7mm_P0.5mm_EP5.6x5.6mm

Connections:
+1V8: C1.1, C201.1, C202.1, C203.1, C205.1, C206.1, C207.1, C208.1, C209.1, C212.1, C216.1, C217.1, C218.1, C219.1, C220.1, C221.1, D201.2 (A), U1.11 (VCCB), U202.2 (DVDD), U202.4 (DVDD), U202.6 (AVDD), U202.7 (AVDD), U202.8 (AVDD), U202.9 (AVDD), U202.12 (AVDD), U202.17 (AVDD), U202.20 (AVDD), U202.25 (AVDD), U202.28 (AVDD), U202.29 (AVDD), U202.30 (AVDD), U202.33 (DVDD), U202.35 (DVDD); also elsewhere on the board
+3.3V: J1.40 (+3.3V); also elsewhere on the board
/VCM: C204.1, U202.24 (VCM); also elsewhere on the board
/adc/CLK_ADC_N: C215.2, U202.18 (CLKM)
/adc/CLK_ADC_P: C214.2, U202.19 (CLKP)
/adc/CLK_FPGA_N: J1.36 (C2P_CLKN), R204.2
/adc/CLK_FPGA_P: J1.34 (C2P_CLKP), R203.2
/adc/DA0_N: J1.7 (S2_D0N), U202.48 (DA0M)
/adc/DA0_P: J1.5 (S0_D0P), U202.47 (DA0P)
/adc/DA1_N: J1.8 (S3_D1N), U202.46 (DA1M)
/adc/DA1_P: J1.6 (S1_D1P), U202.45 (DA1P)
/adc/DB0_N: J1.19 (S14_D6N), U202.40 (DB0M)
/adc/DB0_P: J1.17 (S12_D6P), U202.39 (DB0P)
/adc/DB1_N: J1.20 (S15_D7N), U202.38 (DB1M)
/adc/DB1_P: J1.18 (S13_D7P), U202.37 (DB1P)
/adc/DCLK_N: J1.35 (P2C_CLKN), U202.44 (DCLKM)
/adc/DCLK_P: J1.33 (P2C_CLKP), U202.43 (DCLKP)
/adc/EN: J1.26 (S21); also elsewhere on the board
/adc/FCLK_N: J1.11 (S6_D2N), U202.42 (FCLKN)
/adc/FCLK_P: J1.9 (S4_D2P), U202.41 (FCLKP)
/adc/IN_A_N: U202.11 (INAM); also elsewhere on the board
/adc/IN_A_P: U202.10 (INAP); also elsewhere on the board
/adc/IN_B_N: U202.26 (INBM); also elsewhere on the board
/adc/IN_B_P: U202.27 (INBP); also elsewhere on the board
/adc/PDN: J1.22 (S17), J205.5, R4.1
/adc/RESET: J1.24 (S19), J205.6, R2.1
/adc/SCLK: J1.23 (S18), J205.1, U1.2 (A1)
/adc/SDATA: J1.25 (S20), J205.2, U1.3 (A2)
/adc/SDOUT: J1.29 (S24), J205.4, U1.5 (A4)
/adc/SEN: J1.27 (S22), J205.3, U1.4 (A3)
/adc/SYSREF_N: J1.16 (S11_D5N), U202.23 (SYSREFM)
/adc/SYSREF_P: J1.14 (S9_D5P), U202.22 (SYSREFP)
GND: C1.2, C2.2, C201.2, C202.2, C203.2, C204.2, C205.2, C206.2, C207.2, C208.2, C209.2, C212.2, C213.2, C216.2, C217.2, C218.2, C219.2, C220.2, C221.2, J1.41 (GND), J201.2 (Ext), J202.2 (Ext), J205.7, R1.2, R3.2, R5.2, R201.1, R202.1, R206.2, U1.6 (GND), U202.1 (GND), U202.3 (GND), U202.5 (GND), U202.32 (GND), U202.34 (GND), U202.36 (GND), U202.49 (GND); also elsewhere on the board
unnamed: C210.2, C213.1, C215.1, R204.1, R205.1
unnamed: C211.2, C214.1, R203.1, R205.2
unnamed: D201.1 (K), R206.1
unnamed: J1.4 (R_GA), R1.1
unnamed: C210.1, J201.1 (In), R201.2
unnamed: C211.1, J202.1 (In), R202.2
unnamed: U1.10 (B1), U202.13 (SCLK)
unnamed: U1.9 (B2), U202.14 (SDATA)
unnamed: U1.8 (B3), U202.15 (SEN)
unnamed: U1.7 (B4), U202.16 (SDOUT)
unnamed: R6.2, U1.12 (OE)
unnamed: R4.2, R5.1, U202.31 (PDN)
unnamed: R2.2, R3.1, U202.21 (RESET)
VPP: C2.1, J1.39 (VIO1), R6.1, U1.1 (VCCA)

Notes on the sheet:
SET VCCIO0 to 1.5V
SET VCCIO7 to 2.5V
FPGA required VCCIO of 2.5V for LVDS
C/B pair pads do not have differential output drivers..

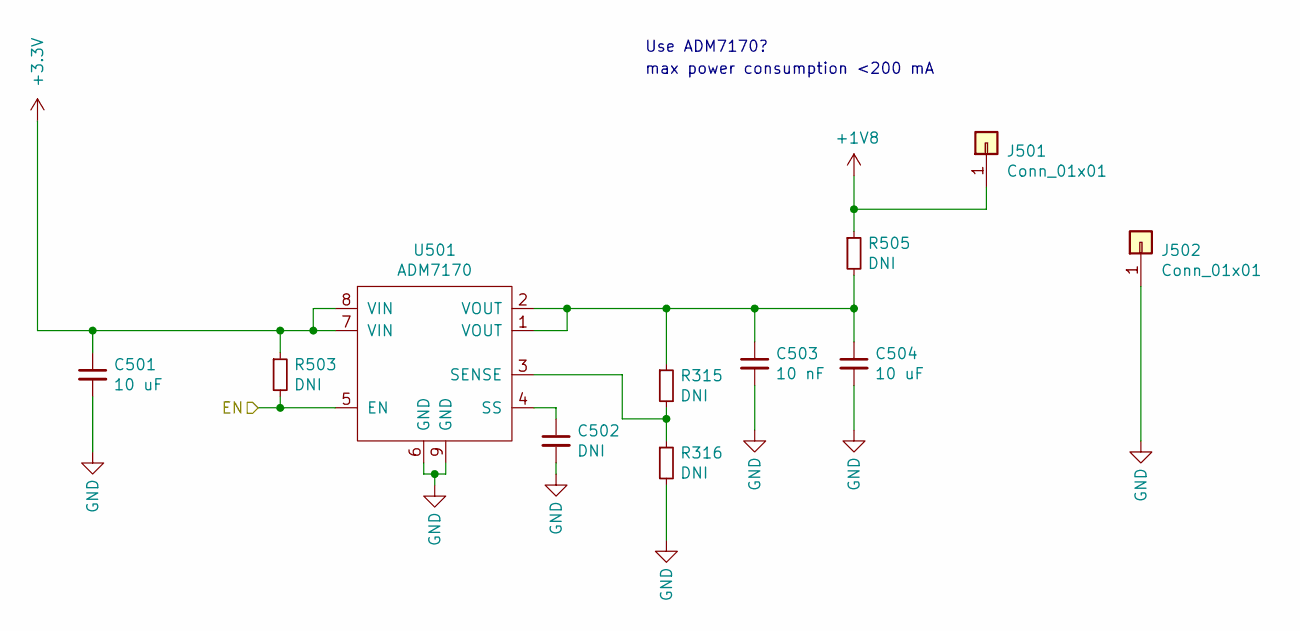
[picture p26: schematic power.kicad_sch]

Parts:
C501, C504: 10 uF; C_0603_1608Metric
C502: DNI; C_0402_1005Metric
C503: 10 nF; C_0402_1005Metric
J501, J502: Conn_01x01; TestPoint_Keystone_5015_Micro-Minature
R315, R316, R503, R505: DNI; R_0402_1005Metric
U501: ADM7170; DFN-8-1EP_3x3mm_P0.5mm_EP1.66x2.38mm

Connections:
+1V8: J501.1, R505.1; also elsewhere on the board
+3.3V: C501.1, R503.1, U501.7 (VIN), U501.8 (VIN); also elsewhere on the board
/adc/EN: R503.2, U501.5 (EN); also elsewhere on the board
GND: C501.2, C502.2, C503.2, C504.2, J502.1, R316.2, U501.6 (GND), U501.9 (GND); also elsewhere on the board
unnamed: C503.1, C504.1, R315.1, R505.2, U501.1 (VOUT), U501.2 (VOUT)
unnamed: R315.2, R316.1, U501.3 (SENSE)
unnamed: C502.1, U501.4 (SS)

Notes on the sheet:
max power consumption <200 mA
Use ADM7170?

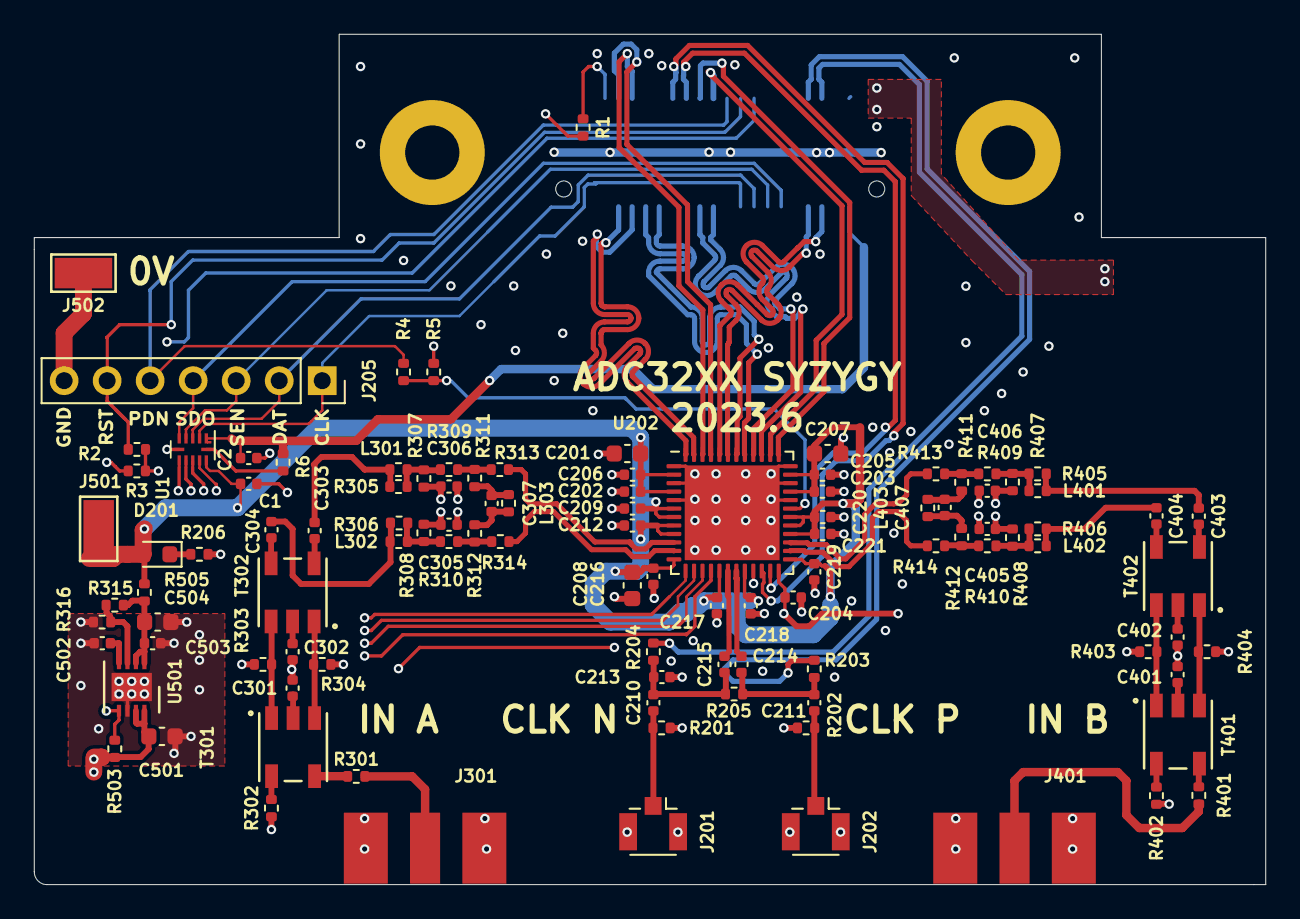
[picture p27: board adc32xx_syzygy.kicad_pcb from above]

Board: 4 copper layers, 72.7 x 50.2 mm, 107 parts (1 on the bottom side), 84 nets.

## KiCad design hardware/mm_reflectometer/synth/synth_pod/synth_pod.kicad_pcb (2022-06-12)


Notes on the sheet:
5V 330 mA typ
5V 50 mA typ
5V 400 mA typ
3.3V 590 mA typ
goals: 100 MHz - 36 GHz 10 dBm to -30 dBm output power -40 dBc harmonic and subharmonic spurs, 2-34 GHz 10 MHz external reference bom <$1000 usb and/or ethernet controlled, usb-pd powered ecp5 litex core
26 pins on SYZYGY standard need to eliminate 4


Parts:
AT701: ATS2012; mpn ATS2012-xxdB-XX
C701, C702, C705, C708, C709, C712, C713, C716, C717: 100 nF; C_0402_1005Metric
C703, C704, C706, C707, C710, C711, C714, C715, C720: 1 uF; C_0402_1005Metric
C718: 100 pF; C_0402_1005Metric
C719: 47 uF; CP_EIA-3528-15_AVX-H
FB701, FB702, FB703, FB704, FB705, FB708: BLM15GG471SZ1D; L_0402_1005Metric
FB706, FB707, FB709, FB710: BLM18BB471SN1D; L_0603_1608Metric
R701, R702, R703, R704: 1k; R_0402_1005Metric
R705: 50; R_0402_1005Metric
R706: 10k; R_0402_1005Metric
R707: 1; R_0402_1005Metric
TP701: Vg1; TestPoint_Pad_D1.5mm
TP702: Bc1; TestPoint_Pad_D1.5mm
TP703: Vg2; TestPoint_Pad_D1.5mm
TP704: Bc2; TestPoint_Pad_D1.5mm
U701: ADRF5042; LGA-24-1EP_3x3mm_P0.4mm_EP1.5x1.5mm_ADI_CC_24_12; mpn ADRF5042BCCZN; digikey# 505-ADRF5042BCCZN-ND
U702, U703: VEMI65AB-HCI; LLP2513-13L
U704: ADRF5730; LGA-24_EP_4x4_Pitch0.5mm; mpn ADRF5730BCCZN; digikey# ADRF5730BCCZN-ND
U705, U706: MAAM-011109; MACOM_LGA9; mpn MAAM-011109-TR1000; digikey# 1465-1284-1-ND
U707: FPC07181; mpn FPC07181; digikey# 1761-1032-ND
U708: LTC5596; DFN-8-1EP_2x2mm_P0.5mm_EP0.25x1.6mm

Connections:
+3.3VA: FB701.1, FB704.1, R707.1, U703.5; also elsewhere on the board
-3V3: FB702.2, FB703.2; also elsewhere on the board
-5VA: FB705.2, FB708.2; also elsewhere on the board
/ATT_CLK: U703.4; also elsewhere on the board
/ATT_LE: U703.6; also elsewhere on the board
/ATT_SERIN: U703.3; also elsewhere on the board
/ATT_SEROUT: U703.2; also elsewhere on the board
/OUT_SW_EN: U702.6; also elsewhere on the board
/OUT_SW_V1: U701.2 (V1), U702.4, U702.9; also elsewhere on the board
/OUT_SW_V2: U701.24 (V2), U702.3, U702.10; also elsewhere on the board
/RF_POW: C718.2, U708.2 (OUT); also elsewhere on the board
/STG1_Vc: R701.1; also elsewhere on the board
/STG1_Vdet: R702.1; also elsewhere on the board
/STG2_Vc: R703.1; also elsewhere on the board
/STG2_Vdet: R704.1; also elsewhere on the board
/bypass/BYPASS_OUT: U701.22 (RF1); also elsewhere on the board
/fundamental_a/FUND_A_OUT: U701.18 (RF2); also elsewhere on the board
/fundamental_b/FUND_B_OUT: U701.14 (RF3); also elsewhere on the board
/highband/HIGHBAND_OUT: U701.10 (RF4); also elsewhere on the board
/panel/RF_OUTPUT: U707.2 (Through); also elsewhere on the board
/rf_output/drain_sequencer1/Vd_sequenced: C719.1, FB707.1, FB710.1; also elsewhere on the board
GND: AT701.3, C701.1, C702.1, C703.1, C704.1, C705.1, C706.1, C707.1, C708.1, C709.1, C710.1, C711.1, C712.1, C713.1, C714.1, C715.1, C716.1, C717.1, C719.2, C720.1, R705.2, U701.3 (GND), U701.5 (GND), U701.7 (LS), U701.9 (GND), U701.11 (GND), U701.12 (GND), U701.13 (GND), U701.15 (GND), U701.16 (GND), U701.17 (GND), U701.19 (GND), U701.20 (GND), U701.21 (GND), U701.23 (GND), U701.25 (GND), U702.13, U703.13, U704.3 (GND), U704.4 (GND), U704.6 (GND), U704.7 (GND), U704.8 (GND), U704.9 (GND), U704.10 (GND), U704.11 (GND), U704.12 (GND), U704.13 (GND), U704.15 (GND), U704.16 (GND), U704.25 (EP), U705.3 (NC), U705.10 (EP), U706.3 (NC), U706.10 (EP), U707.5 (GND), U708.4 (GND), U708.5 (GND), U708.7 (GND), U708.9 (GND); also elsewhere on the board
unnamed: AT701.1, U705.5 (RFout)
unnamed: AT701.2, U706.1 (RFin)
unnamed: C701.2, C703.2, FB701.2, U701.8 (Vdd)
unnamed: C702.2, C704.2, FB702.1, U701.6 (Vss)
unnamed: C705.2, C706.2, FB703.1, U704.17 (VSS)
unnamed: C707.2, C709.2, FB704.2, U704.18 (VDD)
unnamed: C708.2, C710.2, FB705.1, U705.2 (Ve)
unnamed: C711.2, C712.2, FB706.1, FB707.2
unnamed: C713.2, C714.2, FB708.1, U706.2 (Ve)
unnamed: C715.2, C716.2, FB709.1, FB710.2
unnamed: C717.2, C720.2, R706.1, R707.2, U708.1 (Vcc)
unnamed: C718.1, U708.3 (FLTR)
unnamed: FB706.2, U705.6 (Vd)
unnamed: FB709.2, U706.6 (Vd)
unnamed: R701.2, U705.9 (Vc)
unnamed: R702.2, U705.8 (Vdet)
unnamed: R703.2, U706.9 (Vc)
unnamed: R704.2, U706.8 (Vdet)
unnamed: R705.1, U707.4 (Isolated)
unnamed: R706.2, U708.8 (EN)
unnamed: TP701.1, U705.4 (Vg)
unnamed: TP702.1, U705.7 (Bc)
unnamed: TP703.1, U706.4 (Vg)
unnamed: TP704.1, U706.7 (Bc)
unnamed: U701.1 (EN), U702.7
unnamed: U701.4 (RFC), U704.5 (ATTIN)
unnamed: U703.7, U704.1 (LE)
unnamed: U703.8, U704.2 (PS)
unnamed: U703.9, U704.24 (D5/CLK)
unnamed: U703.10, U704.23 (D4/SERIN)
unnamed: U703.11, U704.22 (D3/SEROUT)
unnamed: U704.14 (ATTOUT), U705.1 (RFin)
unnamed: U706.5 (RFout), U707.1 (Input)
unnamed: U707.3 (Coupled), U708.6 (RFin)

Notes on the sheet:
Powering up -3.3V after 3.3VA avoids current transients on 3.3V during ramp up.
MAX DC +/- 12V
For proper MAAM-011109 operation a DC voltage must be applied at the VE(-5 V) and VD(+5 V) pins in that order.
SUB WITH MADT-011000 AND LOG AMPLIFIER?

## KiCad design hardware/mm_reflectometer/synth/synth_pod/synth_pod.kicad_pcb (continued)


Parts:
C1301, C1302, C1305, C1307: 100 nF; C_0402_1005Metric
C1303, C1304, C1306, C1309: 100 pF; C_0402_1005Metric
C1308: 1 uF; C_0402_1005Metric
D1301, D1302: BAS516; D_SOD-523
FB1301: BLM15GG471SZ1D; L_0402_1005Metric
R1301, R1302, R1303, R1304, R1305, R1306, R1307, R1310, R1312, R1314: 47k; R_0402_1005Metric
R1308: 1k; R_0402_1005Metric
R1309: DNI; R_0402_1005Metric
R1311, R1313: 100k; R_0402_1005Metric
U1301: LMT86DCK; SOT-353_SC-70-5
U1302: TLV9151IDCKR; SOT-353_SC-70-5
U1303: AD7298; LFCSP-20-1EP_4x4mm_P0.5mm_EP2.6x2.6mm_ThermalVias
U1304: VEMI65AB-HCI; LLP2513-13L

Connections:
+3.3VA: C1301.1, C1302.1, C1307.1, FB1301.1, R1306.2, R1312.2, R1314.2, U1301.4 (Vdd), U1301.5 (Vdd), U1302.5 (V+), U1303.16 (VDRIVE); also elsewhere on the board
+5VA: R1310.2; also elsewhere on the board
-3V3: R1313.1; also elsewhere on the board
-5VA: R1311.1; also elsewhere on the board
/PLL_VT_UNBUF: R1301.1, U1302.1 (+); also elsewhere on the board
/RF_POW: C1309.1, R1308.1, R1308.2, R1309.1, U1303.2 (VIN4); also elsewhere on the board
/STG1_Vdet: R1304.1; also elsewhere on the board
/STG2_Vdet: R1302.1; also elsewhere on the board
/TLM_ADC_DIN: U1304.11; also elsewhere on the board
/TLM_ADC_DOUT: U1304.10; also elsewhere on the board
/TLM_ADC_SCLK: U1304.12; also elsewhere on the board
/TLM_ADC_~CS: U1304.9; also elsewhere on the board
/monitor/3V3_MON: R1306.1, R1307.2, U1303.5 (VIN7)
/monitor/M3V3_MON: D1302.1 (K), R1312.1, R1313.2, U1303.3 (VIN5)
/monitor/M5V_MON: D1301.1 (K), R1310.1, R1311.2, U1303.4 (VIN6)
/monitor/PLL_VT_BUF: U1302.3 (-), U1302.4, U1303.1 (VIN3)
/monitor/STG1_Vdet_DIV: C1304.1, R1304.2, R1305.1, U1303.18 (VIN0)
/monitor/STG2_Vdet_DIV: C1303.1, R1302.2, R1303.1, U1303.19 (VIN1)
/monitor/TEMP_A: U1301.3 (OUT), U1303.20 (VIN2)
GND: C1301.2, C1302.2, C1303.2, C1304.2, C1305.2, C1306.2, C1307.2, C1308.2, C1309.2, D1301.2 (A), D1302.2 (A), R1301.2, R1303.2, R1305.2, R1307.1, R1309.2, U1301.1 (GND), U1301.2 (GND), U1302.2 (V-), U1303.6 (GND1), U1303.9 (GND), U1303.21 (EPAD), U1304.13; also elsewhere on the board
unnamed: C1305.1, C1306.1, FB1301.2, U1303.10 (VDD)
unnamed: C1308.1, U1303.8 (DCAP)
unnamed: R1314.1, U1303.17 (~PD/~RST)
unnamed: U1303.11 (~CS), U1304.4
unnamed: U1303.13 (DIN), U1304.2
unnamed: U1303.14 (DOUT), U1304.3
unnamed: U1303.15 (SCLK), U1304.1

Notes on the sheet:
3.3V Vdd
input, 0 to 2.5V


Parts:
C301: JMP; C_0402_1005Metric
C302, C306, C308, C309, C312, C313, C318: 100 nF; C_0402_1005Metric
C303: 2.2 nF; C_0402_1005Metric
C304, C316, C317: 100 pF; C_0402_1005Metric
C305: 47 pF; C_0402_1005Metric
C307, C319: 2.2 uF; C_0603_1608Metric
C310: 10 uF; C_0805_2012Metric
C311, C314, C315: 10 nF; C_0402_1005Metric
D301: TPD1E1B04; D_0402_1005Metric
FB301, FB302: BLM15AG102SZ1D; L_0402_1005Metric
J301, J302: Conn_Coaxial; SMA_Amphenol_132134-16_Vertical
K301: 1-1462051-1; Relay_SPDT_AXICOM_HF3Series_50ohms_Pitch1.27mm
L301: 110 nH; L_0603_1608Metric
L302: 5.6 uH; L_0805_2012Metric
Q301: IRLML6401; SOT-23
R301, R312: 1k; R_0402_1005Metric
R302: 10k; R_0402_1005Metric
R303: JMP; R_0402_1005Metric
R304, R307, R308, R309, R310, R311, R313: DNI; R_0402_1005Metric
R305: 75; R_0402_1005Metric
R306: 100; R_0402_1005Metric
R314: 50; R_0402_1005Metric
R315, R316: 0; R_0402_1005Metric
T301: TCM2-33WX+; XFMR_TCM2-33WX+; PARTREV A
U301: 74AHC1G04; SOT-353_SC-70-5
U302: DRV8837C; WSON-8-1EP_2x2mm_P0.5mm_EP0.9x1.6mm
U303: LTC6957xMS-2; MSOP-12_3x4mm_P0.65mm
X301: ABLNO-100.000MHZ; Oscillator_SMD_Abracon_ABLNO

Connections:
+3.3VP: FB302.1, Q301.2 (S), R302.2, R309.2, R310.1; also elsewhere on the board
+5VA: C308.1, C309.1, C310.1, U301.5 (VCC), U302.1 (VM), U302.8 (VCC); also elsewhere on the board
/REFSW_SD2: R312.2; also elsewhere on the board
/REF_EN: R301.2; also elsewhere on the board
/REF_IN: C301.2; also elsewhere on the board
/REF_SEL: U301.2, U302.6 (IN1); also elsewhere on the board
/RELAY_EN: U302.7 (~SLEEP); also elsewhere on the board
/refclk/CLK_N: C313.2
/refclk/CLK_P: C312.2
/refclk/PLL_OSC_N: U303.11 (OUT1+); also elsewhere on the board
/refclk/PLL_OSC_P: U303.10 (OUT1-); also elsewhere on the board
GND: C302.2, C303.1, C304.2, C306.2, C307.2, C308.2, C309.2, C310.2, C311.2, C315.2, C316.1, C317.1, C318.2, C319.2, D301.2 (A2), J301.2 (Ext), J302.2 (Ext), K301.2, K301.5, K301.7, K301.10, K301.13, K301.15, K301.17, K301.19, K301.21, L301.1, R304.1, R313.2, R315.2, R316.2, T301.1, T301.2, T301.5, U301.3 (GND), U302.4 (GND), U302.9 (GND), U303.5 (GND), X301.2 (GND); also elsewhere on the board
unnamed: C301.1, R303.2
unnamed: C302.1, Q301.1 (G), R301.1, R302.1
unnamed: C303.2, C305.2, L301.2, R303.1, R304.2, R311.1
unnamed: C304.1, C306.1, C307.1, FB301.2, X301.4 (VDD)
unnamed: C305.1, L302.2
unnamed: C311.1, R306.1
unnamed: C312.1, T301.4
unnamed: C313.1, T301.3
unnamed: C314.1, R314.1, U303.3 (IN+)
unnamed: C314.2, K301.6, R307.1, R313.1
unnamed: C315.1, R314.2, U303.4 (IN-)
unnamed: C316.2, U303.12 (SD1)
unnamed: C317.2, R312.1, U303.7 (SD2)
unnamed: C318.1, C319.1, FB302.2, U303.2 (V+)
unnamed: D301.1 (A1), K301.20, L302.1, R308.1
unnamed: FB301.1, Q301.3 (D)
unnamed: J301.1 (In), U303.9 (OUT2-)
unnamed: J302.1 (In), U303.8 (OUT2+)
unnamed: K301.1, K301.12 (R), U302.3 (OUT2)
unnamed: K301.11, K301.22 (S), U302.2 (OUT1)
unnamed: K301.14, R305.1, R306.2
unnamed: R305.2, X301.3 (RFout)
unnamed: R307.2, R308.2
unnamed: R309.1, R315.1, U303.1 (FILTA)
unnamed: R310.2, R316.1, U303.6 (FILTB)
unnamed: R311.2, T301.6
unnamed: U301.4, U302.5 (IN2)

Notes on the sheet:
33 mA, bistable
0.3 to 3.6Vpp into LMX2820, AC coupled, 50 ohm input impedance
35 mA max


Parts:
C1501: 330 uF; CP_Elec_10x12.5
C1502, C1503, C1506, C1509, C1512: 10 uF; C_0805_2012Metric
C1504, C1505: 100 nF; C_0402_1005Metric
C1507, C1508: 47 uF; CP_EIA-3528-15_AVX-H
C1510, C1511: 2.2 uF; C_0603_1608Metric
C1526: DNI; CP_Elec_10x12.5
D1503: RED; LED_0603_1608Metric
F1501: 2920L200/24DR; Fuse_2920_7451Metric
FB1502: BLM18SP101SN1D; L_0603_1608Metric
J1501: 1725656; TerminalBlock_Phoenix_MPT-0,5-2-2.54_1x02_P2.54mm_Horizontal
J1502: 1053091202; Molex_Nano-Fit_105309-xx02_1x02_P2.50mm_Vertical
Q1501: FDS6890A; SOIC-8_3.9x4.9mm_P1.27mm
R1501, R1503, R1511, R1512, R1515, R1516, R1517, R1518: 10k; R_0402_1005Metric
R1502, R1504, R1508, R1509: DNI; R_0402_1005Metric
R1505: 1.8M; R_0402_1005Metric
R1506: 60k; R_0402_1005Metric
R1507: 240k; R_0402_1005Metric
R1510: 100k; R_0402_1005Metric
R1513, R1514: TBD; R_0402_1005Metric
U1501: LTM4622A; BGA-25_5x5_6.35x6.35mm
U1502: LTC4365DDB; DFN-8-1EP_2x3mm_P0.5mm_EP0.61x2.2mm
U1503: LM3880MF-1AF; SOT-23-6; MPN LM3880MFX-1AF/NOPB

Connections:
+4V: C1507.1, C1510.1, R1511.2, R1516.1, U1501.D1 (VOUT1), U1501.E1 (VOUT1), U1503.1 (VCC); also elsewhere on the board
+5V5: C1508.1, C1511.1, U1501.A1 (VOUT2), U1501.B1 (VOUT2); also elsewhere on the board
+9V: C1502.1, C1506.1, C1509.1, C1512.1, C1526.1, Q1501.5 (D2), Q1501.6 (D2), R1501.2, R1503.2, U1501.A2 (VIN2), U1501.B3 (VIN2), U1501.D3 (VIN1), U1501.E2 (VIN1), U1502.6 (Vout)
/ctrl_power/1V2EN: R1516.2, U1503.6 (FLAG1)
/ctrl_power/3V3EN: R1517.2, U1503.5 (FLAG2)
/ctrl_power/PGOOD_SWITCHING: R1511.1, U1501.B4 (PGOOD2), U1501.D4 (PGOOD1); also elsewhere on the board
/ctrl_power/~FPGA_RESET: R1518.2, U1503.4 (FLAG3); also elsewhere on the board
/rf_power/15V_BIAS_EN: R1515.1, U1503.3 (EN); also elsewhere on the board
GND: C1501.2, C1502.2, C1503.2, C1504.2, C1505.2, C1506.2, C1507.2, C1508.2, C1509.2, C1510.2, C1511.2, C1512.2, C1526.2, J1501.2, J1502.2, R1502.2, R1504.2, R1507.1, R1508.1, R1509.1, R1512.1, R1513.2, R1514.2, R1515.2, U1501.B5 (GND), U1501.C1 (GND), U1501.C2 (GND), U1501.D5 (GND), U1502.1 (GND), U1502.9 (GND), U1503.2 (GND); also elsewhere on the board
unnamed: C1504.1, U1501.E3 (TRACK/SS1)
unnamed: C1505.1, U1501.A3 (TRACK/SS2)
unnamed: D1503.1 (K), U1502.7 (~FAULT)
unnamed: D1503.2 (A), R1512.2
unnamed: F1501.1, J1501.1, J1502.1
unnamed: Q1501.1 (S1), Q1501.3 (S2)
unnamed: Q1501.2 (G1), Q1501.4 (G2), U1502.5 (GATE)
unnamed: FB1502.2, Q1501.7 (D1), Q1501.8 (D1), R1505.2, R1510.2, U1502.4 (Vin)
unnamed: R1501.1, R1502.1, U1501.B2 (RUN2)
unnamed: R1503.1, R1504.1, U1501.D2 (RUN1)
unnamed: R1505.1, R1506.2, U1502.3 (UV)
unnamed: R1506.1, R1507.2, U1502.2 (OV)
unnamed: R1508.2, U1501.C5 (SYNC/MODE)
unnamed: R1509.2, U1501.C4 (FREQ)
unnamed: R1510.1, U1502.8 (~SHDN)
unnamed: R1513.1, U1501.A4 (FB2)
unnamed: R1514.1, U1501.E4 (FB1)
VPP: C1501.1, C1503.1, F1501.2, FB1502.1

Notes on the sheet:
UV trip at 7V OV trip at 21V
SET NEW OV/UV RESISTORS
Turn on at VBUS >4.1V
9V +/- 10% input, TBD A
VERIFY SEQUENCING
Rfb = 60.4k * (0.6 / (Vout - 0.6))


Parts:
C201, C203, C205, C206, C211, C212, C213, C216, C217, C224, C228: 1 uF; C_0402_1005Metric
C202: 4.7 uF; C_0603_1608Metric
C204: DNP; C_0402_1005Metric
C207, C208, C209, C219, C220, C221, C222: 10 nF; C_0402_1005Metric
C210, C214, C223, C226, C230: 100 nF; C_0402_1005Metric
C215: 10 uF; C_0603_1608Metric
C218: 100 nF; C_0603_1608Metric
C225: 470 pF; C_0603_1608Metric
C227: 68 nF; C_1206_3216Metric
C229: 2.2 nF; C_0603_1608Metric
FB201, FB204, FB205: BLM15GG471SZ1D; L_0402_1005Metric
FB202, FB203, FB206: BLM18BB471SN1D; L_0603_1608Metric
R201, R202, R203: DNI; R_0402_1005Metric
R204, R209: 100; R_0402_1005Metric
R205: 47k; R_0603_1608Metric
R206: 0; R_0603_1608Metric
R207: 68.1; R_0603_1608Metric
R208: 18.2; R_0603_1608Metric
U201: VEMI65AB-HCI; LLP2513-13L
U202: LMX2820; Texas_S-PVQFN-N48_EP5.15x5.15mm

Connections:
+3.3VP: FB201.1, FB202.1, FB203.1, FB204.1, FB205.1, FB206.1; also elsewhere on the board
/PLL_CE: U201.1; also elsewhere on the board
/PLL_LD: U201.5; also elsewhere on the board
/PLL_MUTE: U202.37 (MUTE); also elsewhere on the board
/PLL_MUX: U201.6; also elsewhere on the board
/PLL_SCK: U201.2; also elsewhere on the board
/PLL_SDI: U201.3; also elsewhere on the board
/PLL_SYNC: R203.1, R204.1; also elsewhere on the board
/PLL_VT_UNBUF: C218.2, R205.1; also elsewhere on the board
/PLL_~CS: U201.4; also elsewhere on the board
/bypass/BYPASS_IN: C221.2; also elsewhere on the board
/fundamental_a/FUND_A_IN: C222.2; also elsewhere on the board
/fundamental_b/FUND_B_IN: C219.2; also elsewhere on the board
/highband/HIGHBAND_IN: C220.2; also elsewhere on the board
/refclk/PLL_OSC_N: C208.1, R202.1, R209.2; also elsewhere on the board
/refclk/PLL_OSC_P: C207.1, R201.1, R209.1; also elsewhere on the board
GND: C201.1, C202.1, C203.1, C204.1, C205.1, C206.1, C209.1, C210.1, C211.1, C212.1, C213.1, C214.1, C215.1, C216.1, C217.1, C218.1, C223.1, C224.1, C225.2, C226.1, C228.1, C229.2, C230.1, R201.2, R202.2, R203.2, R207.1, U201.13, U202.2 (GND), U202.4 (GND), U202.6 (GND), U202.15 (GND), U202.16 (GND), U202.27 (GND), U202.29 (GND), U202.32 (GND), U202.35 (NC), U202.40 (GND), U202.42 (GND), U202.47 (GND), U202.48 (GND), U202.49 (GND); also elsewhere on the board
unnamed: C201.2, U202.41 (VbiasVAR)
unnamed: C202.2, U202.3 (VbiasVCO)
unnamed: C203.2, U202.34 (VbiasVCO2)
unnamed: C204.2, C206.2, FB201.2, U202.13 (VccCP)
unnamed: C205.2, U202.36 (VrefVCO2)
unnamed: C207.2, U202.8 (OSCIN_P)
unnamed: C208.2, U202.9 (OSCIN_N)
unnamed: C209.2, C211.2, U202.10 (REGIN)
unnamed: C210.2, C212.2, FB202.2, U202.33 (VccBUF2)
unnamed: C213.2, U202.46 (VregVCO)
unnamed: C214.2, C216.2, FB203.2, U202.24 (VccBUF)
unnamed: C215.2, U202.44 (VrefVCO)
unnamed: C217.2, C223.2, FB204.2, U202.45 (VccVCO)
unnamed: C219.1, U202.26 (RFoutB_P)
unnamed: C220.1, U202.25 (RFoutB_N)
unnamed: C221.1, U202.31 (RFoutA_P)
unnamed: C222.1, U202.30 (RFoutA_N)
unnamed: C224.2, C226.2, FB205.2, U202.17 (VccMASH)
unnamed: C225.1, C227.1, R206.2, R208.1
unnamed: C227.2, R207.2
unnamed: C228.2, C230.2, FB206.2, U202.7 (VccDIG)
unnamed: C229.1, R208.2, U202.14 (CPout)
unnamed: R204.2, U202.5 (PSYNC)
unnamed: R205.2, R206.1, U202.43 (Vtune)
unnamed: U201.7, U202.23 (MUXout)
unnamed: U201.8, U202.38 (LD)
unnamed: U201.9, U202.39 (CS#)
unnamed: U201.10, U202.19 (SDI)
unnamed: U201.11, U202.18 (SCK)
unnamed: U201.12, U202.1 (CE)

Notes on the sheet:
SRREQ, RFIN, and PFDIN may be left floating power down in software
decrease to 0.47 uF to accelerate cal see Table 8-2, datasheet


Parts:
C801, C809, C811, C813, C815, C821, C823, C826: 100 pF; C_0402_1005Metric
C802, C804, C810, C812, C814, C816, C822, C824, C825, C827: 100 nF; C_0402_1005Metric
C803: 4.7 uF; C_0402_1005Metric
C817, C818, C819, C820: 10 pF; C_0402_1005Metric
FB801: BLM18BB471SN1D; L_0603_1608Metric
R801: 1k; R_0402_1005Metric
R802, R803, R804, R805, R807, R813, R816, R817: 33k; R_0402_1005Metric
R806, R808, R809: 4.7k; R_0402_1005Metric
R810, R811, R812, R814, R815, R818, R819, R820, R821, R822: 10k; R_0402_1005Metric
TP801, TP802, TP803, TP804: TestPoint; TestPoint_Pad_D1.5mm
U801: LTC2636IDE-LZ10; DFN-14-1EP_3x4mm_P0.5mm_EP1.7x3.3mm; mpn LTC2636-LZ10; digikey# LTC2636IDE-LZ10#PBF-ND
U803, U804, U805, U806: TLV9151IDCKR; SOT-353_SC-70-5
U807: TMUX6136; TSSOP-16_4.4x5mm_P0.65mm

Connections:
+5VA: C813.2, C814.2, C815.2, C816.2, C826.2, C827.2, FB801.1, U803.5 (V+), U804.5 (V+), U807.13 (Vdd); also elsewhere on the board
+15V: C821.2, C822.2, C823.2, C824.2, U805.5 (V+), U806.5 (V+); also elsewhere on the board
-5VA: C809.2, C810.2, C811.2, C812.2, C825.2, U803.2 (V-), U804.2 (V-), U807.5 (Vss); also elsewhere on the board
/AMP_Vc_EN: R822.1, U807.1 (SEL1), U807.9 (SEL2); also elsewhere on the board
/BIAS_DAC_SCK: U801.7 (SCK); also elsewhere on the board
/BIAS_DAC_SDI: U801.8 (SDI); also elsewhere on the board
/BIAS_DAC_~CS: U801.6 (~CS/LD); also elsewhere on the board
/DOUBLER_FILT_VT: R819.1; also elsewhere on the board
/FUND_FILT_VT: R818.1; also elsewhere on the board
/STG1_Vc: U807.3 (D1); also elsewhere on the board
/STG2_Vc: U807.11 (D2); also elsewhere on the board
/Vio_AUX: C804.2, R801.2
/rf_bias/DAC_REF_2P5V: R802.2, R804.2, R806.2, R808.2, U801.9 (REF)
/rf_bias/VOUTA: R803.2, R805.2, R807.2, U801.2 (VoutA)
/rf_bias/VOUTB: R809.2, U801.3 (VoutB)
/rf_bias/VOUTC: U801.4 (VoutC)
/rf_bias/VOUTD: U801.5 (VoutD)
GND: C801.1, C802.1, C803.1, C804.1, C809.1, C810.1, C811.1, C812.1, C813.1, C814.1, C815.1, C816.1, C821.1, C822.1, C823.1, C824.1, C825.1, C826.1, C827.1, R810.1, R811.1, R812.1, R813.1, R822.2, U801.14 (GND), U801.15 (EP), U805.2 (V-), U806.2 (V-), U807.6 (GND), U807.7 (NC), U807.8 (NC), U807.14 (NC), U807.15 (NC), U807.16 (NC); also elsewhere on the board
unnamed: C801.2, C802.2, C803.2, FB801.2, U801.1 (Vcc)
unnamed: C817.1, R802.1, R814.2, U803.3 (-)
unnamed: C817.2, R814.1, R820.2, U803.4
unnamed: C818.1, R804.1, R815.2, U804.3 (-)
unnamed: C818.2, R815.1, R821.2, U804.4
unnamed: C819.1, R806.1, R816.2, U805.3 (-)
unnamed: C819.2, R816.1, R818.2, U805.4
unnamed: C820.1, R808.1, R817.2, U806.3 (-)
unnamed: C820.2, R817.1, R819.2, U806.4
unnamed: R801.1, U801.13 (VoutH)
unnamed: R803.1, R810.2, U803.1 (+)
unnamed: R805.1, R811.2, U804.1 (+)
unnamed: R807.1, R812.2, U805.1 (+)
unnamed: R809.1, R813.2, U806.1 (+)
unnamed: R820.1, U807.4 (S1B)
unnamed: R821.1, U807.12 (S2B)
unnamed: TP801.1, U801.10 (VoutE)
unnamed: TP802.1, U801.11 (VoutF)
unnamed: TP803.1, U807.10 (S2A)
unnamed: TP804.1, U807.2 (S1A)

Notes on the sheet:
analog bias voltages: - 16-32 GHz filter - 7-16 GHz filter - output amp 1 - output amp 2
3.3V CMOS
TODO: CHECK OP AMP CIRCUIT VALUES
-0.9V to 1.1V
0-15V
2.7V to 5.5V supply
Replace op-ampps with TLV9152?
SELx A B 0 OFF ON 1 ON OFF
OUTPUT: 0V to 15V

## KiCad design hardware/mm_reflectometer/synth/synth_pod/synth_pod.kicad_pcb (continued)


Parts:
H2001, H2002, H2003, H2004, H2005, H2006, H2007, H2008, H2009, H2010, H2011, H2012, H2013, H2014, H2015, H2016, H2017, H2018, H2019, H2020, H2021, H2022, H2023, H2024, H2025, H2026, H2027, H2028, H2029, H2030: 2.5 mm; MountingHole_2.5mm_Pad_Via
J2003: Conn_Coaxial; SMA_Cinch_142-0711-821_EdgeMount
J2004: Conn_Coaxial; sw_edge_oshpark_4layer

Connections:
/REF_IN: J2003.1 (In); also elsewhere on the board
/panel/RF_OUTPUT: J2004.1 (In); also elsewhere on the board
GND: H2001.1, H2002.1, H2003.1, H2004.1, H2005.1, H2006.1, H2007.1, H2008.1, H2009.1, H2010.1, H2011.1, H2012.1, H2013.1, H2014.1, H2015.1, H2016.1, H2017.1, H2018.1, H2019.1, H2020.1, H2021.1, H2022.1, H2023.1, H2024.1, H2025.1, H2026.1, H2027.1, H2028.1, H2029.1, H2030.1, J2003.2 (Ext), J2004.2 (Ext); also elsewhere on the board

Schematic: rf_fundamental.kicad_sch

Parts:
AT401: ATS2012; mpn ATS2012-xxdB-XX
C401, C405, C406, C409, C412: 10 nF; C_0402_1005Metric
C402, C407, C408, C413: 100 pF; C_0402_1005Metric
C403, C410, C411: 1 uF; C_0402_1005Metric
C404: C_Small; C_0402_1005Metric
FB401, FB402, FB403, FB404: BLM15GG471SZ1D; L_0402_1005Metric
R401, R402: R_Small; R_0402_1005Metric
U401: MAAM-011101; TDFN6; mpn MAAM-011101-TR1000; digikey# 1465-1283-1-ND
U402: ADMV8416; LFCSP-40-1EP_6x6mm_P0.5mm_EP4.7x4.7mm; mpn ADMV8416ACPZ; mouser# 584-ADMV8416ACPZ

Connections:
+3.3VA: FB401.1; also elsewhere on the board
+5VA: FB403.1; also elsewhere on the board
-5VA: FB404.1; also elsewhere on the board
/FUND_FILT_VCTL: R401.1
/FUND_FILT_VT: R402.1; also elsewhere on the board
/fundamental_b/FUND_B_IN: AT401.1; also elsewhere on the board
/fundamental_b/FUND_B_OUT: U402.26 (RFOUT); also elsewhere on the board
GND: AT401.3, C401.1, C402.1, C403.1, C405.1, C406.1, C407.1, C408.1, C409.1, C410.1, C411.1, C412.1, C413.1, U401.2 (NC), U401.4 (NC), U401.5 (NC), U401.6 (NC), U401.7 (EP), U402.1 (NC), U402.2 (NC), U402.3 (NC), U402.4 (GND), U402.6 (GND), U402.7 (NC), U402.8 (NC), U402.9 (NC), U402.10 (NC), U402.12 (GND), U402.14 (NC), U402.16 (GND), U402.17 (NC), U402.18 (GND), U402.20 (NC), U402.21 (NC), U402.22 (NC), U402.23 (NC), U402.24 (NC), U402.25 (GND), U402.27 (GND), U402.28 (NC), U402.29 (NC), U402.30 (NC), U402.31 (NC), U402.32 (NC), U402.33 (NC), U402.34 (NC), U402.35 (NC), U402.36 (NC), U402.37 (NC), U402.38 (NC), U402.39 (NC), U402.40 (NC), U402.41 (GND); also elsewhere on the board
unnamed: AT401.2, U401.3 (RFin)
unnamed: C401.2, R401.2, U402.15 (VCTL)
unnamed: C402.2, C405.2, R402.2, U402.19 (VTUNE)
unnamed: C403.2, C406.2, C408.2, FB401.2, FB402.1
unnamed: C404.1, FB402.2, U401.1 (RFout)
unnamed: C404.2, U402.5 (RFIN)
unnamed: C407.2, C409.2, C410.2, FB404.2, U402.11 (VEE)
unnamed: C411.2, C412.2, C413.2, FB403.2, U402.13 (VDD)

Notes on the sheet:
ADMV8416
0-15V ANALOG
3.3V CMOS
6.3-18 GHz

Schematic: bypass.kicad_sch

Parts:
C1001, C1002: 10 nF; C_0402_1005Metric
J1001, J1002: Conn_Coaxial; SF2921-61345
R1001, R1002: 50; R_0402_1005Metric

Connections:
/bypass/BYPASS_IN: C1002.2, R1002.1; also elsewhere on the board
/bypass/BYPASS_OUT: C1001.2, R1001.1; also elsewhere on the board
GND: J1001.2 (Ext), J1002.2 (Ext), R1001.2, R1002.2; also elsewhere on the board
unnamed: C1001.1, J1002.1 (In)
unnamed: C1002.1, J1001.1 (In)

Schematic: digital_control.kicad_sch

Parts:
J1401: SYZYGY-STD; SYZYGY_standard_pod

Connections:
+5VP: J1401.2 (+5V)
/AMP_Vc_EN: J1401.12 (S7_D3N); also elsewhere on the board
/ATT_CLK: J1401.28 (S23); also elsewhere on the board
/ATT_LE: J1401.26 (S21); also elsewhere on the board
/ATT_SERIN: J1401.30 (S25); also elsewhere on the board
/ATT_SEROUT: J1401.32 (S27); also elsewhere on the board
/BIAS_DAC_SCK: J1401.7 (S2_D0N); also elsewhere on the board
/BIAS_DAC_SDI: J1401.5 (S0_D0P); also elsewhere on the board
/BIAS_DAC_~CS: J1401.9 (S4_D2P); also elsewhere on the board
/CLK_N: J1401.36 (C2P_CLKN)
/CLK_P: J1401.34 (C2P_CLKP)
/OUT_SW_EN: J1401.20 (S15_D7N); also elsewhere on the board
/OUT_SW_V1: J1401.22 (S17); also elsewhere on the board
/OUT_SW_V2: J1401.24 (S19); also elsewhere on the board
/PLL_CE: J1401.11 (S6_D2N); also elsewhere on the board
/PLL_LD: J1401.19 (S14_D6N); also elsewhere on the board
/PLL_MUTE: J1401.18 (S13_D7P); also elsewhere on the board
/PLL_MUX: J1401.21 (S16); also elsewhere on the board
/PLL_SCK: J1401.13 (S8_D4P); also elsewhere on the board
/PLL_SDI: J1401.15 (S10_D4N); also elsewhere on the board
/PLL_SYNC: J1401.16 (S11_D5N); also elsewhere on the board
/PLL_~CS: J1401.17 (S12_D6P); also elsewhere on the board
/REFSW_SD2: J1401.14 (S9_D5P); also elsewhere on the board
/REF_EN: J1401.6 (S1_D1P); also elsewhere on the board
/REF_SEL: J1401.8 (S3_D1N); also elsewhere on the board
/RELAY_EN: J1401.10 (S5_D3P); also elsewhere on the board
/TLM_ADC_DIN: J1401.25 (S20); also elsewhere on the board
/TLM_ADC_DOUT: J1401.27 (S22); also elsewhere on the board
/TLM_ADC_SCLK: J1401.23 (S18); also elsewhere on the board
/TLM_ADC_~CS: J1401.29 (S24); also elsewhere on the board
/ctrl_power/~FPGA_RESET: J1401.31 (S26); also elsewhere on the board
/digital_control/R_GA: J1401.4 (R_GA); also elsewhere on the board
/digital_control/SCL: J1401.1 (SCL); also elsewhere on the board
/digital_control/SDA: J1401.3 (SDA); also elsewhere on the board
GND: J1401.41 (GND); also elsewhere on the board

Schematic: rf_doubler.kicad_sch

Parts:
AT501: ATS2012; mpn ATS2012-xxdB-XX
C501, C508, C515, C516: 1 uF; C_0402_1005Metric
C502, C504, C506, C510, C512, C514, C517: 10 nF; C_0402_1005Metric
C503, C507: 100 nF; C_0402_1005Metric
C505, C509, C511, C513, C518: 100 pF; C_0402_1005Metric
FB501, FB502, FB503, FB504: BLM15GG471SZ1D; L_0402_1005Metric
R501: 640; R_0402_1005Metric
R502: 4.7k; R_0402_1005Metric
R503, R504: R_Small; R_0402_1005Metric
U501: MAAM-011101; TDFN6; mpn MAAM-011101-TR1000; digikey# 1465-1283-1-ND
U502: XX1000-QT; QFN-16-1EP_3x3mm_P0.5mm_EP1.45x1.45mm; mpn XX1000-QT-0G0T
U503: ADMV8432; LFCSP-40-1EP_6x6mm_P0.5mm_EP4.7x4.7mm; mpn ADMV8432ACPZ; mouser# 584-ADMV8432ACPZ

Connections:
+3.3VA: FB501.1; also elsewhere on the board
+5VA: FB503.1; also elsewhere on the board
-5VA: C507.1, C509.1, FB504.1, R502.1, U502.6 (Vss); also elsewhere on the board
/DOUBLER_FILT_VCTL: R503.1
/DOUBLER_FILT_VT: R504.1; also elsewhere on the board
/highband/HIGHBAND_IN: AT501.1; also elsewhere on the board
/highband/HIGHBAND_OUT: U503.26 (RFOUT); also elsewhere on the board
/highband/Vg2: U502.7 (Vg2); also elsewhere on the board
/highband/active_bias/Vd: U502.13 (Vd2); also elsewhere on the board
/highband/active_bias/Vp: C506.2, C508.2, U502.15 (Vd1); also elsewhere on the board
GND: AT501.3, C501.1, C502.1, C503.2, C505.2, C506.1, C507.2, C508.1, C509.2, C510.1, C511.1, C512.1, C513.1, C514.1, C515.1, C516.1, C517.1, C518.1, R501.2, U501.2 (NC), U501.4 (NC), U501.5 (NC), U501.6 (NC), U501.7 (EP), U502.1 (NC), U502.2 (GND), U502.4 (GND), U502.8 (NC), U502.9 (GND), U502.11 (GND), U502.12 (NC), U502.14 (NC), U502.16 (NC), U502.17 (GND), U503.1 (NC), U503.2 (NC), U503.3 (NC), U503.4 (GND), U503.6 (GND), U503.7 (NC), U503.8 (NC), U503.9 (NC), U503.10 (NC), U503.12 (GND), U503.14 (NC), U503.16 (GND), U503.17 (NC), U503.18 (GND), U503.20 (NC), U503.21 (NC), U503.22 (NC), U503.23 (NC), U503.24 (NC), U503.25 (GND), U503.27 (GND), U503.28 (NC), U503.29 (NC), U503.30 (NC), U503.31 (NC), U503.32 (NC), U503.33 (NC), U503.34 (NC), U503.35 (NC), U503.36 (NC), U503.37 (NC), U503.38 (NC), U503.39 (NC), U503.40 (NC), U503.41 (GND); also elsewhere on the board
unnamed: AT501.2, U501.3 (RFin)
unnamed: C501.2, C502.2, FB501.2, FB502.1
unnamed: C503.1, C505.1, R501.1, R502.2, U502.5 (Vg1)
unnamed: C504.1, FB502.2, U501.1 (RFout)
unnamed: C504.2, U502.3 (RFin)
unnamed: C510.2, R503.2, U503.15 (VCTL)
unnamed: C511.2, C512.2, R504.2, U503.19 (VTUNE)
unnamed: C513.2, C514.2, C515.2, FB504.2, U503.11 (VEE)
unnamed: C516.2, C517.2, C518.2, FB503.2, U503.13 (VDD)
unnamed: U502.10 (RFout), U503.5 (RFIN)

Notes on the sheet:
TODO: VERIFY FOOTPRINT
3.3V CMOS
0-15V ANALOG
Sequence: GND, +5V, -5V, VCTL

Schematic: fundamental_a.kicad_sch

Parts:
C901, C904, C905: 10 nF; C_0402_1005Metric
C902, C903: 1 uF; C_0402_1005Metric
FB901, FB902: BLM15GG471SZ1D; L_0402_1005Metric
FL901: LFCN-6700; Filter_Mini-Circuits_FV1206
R901: 1.9k; R_0402_1005Metric
U901: MAAM-011206; TDFN6; mpn MAAM-011206-TR3000; mouser# 937-MAAM-011206T3

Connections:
+3.3VA: FB901.1; also elsewhere on the board
/fundamental_a/FUND_A_IN: U901.3 (RFin); also elsewhere on the board
/fundamental_a/FUND_A_OUT: FL901.3 (OUT); also elsewhere on the board
GND: C901.1, C902.1, C903.1, C905.1, FL901.2 (GND), FL901.4 (GND), U901.2 (NC), U901.4 (NC), U901.5 (NC), U901.7 (EP); also elsewhere on the board
unnamed: C901.2, C902.2, R901.1, U901.6 (Vb)
unnamed: C903.2, C905.2, FB901.2, FB902.1, R901.2
unnamed: C904.1, FB902.2, U901.1 (RFout)
unnamed: C904.2, FL901.1 (IN)

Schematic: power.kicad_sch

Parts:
C601, C603, C604, C606, C609, C611, C616, C617, C618, C622, C623, C636, C637, C639, C640: 10 uF; C_0603_1608Metric
C602, C633, C634: 1 nF; C_0402_1005Metric
C605, C626, C628, C644, C645, C646: DNI; C_0402_1005Metric
C607, C608, C614, C615, C621, C625, C627, C632: 100 nF; C_0402_1005Metric
C610, C612, C619, C620, C642, C643: 1 uF; C_0402_1005Metric
C613: 4.7 uF; C_0603_1608Metric
C624, C629, C641: 2.2 uF; C_0603_1608Metric
C630: 10 uF; C_0805_2012Metric
C635: 220 nF; C_0603_1608Metric
C638: 100 nF; C_0603_1608Metric
C647, C648: 47 uF; CP_EIA-3528-15_AVX-H
FB601, FB605, FB606: BLM18EG101TN1D; L_0603_1608Metric
FB602: BLM18BB471SN1D; L_0603_1608Metric
FB603, FB604: BLM15AG102SZ1D; L_0402_1005Metric
L601: 15 uH; L_1210_3225Metric
R601, R602, R616, R617, R618, R619, R621, R622, R625, R626: R_Small; R_0402_1005Metric
R603, R604, R607: 10k; R_0402_1005Metric
R605, R615: 0; R_0402_1005Metric
R606, R608, R620, R627, R628: DNI; R_0402_1005Metric
R609, R611: 68k; R_0402_1005Metric
R610: 39k; R_0402_1005Metric
R612: 21k; R_0402_1005Metric
R613: TBD; R_0402_1005Metric
R614: 51k; R_0402_1005Metric
R623: 2.21M; R_0402_1005Metric
R624: 0; R_0603_1608Metric
U601: ADM7171ACPZ-5.0-R7; DFN-8-1EP_3x3mm_P0.5mm_EP1.66x2.38mm
U602: LM3880MF-1AF; SOT-23-6; MPN LM3880MFX-1AF/NOPB
U603: LM27761; WSON-8-1EP_2x2mm_P0.5mm_EP0.9x1.6mm
U604, U605: TPS72301DB; SOT-23-5
U606, U607: ADM7171ACPZ-R7; DFN-8-1EP_3x3mm_P0.5mm_EP1.66x2.38mm
U608: LT3494; DFN-8-1EP_2x3mm_P0.5mm_EP0.61x2.2mm

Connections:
+3.3VA: C640.1, C643.1, C648.1, FB606.2; also elsewhere on the board
+3.3VP: C639.1, C642.1, C647.1, FB605.2; also elsewhere on the board
+4V: C621.1, C622.1, C623.1, C625.1, C627.1, FB604.1, R603.1, R604.1, U606.7 (VIN), U606.8 (VIN), U607.7 (VIN), U607.8 (VIN); also elsewhere on the board
+5V5: C601.1, C606.1, U601.7 (VIN), U601.8 (VIN), U602.1 (VCC), U603.1 (VIN), U603.6 (EN); also elsewhere on the board
+5VA: C611.1, C612.1, FB601.2; also elsewhere on the board
+15V: C630.1, R624.2; also elsewhere on the board
-3V3: C619.1, FB602.2; also elsewhere on the board
-5V35: C603.1, C604.1, C607.1, C608.1, R615.2, U604.2 (IN), U605.2 (IN)
-5VA: C620.1, FB603.2; also elsewhere on the board
/ctrl_power/PGOOD_SWITCHING: U602.3 (EN); also elsewhere on the board
/rf_power/3.3V_PLL_EN: R601.1, R603.2, R616.1, R617.1, U602.6 (FLAG1)
/rf_power/15V_BIAS_EN: R607.2, R620.1, U602.4 (FLAG3), U608.5 (~SHDN); also elsewhere on the board
/rf_power/M3V3_EN: R604.2, U602.5 (FLAG2), U604.3 (EN), U605.3 (EN)
GND: C601.2, C602.2, C603.2, C604.2, C606.2, C607.2, C608.2, C609.2, C611.2, C612.2, C613.2, C614.2, C615.2, C616.2, C617.2, C618.2, C619.2, C620.2, C621.2, C622.2, C623.2, C624.2, C625.2, C627.2, C629.2, C630.2, C632.2, C633.2, C634.2, C635.2, C636.2, C637.2, C638.2, C639.2, C640.2, C641.2, C642.2, C643.2, C647.2, C648.2, R602.2, R606.1, R610.2, R612.2, R614.2, R618.2, R619.2, R620.2, R622.1, R626.1, U601.6 (GND), U601.9 (GND), U602.2 (GND), U603.2 (GND), U603.9 (PAD), U604.1 (GND), U605.1 (GND), U606.6 (GND), U606.9 (GND), U607.6 (GND), U607.9 (GND), U608.2 (GND), U608.9 (GND); also elsewhere on the board
unnamed: C602.1, U601.4 (SS)
unnamed: C605.1, C609.1, FB601.1, R605.2, U601.1 (VOUT), U601.2 (VOUT)
unnamed: C605.2, R608.2
unnamed: C610.1, U603.8 (C+)
unnamed: C610.2, U603.7 (C-)
unnamed: C613.1, U603.3 (CPOUT)
unnamed: C614.1, C617.1, C644.1, FB602.1, R609.1, U604.5 (OUT)
unnamed: C615.1, C618.1, C645.1, FB603.1, R611.1, U605.5 (OUT)
unnamed: C616.1, C646.1, R613.1, R615.1, U603.4 (VOUT)
unnamed: C624.1, C629.1, C632.1, FB604.2, L601.1, U608.3 (Vcc)
unnamed: C626.1, C636.1, FB605.1, R621.2, U606.1 (VOUT), U606.2 (VOUT)
unnamed: C626.2, R627.2
unnamed: C628.1, C637.1, FB606.1, R625.2, U607.1 (VOUT), U607.2 (VOUT)
unnamed: C628.2, R628.2
unnamed: C633.1, U606.4 (SS)
unnamed: C634.1, U607.4 (SS)
unnamed: C635.1, U608.8 (CAP)
unnamed: C638.1, C641.1, R623.1, R624.1, U608.7 (Vout)
unnamed: C644.2, R609.2, R610.1, U604.4 (FB)
unnamed: C645.2, R611.2, R612.1, U605.4 (FB)
unnamed: C646.2, R613.2, R614.1, U603.5 (VFB)
unnamed: L601.2, U608.1 (SW)
unnamed: R601.2, R602.1, U601.5 (EN)
unnamed: R605.1, R606.2, R608.1, U601.3 (SENSE)
unnamed: R616.2, R618.1, U606.5 (EN)
unnamed: R617.2, R619.1, U607.5 (EN)
unnamed: R621.1, R622.2, R627.1, U606.3 (SENSE)
unnamed: R623.2, U608.6 (FB)
unnamed: R625.1, R626.2, R628.1, U607.3 (SENSE)

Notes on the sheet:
CHANGE TO ADM7172ACPZ-R7
200 mA
50 mA
650 mA
CHECK RESISTOR VALUES
750 mA
100 mA
Sequence: 1) +5V, +3.3V 2) -5V, -3.3V 3) +15V, Digital

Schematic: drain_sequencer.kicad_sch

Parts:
D1101: MM5Z3V3T1G; D_SOD-523
Q1101: BC848W; SOT-323_SC-70
Q1102: IRLML6401; SOT-23
R1101, R1103, R1104: 10k; R_0402_1005Metric
R1102: 0; R_0402_1005Metric

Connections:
+5VA: Q1102.2 (S), R1104.2; also elsewhere on the board
-5VA: D1101.2 (A); also elsewhere on the board
/highband/active_bias/Vp: R1102.2; also elsewhere on the board
GND: R1101.2; also elsewhere on the board
unnamed: D1101.1 (K), Q1101.2 (E)
unnamed: Q1101.1 (B), R1101.1
unnamed: Q1101.3 (C), R1103.1
unnamed: Q1102.1 (G), R1103.2, R1104.1
unnamed: Q1102.3 (D), R1102.1

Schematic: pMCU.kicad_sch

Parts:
C1601: 100 nF; C_0402_1005Metric
C1602: 1 uF; C_0402_1005Metric
J1601: TC2050-IDC-NL; TAG-CONNECT_TC2050-IDC-NL; PARTREV A
R1601: 10k; R_0402_1005Metric
U1601: ATtiny24A-MM; QFN-20-1EP_3x3mm_P0.45mm_EP1.6x1.6mm

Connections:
/digital_control/R_GA: R1601.2, U1601.5 (AREF/PA0); also elsewhere on the board
/digital_control/SCL: J1601.7, U1601.1 (PA4); also elsewhere on the board
/digital_control/SDA: J1601.1, U1601.16 (PA6); also elsewhere on the board
/digital_control/pMCU/pMCU_MISO: J1601.9, U1601.20 (PA5)
/digital_control/pMCU/pMCU_~RST: J1601.5, U1601.13 (~RESET/PB3)
GND: C1601.2, C1602.2, J1601.4, J1601.6, J1601.8, J1601.10, U1601.8 (GND), U1601.21 (GND); also elsewhere on the board

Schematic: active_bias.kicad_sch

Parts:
C1201, C1202, C1207, C1208: 100 pF; C_0402_1005Metric
C1203, C1206, C1209, C1210: 100 nF; C_0402_1005Metric
C1204: 1 nH; C_0402_1005Metric
C1205: 4.7 uF; C_0603_1608Metric
D1201, D1202, D1203: BAS516; D_SOD-523
R1201: 15k; R_0402_1005Metric
R1202: DNI; R_0402_1005Metric
R1203: 0.5; R_0603_1608Metric
R1204: 0; R_0402_1005Metric
R1205, R1206, R1207, R1208: 1k; R_0402_1005Metric
R1209: 100k; R_0402_1005Metric
U1201: TLV9151IDCKR; SOT-353_SC-70-5
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

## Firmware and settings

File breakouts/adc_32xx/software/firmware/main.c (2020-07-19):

#include <stdio.h>
#include <stdlib.h>
#include <string.h>

#include <irq.h>
#include <uart.h>
#include <console.h>
#include <generated/csr.h>
#include <generated/mem.h>


static char *readstr(void)
{
	char c[2];
	static char s[64];
	static int ptr = 0;

	if(readchar_nonblock()) {
		c[0] = readchar();
		c[1] = 0;
		switch(c[0]) {
			case 0x7f:
			case 0x08:
				if(ptr > 0) {
					ptr--;
					putsnonl("\x08 \x08");
				}
				break;
			case 0x07:
				break;
			case '\r':
			case '\n':
				s[ptr] = 0x00;
				putsnonl("\n");
				ptr = 0;
				return s;
			default:
				if(ptr >= (sizeof(s) - 1))
					break;
				putsnonl(c);
				s[ptr] = c[0];
				ptr++;
				break;
		}
	}

	return NULL;
}

static char *get_token(char **str)
{
	char *c, *d;

	c = (char *)strchr(*str, ' ');
	if(c == NULL) {
		d = *str;
		*str = *str+strlen(*str);
		return d;
	}
	*c = 0;
	d = *str;
	*str = c+1;
	return d;
}

static void prompt(void)
{
	printf("RUNTIME>");
}

static void help(void)
{
	puts("Available commands:");
	puts("help                            - this command");
	puts("reboot                          - reboot CPU");
	puts("memory                          - memory test");
	puts("wishbone                        - wishbone dma test");
	puts("adc                        	  - adc test");
}

static void reboot(void)
{
  	ctrl_reset_write(1);
}

static uint32_t adc_spi_read(uint16_t addr)
{
	while(adc_spi_status_read() != 1 << CSR_ADC_SPI_STATUS_DONE_OFFSET) {
		;
	}

	uint32_t spi_control_start = (24 << CSR_ADC_SPI_CONTROL_LENGTH_OFFSET) | (1 << CSR_ADC_SPI_CONTROL_START_OFFSET);
	adc_spi_cs_write(0);
	adc_spi_mosi_write((addr << 8) + (1 << 23) + (1 << 22));
	adc_spi_control_write(spi_control_start);

	adc_spi_cs_write(1);
	while(adc_spi_status_read() != 1 << CSR_ADC_SPI_STATUS_DONE_OFFSET) {
		;
	}

	uint32_t r = adc_spi_miso_read();
	return r & 0xFF;

}


static void adc_spi_write(uint16_t addr, uint8_t value)
{
	while(adc_spi_status_read() != 1 << CSR_ADC_SPI_STATUS_DONE_OFFSET) {
		;
	}

	uint32_t spi_control_start = (24 << CSR_ADC_SPI_CONTROL_LENGTH_OFFSET) | (1 << CSR_ADC_SPI_CONTROL_START_OFFSET);
	adc_spi_cs_write(0);

	uint32_t payload = (1 << 22) + (addr << 8) + value;

	adc_spi_mosi_write(payload);
	adc_spi_control_write(spi_control_start);

	adc_spi_cs_write(1);

	uint8_t r = adc_spi_read(addr);

	if(r != value) {
		printf("adc readback after write to %x failed!, expected %x got %x\n", addr, value, r);
	}
}

static void adc_init(void)
{
	// setup for 2-Wire (6x serialization)
	// Fs = 25 MSPS, Fbit = 150 MHz
	
	// soft reset
	adc_spi_write(0x06, 0x01);
	adc_spi_write(0x06, 0x00);
	// high pulse on reset, minimum duration 10 nanoseconds
	// max SPI SCLK 20 MHz
	// 0x01, default ok, dithering on both channels
	// 0x03, default ok, bits 0,1,2 on wire 0, bits 7,8,9 on wire 1
	// 0x04, default ok, do not flip output wires
	// 0x05, default ok, transmit on two output wires
	// 0x06, default ok, normal output (not a test pattern)
	// 0x07, default ok, bit 0 is lsb
	adc_spi_write(0x09, 0x01); // 0x09, set data format as offset binary
	// 0x0a, default ok, normal operation (not a test pattern)
	// 0x0b, default ok, normal operation (not a test pattern)
	// 0x0e, default ok
	// 0x0f, default ok
	// 0x13, default ok, >25 MSPS
	// 0x15, default ok, enable both channels and normal operation
	// 0x25, default ok, max LVDS swing
	// 0x27, default ok, no sample clock division
	// 0x41D, default ok, <100 MHz operation
	// 0x422, default ok, chopper enabled on ch a
	// 0x434, default ok, dithering on cha
	adc_spi_write(0x439, 0x08);
	// 0x439, write 0b1000 after reset for best performance on ch a
	// 0x51D, default ok, <100 MHz operation
	// 0x522, default ok, chopper enabled on ch b
	// 0x534, default ok, dithering on channel a
	adc_spi_write(0x539, 0x08);
	// 0x539, write 0b1000 after reset for best performance on ch b
	// 0x608, default ok, <100 MHz operation

	adc_spi_write(0x70A, 0x01);
	// 0x70A, 0b1, disable sysref buffer
}


static void adc_testpattern_en(void)
{
	adc_spi_write(0x06, 0x02);
	adc_spi_write(0x0a, 0x04);
	adc_spi_write(0x0b, 0x09<<4);


	// custom pattern:
	adc_spi_write(0x0e, 0x16);
	adc_spi_write(0x0f, 0x50); // 0x05

	// 0a
	// 0 - normal
	// 1 - all 0
	// 2 - all 1
	// 3 - alternate 010101 101010 
	// 4 - ramp, datasheet is incorrect, value increments every 4 samples (https://e2e.ti.com/support/data-converters/f/73/t/469423)
	// 5 - custom pattern
	// 9 - 8 point sine wave, [0, 599,2048,3496,4095,3496,2048,599]
	// 10 - Deskew pattern, data are AAAh
}

static void adc_testpattern_disable(void)
{
	adc_spi_write(0x06, 0x00);
	adc_spi_write(0x0a, 0x00);
	adc_spi_write(0x0b, 0x00);
}

static void adc_test(void)
{
	// capture a burst, 20 MSPS, a
	// provide a 20 MHz sample clock
	// read in data at .. 120 MHz
	//
	uint16_t burst_size = 1024;
	volatile uint32_t *dram_array = (uint32_t *)(HYPERRAM_BASE);
	adc_init();
	adc_testpattern_disable();

	adc_burst_size_write(burst_size);
	adc_base_write(HYPERRAM_BASE);
	adc_offset_write(0);

	adc_start_write(1 << CSR_ADC_START_START_BURST_OFFSET);

	printf("waiting for ready!\n");

	// flush cache before accessing shared memory..
	flush_cpu_icache();
	flush_cpu_dcache();

	while(!adc_ready_read())
	{
		;
	}

	printf("memory readback!\n");
	for(uint16_t i=0; i<burst_size; i++) {
		printf("memory[%d]: %d\n", i, dram_array[i]);
	}

}


static void memory_test(void)
{
	// offset data in RAM from the start to avoid overwriting firmware..
	volatile uint32_t *dram_array = (unsigned int *)(HYPERRAM_BASE);

	int i;
	printf("memory test...\n");
	/*
	printf("writing memory to base %x!\n", dram_array);
	printf("HYPERRAM_BASE is %x!\n", HYPERRAM_BASE);
	for(i=0; i<500000; i++) {
		//#printf("writing memory, %d!\n", i);
		dram_array[i] = 0;
	}
	*/
	printf("memory readback!\n");
	for(i=0; i<1024; i++) {
		// 	printf("reading memory[%d] = %d\n", i, dram_array[i]);
		if(dram_array[i] == 0) {
			;
		}
		else {
			printf("pattern mismatch!, read %d expected %d\n", dram_array[i], i*4);
		}

	}
	printf("test complete!\n");
	
}

static void console_service(void)
{
	char *str;
	char *token;

	str = readstr();
	if(str == NULL) return;
	token = get_token(&str);
	if(strcmp(token, "help") == 0)
		help();
	else if(strcmp(token, "reboot") == 0)
		reboot();
	else if(strcmp(token, "memory") == 0)
		memory_test();
	else if(strcmp(token, "adc") == 0)
		adc_test();
	prompt();
}

int main(void)
{
	irq_setmask(0);
	irq_setie(1);
	uart_init();

	puts("\nCPU testing software built "__DATE__" "__TIME__"\n");
	help();
	prompt();

	while(1) {
		console_service();
	}

	return 0;
}

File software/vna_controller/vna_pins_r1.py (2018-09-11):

# pins on vna r1 control board

class PINS(object):
    ### PRU
    # AD_DOUTD, pr1_pru1_pru_r31_0 
    # AD_DOUTC, pr1_pru1_pru_r31_1 
    # AD_DOUTB, pr1_pru1_pru_r31_2 
    # AD_DOUTA, pr1_pru1_pru_r31_3
    # AD_FS, pr1_pru1_pru_r31_4 
    # AD_CLKOUT, pr1_pru1_pru_r31_5 
    EXT_TRIG = (2,12) # pr1_pru1_pru_r31_6
    PORT_SEL_PRU = (2,13) # pr1_pru1_pru_r30_7
    PORT_SEL_GPIO = (2,4)
    TP1307 = (2,23)
    TP1308 = (2,25)
    EEPROM_WP = (2,5)
    
    ### EXT
    EXT_UART_MTX = (0,15)
    EXT_UART_MRX = (1,10)
    EXT_AIN0 = 'AIN5'
    EXT_AIN1 = 'AIN6'
    # EXT_SPI_CLK, SPI0_SCLK
    # EXT_SPI_MISO, SPI0_D0
    # EXT_SPI_MOSI, SPI0_D1
    # EXT_SPI_CS0, SPI0_CS0
    EXT_SPI_CS1 = (2,1)
    EXT_IO_0 = (1,29)
    EXT_IO_1 = (1,30)
    EXT_IO_2 = (1,31)
    EXT_IO_3 = (2,0)

    ### RF
    RF_3V3_EN = (1,8)
    MIX_X2 = (1,9)
    PLL_3V3_EN = (0,12)
    RF_AMP_EN = (0,13)
    RF_SYNTH_CS = (3,15)
    LO_SYNTH_CS = (3,16)
    RF_DAC_CS = (3,17)
    LO_SPI_CLK_BYPASSED = (3,18)
    LO_SPI_SDI = (3,19)
    RF_SPI_CLK = (3,20)
    RF_SPI_SDI = (3,21)

    LO_AMP_EN = (0,19)
    RF_M5V_EN = (0,20)
    EXT_DEMOD_3V3_EN = (0,7)
    ADC_CLK_EN = (1,16)
    MIX_EN = (1,17)
    LO_BUF_AMP_EN = (1,27)
    LO_3V3_EN = (1,28)
    LO_PORT_SEL = (0,30)
    LO_DAC_CS = (0,31)
    
    LO_M5V_EN = (1,0)
    PLL_REF_SEL = (1,1)
    RF_FILT_SW_1 = (1,2)
    LO_SPI_CLK = (1,3)
    RF_SYNTH_CE = (1,4)
    RF_SYNTH_LOCK = (1,5)
    LO_SYNTH_LOCK = (1,6)
    LO_SYNTH_CE = (1,7)

    AD_SYNCB = (0,22)
    AD_PE_D = (0,23)
    AD_PE_C = (0,26)
    AD_PE_B = (0,27)
    AD_PE_A = (1,12)

    AD_PC = (1,13)
    AD_PD = (1,14)
    AD_DOUTB = (1,15)

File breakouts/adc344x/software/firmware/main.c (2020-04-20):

#include <stdio.h>
#include <stdlib.h>
#include <string.h>

#include <irq.h>
#include <uart.h>
#include <console.h>
#include <generated/csr.h>
#include <generated/mem.h>


// build started from from litex fpga101 lab 4
// also see https://github.com/enjoy-digital/versa_ecp5

static void busy_wait(unsigned int ds)
{
	timer0_en_write(0);
	timer0_reload_write(0);
	timer0_load_write(CONFIG_CLOCK_FREQUENCY/10*ds);
	timer0_en_write(1);
	timer0_update_value_write(1);
	while(timer0_value_read()) timer0_update_value_write(1);
}


static char *readstr(void)
{
	char c[2];
	static char s[64];
	static int ptr = 0;

	if(readchar_nonblock()) {
		c[0] = readchar();
		c[1] = 0;
		switch(c[0]) {
			case 0x7f:
			case 0x08:
				if(ptr > 0) {
					ptr--;
					putsnonl("\x08 \x08");
				}
				break;
			case 0x07:
				break;
			case '\r':
			case '\n':
				s[ptr] = 0x00;
				putsnonl("\n");
				ptr = 0;
				return s;
			default:
				if(ptr >= (sizeof(s) - 1))
					break;
				putsnonl(c);
				s[ptr] = c[0];
				ptr++;
				break;
		}
	}

	return NULL;
}

static char *get_token(char **str)
{
	char *c, *d;

	c = (char *)strchr(*str, ' ');
	if(c == NULL) {
		d = *str;
		*str = *str+strlen(*str);
		return d;
	}
	*c = 0;
	d = *str;
	*str = c+1;
	return d;
}

static void prompt(void)
{
	printf("RUNTIME>");
}

static void help(void)
{
	puts("Available commands:");
	puts("help                            - this command");
	puts("reboot                          - reboot CPU");
	puts("memory                          - memory test");
	puts("coremem                         - memory core test");
	puts("dac                             - dac core test");
	puts("adc                             - adc core test");
	puts("spi                             - spi test");
	puts("led                             - led test");
}

static void reboot(void)
{
//asm("call r0");
}

static void adc_test(void)
{
	static unsigned int test_offset_bytes = 1048576 + 1024 * 1024;
	volatile unsigned int *dram_array = (unsigned int *)(MAIN_RAM_BASE + test_offset_bytes);
	uint32_t j;
	
	while(1) {
		// set _base
		adc_test_base_write(test_offset_bytes);
		memory_test_offset_write(0);

		printf("starting adc test burst, waiting for ready\n");
		// wait for ready, then start adc
		while(!adc_test_ready_read()) {
			busy_wait(1);
		}

		printf("start pulse written, waiting for ready\n");
		adc_test_start_write(1);
		
		// wait for ready, then start adc
		while(!adc_test_ready_read()) {
			busy_wait(1);
		}
		printf("burst complete, reading back samples\n");

		for(j=0; j<1024; j+= 1) {
			printf("memory[%d] = %u\n", j, dram_array[j*4+3]);
		}

		printf("finished reading memory\n");

		busy_wait(50);
	}

	/*
	// set memory[address] = value
	printf("memory value is %u!\n", dram_array[0]);
	printf("writing 0 to memory\n");
	memory_test_addr_write(test_offset / 128);
	memory_test_start_write(1);
	busy_wait(1);
	printf("waiting..\n");
	printf("memory value is %u!\n", dram_array[0]);
	printf("writing 1 to memory\n");
	memory_test_addr_write(test_offset / 128);
	memory_test_start_write(1);
	busy_wait(1);
	printf("waiting..\n");
	printf("memory value is %u!\n", dram_array[0]);
	*/
}

static void core_memory_test(void)
{
	static unsigned int test_offset_bytes = 1048576;
	volatile unsigned int *dram_array = (unsigned int *)(MAIN_RAM_BASE + test_offset_bytes);
	uint32_t i, j;

	// set _base
	memory_test_base_write(test_offset_bytes);
	printf("sizeof unsigned int: %d\n", sizeof(unsigned int));	
	for(i=0; i<500000; i++) {
		memory_test_offset_write(i);
		memory_test_value_write(i);
		if(i % 10000 == 0) {
			printf("writing memory[%d] = %u\n", i, i);
		}
		memory_test_start_write(1);
		while(!memory_test_ready_read()) {
			;
		}
	}

	printf("finished writing memory\n");
	for(j=0; j<1000000; j+= 20000) {
		for(i=0; i<20; i++) {
			printf("memory[%d] = %u\n", i + j, dram_array[i+j]);
		}
	}

	printf("finished reading memory\n");

	/*
	// set memory[address] = value
	printf("memory value is %u!\n", dram_array[0]);
	printf("writing 0 to memory\n");
	memory_test_addr_write(test_offset / 128);
	memory_test_start_write(1);
	busy_wait(1);
	printf("waiting..\n");
	printf("memory value is %u!\n", dram_array[0]);
	printf("writing 1 to memory\n");
	memory_test_addr_write(test_offset / 128);
	memory_test_start_write(1);
	busy_wait(1);
	printf("waiting..\n");
	printf("memory value is %u!\n", dram_array[0]);
	*/
}

static void memory_test(void)
{
	// offset data in RAM from the start to avoid overwriting firmware..
	volatile unsigned int *dram_array = (unsigned int *)(MAIN_RAM_BASE + 1024 * 1024 * 2);

	int i;
	printf("memory test...\n");

	printf("writing memory to base %d!\n", &dram_array);

	for(i=0; i<100; i++) {
		printf("writing memory, %d!\n", i);
		dram_array[i] = i*4;
	}

	printf("memory readback!\n");
	for(i=0; i<100; i++) {
		printf("reading memory, %d!\n", i);
		if(dram_array[i] == i*4) {
		}
		else {
			printf("pattern mismatch!\n");
		}

	}
	printf("test complete!\n");
}

static void dac_test(void)
{
	uint16_t i,j;
	dac_test_output_en_write(0xff);
	printf("starting dac sweep!\n");
	for(j=0;j<32;j++) {
	for(i=0;i<4096;i++) {
		printf("step %d!\n", i);
		dac_test_value_a_write(i);
		dac_test_value_b_write(j);
		dac_test_load_write(1);
		busy_wait(1);
	}
	printf("sweep %d!\n", j);
	}
	printf("dac sweep complete!\n");

}

static void spi_test(void)
{
	int i;
	unsigned int spi_control_start = (8 << CSR_SPI_TEST_CONTROL_LENGTH_OFFSET) | (1 << CSR_SPI_TEST_CONTROL_START_OFFSET);
	spi_test_cs_write(1);

	printf("spi_test...\n");

	// send byte
	for(i=0; i<32; i++) {
		spi_test_mosi_write(i);
		spi_test_control_write(spi_control_start);
	}
	printf("spi test complete!");
}


static void led_test(void)
{
	int i;
	printf("led_test...\n");
	for(i=0; i<32; i++) {
		gpio_leds_out_write(i);
		busy_wait(1);
	}
}

static void console_service(void)
{
	char *str;
	char *token;

	str = readstr();
	if(str == NULL) return;
	token = get_token(&str);
	if(strcmp(token, "help") == 0)
		help();
	else if(strcmp(token, "reboot") == 0)
		reboot();
	else if(strcmp(token, "memory") == 0)
		memory_test();
	else if(strcmp(token, "coremem") == 0)
		core_memory_test();
	else if(strcmp(token, "dac") == 0)
		dac_test();
	else if(strcmp(token, "adc") == 0)
		adc_test();
	else if(strcmp(token, "led") == 0)
		led_test();
	else if(strcmp(token, "spi") == 0)
		spi_test();
	prompt();
}

int main(void)
{
	irq_setmask(0);
	irq_setie(1);
	uart_init();

	puts("\nCPU testing software built "__DATE__" "__TIME__"\n");
	help();
	prompt();

	while(1) {
		console_service();
	}

	return 0;
}

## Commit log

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2016-03-07 added leds to pcm2900, demod, and synth boards. started layout on ti boosterpack control hat
    [boosterpack.kicad_pcb, boosterpack.sch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]
2016-03-07 added missing libs, finished layout of boosterpack board
    [boosterpack.kicad_pcb]
2016-03-09 ready to order demod, pcm breakout, booster, and synth
    [adf4355-3-B.Cu.gbl, adf4355-3-B.Mask.gbs, adf4355-3-B.SilkS.gbo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]
2016-03-12 started variable attenuator, revised synth, and added power splittert to detect board
    [adf4355-3-B.Cu.gbl, adf4355-3-B.Mask.gbs, adf4355-3-B.SilkS.gbo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]
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2016-03-15 .. added missing attenuator folder
    [attenuator-B.Cu.gbl, attenuator-B.Mask.gbs, attenuator-B.SilkS.gbo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]
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2016-04-22 trimmed ground plane on some breakouts so it doesn't disappear during panelization..
    [amp_breakout.sch, filter_bank.kicad_pcb, filter_bank.sch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]
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2016-04-22 changed sma connectors on amp board to edge launch, trimmed excess ground plane
    [amp_breakout.kicad_pcb, amp_breakout.sch, attenuator.kicad_pcb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]
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2016-04-23 added lmk61e2 oscillator footprint/symbol
2016-04-24 added board for macom 2 GHZ to 14 GHz amplifier
    [amp_macom-B.Cu.gbl, amp_macom-B.Mask.gbs, amp_macom-B.SilkS.gbo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]
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2016-04-26 added missing schematic symbols, cleaned up stepped impedance filter calc a little
2016-04-27 added missing TRL/SLOT cal boards
    [cal_SLOT.kicad_pcb, cal_SLOT.sch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]
2016-05-01 kicad poly shape generation of stepped impedance filters working
    [amp_macom-B.Cu.gbl, amp_macom-B.Mask.gbs, amp_macom-B.SilkS.gbo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]
2016-05-01 added microstrip filter simulation, filter calculator appears to not very well..
    [filter_test.sch]
2016-05-05 started on frequency synth module, added edge launch sma footprint sim
    [amplifier.sch, attenuator.sch, connectors_mcu.sch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]
2016-05-05 added missing clock synth breakout
    [refclk_breakout-B.Cu.gbl, refclk_breakout-B.Mask.gbs, refclk_breakout-B.SilkS.gbo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]
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2016-05-06 reducing component values across module, synth schematic cleanups
    [amplifier.sch, attenuator.sch, connectors_mcu.sch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]
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2016-05-06 synth - initial component placement layout on everybody but lmx2592
    [amplifier.sch, attenuator.sch, connectors_mcu.sch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]
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2016-05-10 added sma edge launch cutout SLOT cal board
    [amplifier.sch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]
2016-05-13 work on synth layout - removed filter bank inverters
    [connectors_mcu.sch, filter_bank.sch, frequency_synth.kicad_pcb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]
2016-05-14 work on layout of synth, done up to output stage of lmx2592
    [amplifier.sch, attenuator.sch, connectors_mcu.sch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]
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2016-05-20 added no-connect symbols to synth schematic, ordered r0 board
    [connectors_mcu.sch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]
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2016-05-23 added dual channel adc board, added kicad gitignore
    [adc_dual.kicad_pcb, adc_dual.sch]
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2016-05-24 layout of sections of the dual adc board
    [adc_dual.kicad_pcb, adc_dual.sch]
2016-05-24 adc layout complete (except for analog input traces..)
    [adc_dual.kicad_pcb, adc_dual.sch]
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2016-06-09 added missing refclk schematic to synth, about to start assembly
    [refclk.sch]
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2016-06-10 started errata for r0 synth board..
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2016-06-12 fixed bug in filter bank selection software
    [synth_test.ino]
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2016-06-13 fixed bugs in filter and attenuator selection on synth
    [synth_test.ino]
2016-06-14 fixed resistor values in unequal power divider for power detector
    [powerdetect.sch]
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2016-06-15 fixed values on lmx2592 output, started bias network breakout
    [bias_module.kicad_pcb, bias_module.sch, synth.sch]
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2016-06-27 finished bias module, modified mixer, splitter, and switch sma connector footprints
    [bias_module.kicad_pcb, bias_module.sch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]
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2016-07-06 added coplanar waveguide test boards, crystal filter breakout
    [cpw_test-B.Cu.gbr, cpw_test-B.Mask.gbr, cpw_test-B.SilkS.gbr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]
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2016-08-29 started on synth r1 (fixed r0 bugs..), component placement on ad9864 breakout
    [ad9864_breakout.kicad_pcb, attenuator.sch, connectors_mcu.sch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]
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2016-09-08 added frequency calibrated power detection, tested returning values over ethernet
    [ad5902_cal.ods]
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2016-09-14 fixed bugs in sweep software, swept measurements work
    [vna_driver.py]
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2016-09-18 finished layout of r1 synth board (switched to cpw sma, added test points, fixed r0 errata, removed power detector and amp (make separate board))
    [attenuator.sch, connectors_mcu.sch, filter_bank.sch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]
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2016-09-19 ordered r1 synth board, ordered coplanar waveguide mixer breakout
    [frequency_synth-B.Cu.gbl, frequency_synth-B.Mask.gbs, frequency_synth-B.SilkS.gbo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]
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2016-09-25 fixed bugs in pru/beaglebone communication test code.. working now?
    [adc_shm.h, adc_to_socket.c]
2016-09-28 added values to ad9864 lo pll, added missing pullup resistors, work on ad9864 test sketch
    [ad9864_breakout.kicad_pcb, ad9864_breakout.sch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]
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2016-10-01 work on controller board, added footprints for microsd, lan controller, sn74lvc1g07
    [controller.sch, ethernet_usb_sd.sch, io_headers.sch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]
2016-10-02 calculated ad9864 register values for 45 MHz IF, 26 MHz fclk
    [controller.sch, ethernet_usb_sd.sch, io_headers.sch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]
2016-10-03 fixed bugs in spi write to ad9864
2016-10-03 actually applied bugfix for ad9864 spi..
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2016-10-12 modified mixer breakout to work with ltc5548, moved to soldermask defined pads
    [ad9864_breakout.sch, attenuator.sch, connectors_mcu.sch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]
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2016-10-12 switched switch board to be coplanar waveguide fed
    [switch_breakout.kicad_pcb, switch_breakout.sch]
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2016-10-21 work on controller board - ethernet and microsd schematic
    [ethernet_usb_sd.sch]
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2016-10-25 finished and ordered clk/lo buffer for demod board
    [clk_lo_buffer.kicad_pcb, clk_lo_buffer.sch]
2016-10-26 started on control cape for 4 receiver vna
    [adc_cape.kicad_pcb, adc_cape.sch]
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2016-10-27 moved adc cape traces to avoid routing digital io into analog inputs.. cleaned up silkscreen and ordered board
    [adc_cape.kicad_pcb, adc_cape.sch]
2016-10-28 started working on vna control software for non-zero IF and separate RF/LO synths
    [adc_cape.kicad_pcb, synth_r1_power_meas.ods]
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2016-10-29 fixed bugs in beaglebone ad9864 init script..
    [adc_bbone_init.py]
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2016-10-31 work on adc PRU reader, fixed shared memory indexing
    [adc_bbone_init.py]
2016-10-31 improved frequency drift correction
    [adc_client.py, vna_driver.py]
2016-11-01 auto restart adc server on crash, improved sample time correction?
    [adc_client.py, vna_driver.py]
2016-11-02 corrected s11 phase measurements (calculate circular mean correctly..)
    [vna_driver.py]
2016-11-06 fixed footprints for filters on synth board
    [attenuator.sch, connectors_mcu.sch, filter_bank.sch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]
2016-11-08 started on cost-reduced version of synth (reduced BOM by ~)
    [amp.sch, attenuator.sch, connectors_mcu.sch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]
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2016-11-14 fixed some schematic values in demod module, adc works
    [demod_module.sch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]
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2016-11-20 added missing bit-banged SPI driver..
    [bbone_spi_bitbang.py]
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2016-11-22 fixed bug in fractional synth, pin definitions for synth b.
    [bbone_spi_bitbang.py, synth_bbone.py]
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2016-11-29 fixed some syntax errors on beaglebone zmq io servers
    [zmq_io_server.py, zmq_synth_server.py]
2016-11-29 fixed typos in pin definitions for beaglebone control..
    [io_client.py, zmq_io_server.py]
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2016-11-30 bugfixes to gpio and synth clients
    [io_client.py, synth_client.py]
2016-11-30 cleaned up pru code a little, not working yet on debian 8/linux 4.4 ...
    [adc_bbone_init.py, adc_shm.h, adc_to_socket.c]
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2016-12-03 disable mosi on ad9864 after initialization to avoid contention
    [adc_bbone_init.py, adc_to_socket.c, vna_io_commands.py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]
2016-12-04 added divider to output of clock buffer to avoid overloading adc fref...
    [clk_lo_buffer.kicad_pcb, clk_lo_buffer.sch]
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2016-12-11 fixed synth output between 3.55 GHz and 7.1 GHz..
    [adc_bbone_init.py, synth_bbone.py, synth_client.py]
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2017-02-01 fixed i/q swap in ad9864 samples
    [adc_client.py, vna_driver.py, vna_io_commands.py]
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2017-02-20 added correction for drift between rf and lo synth reference oscillators
    [adc_client.py, vna_driver.py]
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2017-06-27 .. more demod r0 layout, all nets connected
    [vna_demod.kicad_pcb]
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2017-06-29 removed unnecessary dc blocking caps on demod synth
    [lo_synth.sch, vna_demod.kicad_pcb, vna_rf.kicad_pcb]
2017-06-30 final cleanup of vna r0 pcbs, ordered boards
    [clock_distro.sch, conn_power.sch, demod.sch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]
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2017-07-07 vna control cape layout - all nets connected
    [connectors.sch, vna_control.kicad_pcb]
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2017-07-31 don't enable PDRefOut on ad9577, fix synth ref clock calculation
    [clk_synth_bbone.py]
2017-08-01 add support for bitbang spi without miso, fixes to lmx2594 driver
    [bbone_spi_bitbang.py, synth_bbone.py]
2017-08-02 fixed filter bank path selection for frequencies below 2.5 GHz, vna r0 rf board appears to work
    [bbone_spi_bitbang.py, synth_bbone.py]
2017-08-02 add if filter component values to vna_control, fix port control line swap on vna_rf board, switch TPS2041B amp 5v switch ~enable to pullup
    [clock_gen.sch, port_switch.sch, power.sch]
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2017-08-06 fixed LTC2630 DAC driver for MAAM-011100 VGA
    [synth_bbone.py, zmq_synth_server.py]
2017-08-06 fixed feedback network on vga vctrl op amp
    [rf_synth.sch]
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2017-08-18 bugfixes to vna driver code for vna r0
    [synth_bbone.py, zmq_io_server.py, zmq_synth_server.py]
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2017-08-22 bugfixes to output power leveling
    [synth_bbone.py, synth_client.py, vna_driver.py]
2017-08-22 beaglebone side bugfixes to output power leveling
    [zmq_synth_server.py]
2017-08-26 fixed I/Q sample swap on AD9864 reader... VNA measurements now looking decent
    [adc_client.py, vna_driver.py]
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2017-09-01 fixed sweep collection for LMR16, tested LMR16 cal
    [vna_driver.py]
2017-09-10 added TRL calibration boards for oshpark 4 layer microstrip and amphenol 901-10512-3 connectors
    [trl_line.kicad_pcb, trl_line.sch, trl_reflect.kicad_pcb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]
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2017-09-27 switched to differential clock for synth ref, eliminated if buffer amp, fixed up power nets
    [clock_gen.sch, control.sch, demod.sch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]
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2018-04-16 work on demod - added fixed attenuator to ref path, fixed bridge symbol and footprint
    [adrf5020_breakout.kicad_pcb, couplers.sch, demod.sch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]
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2018-05-20 added missing schematic values
    [conn_front.sch, couplers.sch, demod.sch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]
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2018-07-01 added missing demod schematics
    [lo_split.sch, power_conn.sch]
2018-07-15 add mapping of pins for vna r1 control board, note errata from r1 in schematic
    [control.sch]
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2018-07-27 fix MAAM-011100 bias voltage divider and LD39100PUR regulator adjust circuit on vna_r1_synth. thanks Santiago!
    [conn_power.sch, demod.sch, power_conn.sch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]
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2018-08-30 fix gpio0 base address, enable gpio clks
    [mmap_gpio.py]
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2018-09-23 added command to vna drivers to switch on adc fixed attenuation
    [adc_bbone_init.py, vna_io_commands.py, zmq_io_server.py]
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2019-09-02 started vna_mm library, created power sequencing breakout schematic, added monitoring of negative voltage rails to vna mm synth
    [amp_bias.sch, sequencing_ltc2937.kicad_pcb, sequencing_ltc2937.sch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]
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2019-09-07 layout on sequencer, fix QFN28 paste mask
    [amp_bias.sch, sequencing_ltc2937.kicad_pcb, sequencing_ltc2937.sch]
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2019-10-01 added values for divider resistors for negative voltage monitoring, generated interactive BOMs for maam-011109 bias and sequencing breakout boards
    [amp_bias.sch, amp_vc_control.sch, lowband.sch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]
2019-10-19 fixed mirrored 3.3V regulator on sequencer board, created and assigned footprints for synth
    [amp_bias.sch, amp_vc_control.sch, bandselect_att.sch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]
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2019-11-06 added input overvoltage, undervoltage, and reverse polarity protection
    [power_conn.sch, ref_sel.sch, vna_mm_ref.sch]
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2019-12-22 fix vna mm synth erc errors
    [amp_bias.sch, bandselect_att.sch, conn_power.sch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]
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2020-07-07 commit before fixing dout1/dx0/dx1 interleaving of adc3222 output
    [ddr_test.py, ecp5_evn.py, main.c]
2020-07-08 adc reading somewhat works, failing sine wave test pattern
    [ddr_test.py, ecp5_evn.py, main.c]
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2020-07-09 soc no longer skips samples when writing adc samples to fifo
    [ddr_test.py, ecp5_evn.py, main.c]
2020-07-11 save ADC samples to sram, still skipping writes..
    [ddr_test.py, ecp5_evn.py, main.c]
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2020-07-13 invalidated cpu cache prior to reading from shared memory to fix skipped samples
    [ddr_test.py, ecp5_evn.py, main.c]
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2021-01-24 fixed maam-011101 eval board pinout, started bringup of ecp5 board
    [maam_011101.kicad_pcb, maam_011101.kicad_sch, power.kicad_sch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]
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2021-08-22 added aux high speed io connector, fixed hierarchical buses
    [ctrl_power.kicad_sch, digital_control.kicad_sch, ecp_io.kicad_sch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]
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2021-09-24 added worksheet calculating power supply loads and sequencing on the mm synth
    [mm_synth_power_supply_worksheet.ods]
2021-09-25 added missing synth files
    [ecp_aux_usb.kicad_sch, mm_synth.kicad_pcb, panel.kicad_sch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]
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

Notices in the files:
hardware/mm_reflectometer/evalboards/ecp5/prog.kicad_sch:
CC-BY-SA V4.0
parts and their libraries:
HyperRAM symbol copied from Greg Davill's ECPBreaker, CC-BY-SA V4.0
